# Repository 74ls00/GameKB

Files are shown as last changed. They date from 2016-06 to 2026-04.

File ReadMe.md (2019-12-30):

[Форум проекта](https://forum.geekboards.ru/viewtopic.php?t=13140)

------------------------------------------------------------------------------------

Easy AVR USB Keyboard Firmware Keymapper 
прошивка и графический конфигурфтор клавиш.

https://github.com/74ls00/GameKB_fw

Полная версия клавиатуры.
  
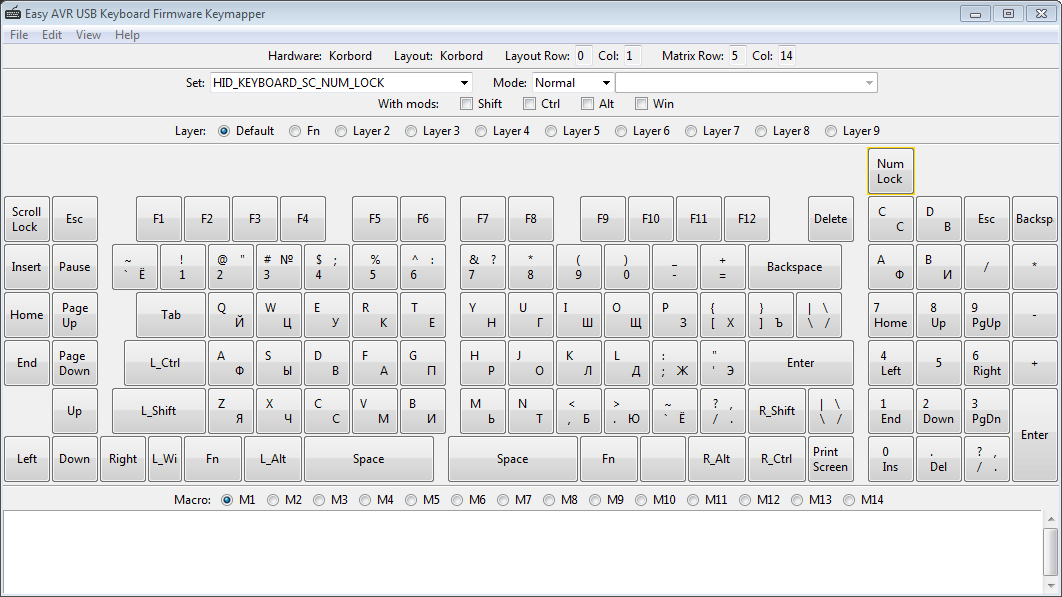
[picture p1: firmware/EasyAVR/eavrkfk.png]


------------------------------------------------------------------------------------

tmk_keyboard \keyboard\korbord прошивка контролера 6KRO, готов только нумпад.

https://github.com/74ls00/GameKB_tmk

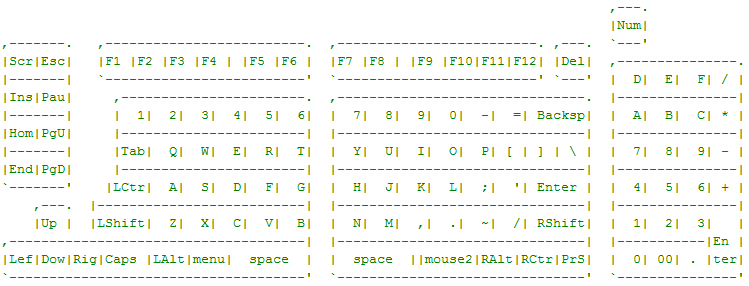
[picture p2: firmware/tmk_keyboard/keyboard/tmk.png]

------------------------------------------------------------------------------------

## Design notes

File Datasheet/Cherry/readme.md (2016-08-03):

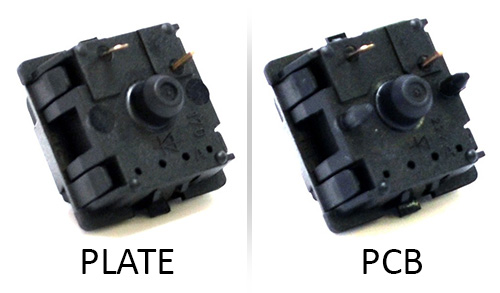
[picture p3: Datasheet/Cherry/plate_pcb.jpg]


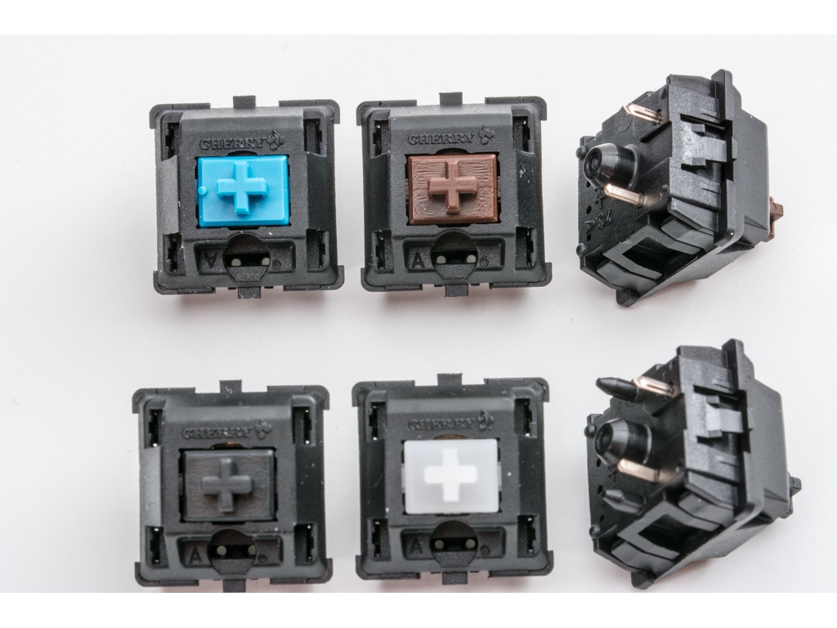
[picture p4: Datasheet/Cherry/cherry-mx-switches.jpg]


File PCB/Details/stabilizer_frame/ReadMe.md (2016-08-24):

Планка крепления Costar стабилизатора.

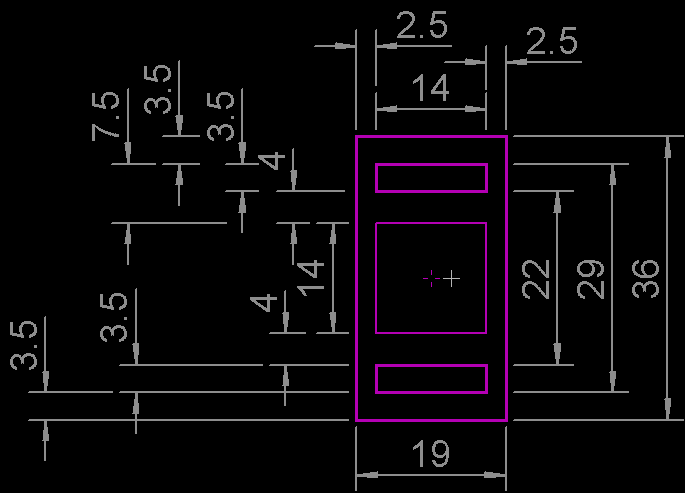
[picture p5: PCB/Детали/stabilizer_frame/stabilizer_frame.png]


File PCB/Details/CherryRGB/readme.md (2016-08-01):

### Модификация переключателя Cherry MX для RGB светодиода.
-----------------------------------------------------------
Снять крышку.

Высверлить углы (жёлтая точка).

Вырезать маленьким ножом для бумаге сначала снаружи, потом перерезав перемычку вы резать через просверленные отверстия(по оранжевой линии).

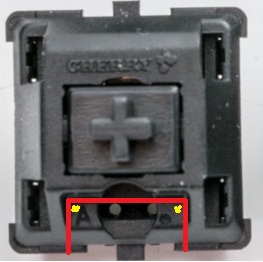
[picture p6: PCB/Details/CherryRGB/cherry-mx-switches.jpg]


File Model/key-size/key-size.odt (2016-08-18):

Ряды | Размеры | 1 x 1 | 1 x 1.25 | 1x1.5 | 1 x 1.75 | 1 x 2 | 1x2.25 | 1x2.75 | 1x6.25 | 2 x 1

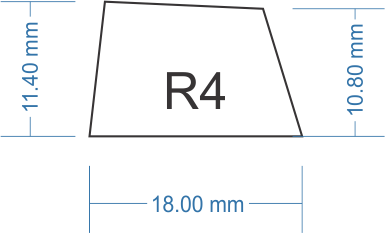
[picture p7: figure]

| | Esc F1-F12 PrtScr ScrLck Break ~ - = 1 2 3 4 5 6 7 8 9 0 Insert Home PgUp NumLock Num/ Num * Num- | | | | Backspace

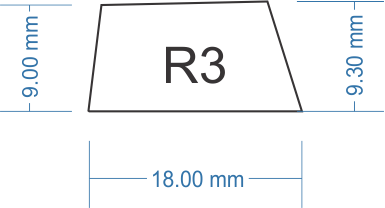
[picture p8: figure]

| | Q W E R T Y U I O P { } Del End PgDn Num7 Num8 Num9 | | Tab \ | | | | | | Num+

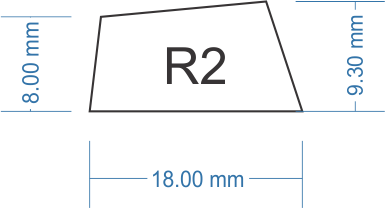
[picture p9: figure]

| | A S D F G H J K L ; ' Num4 Num5 Num6 Num. | | | CapsLock | | Enter

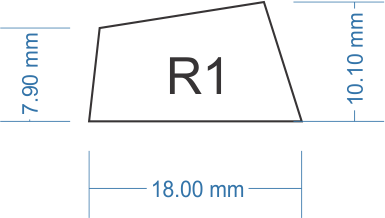
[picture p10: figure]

| | Z X C V B N M , . / Up Left Right Down Num1 Num2 Num3 | Ctrl Win Alt noWin Fn | | | Num0 | LShift | RShift | | Num_Enter
| | | | | | | | | Space

(красный10 голубой1)

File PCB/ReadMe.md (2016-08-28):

NumPad-MUSB - плата нумпада . завершено.

keyBoard_B - правая плата . завершено.

keyBoard_A_GPad - левая плата

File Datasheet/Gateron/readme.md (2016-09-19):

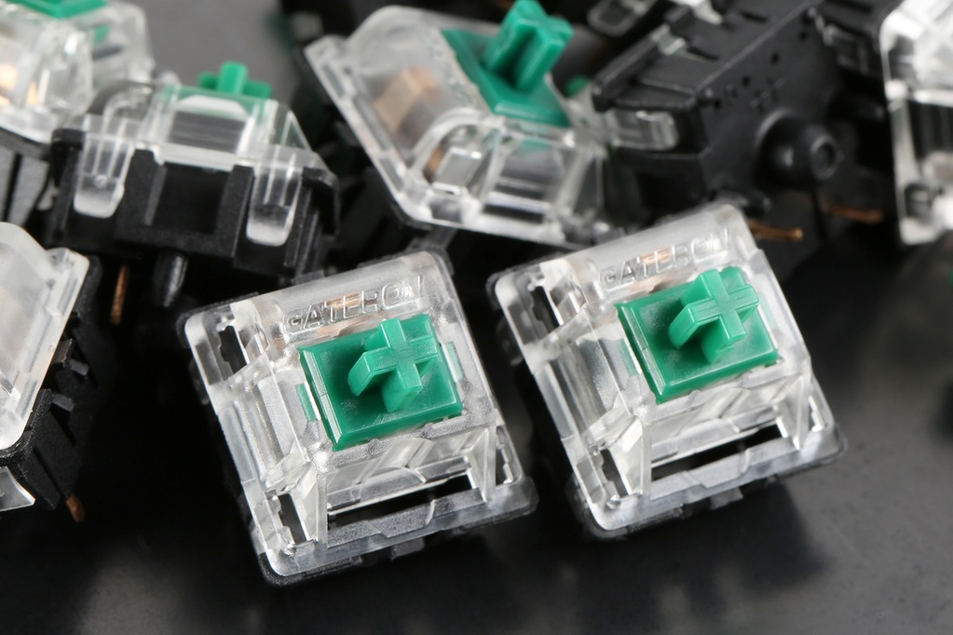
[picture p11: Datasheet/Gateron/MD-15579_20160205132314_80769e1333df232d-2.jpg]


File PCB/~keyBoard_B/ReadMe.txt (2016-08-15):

разводка завершена, остались корректировки.
отверстия есть.
таблица готова в корне help.py

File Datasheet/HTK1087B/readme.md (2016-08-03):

Схема подключения контролера HTK1087B

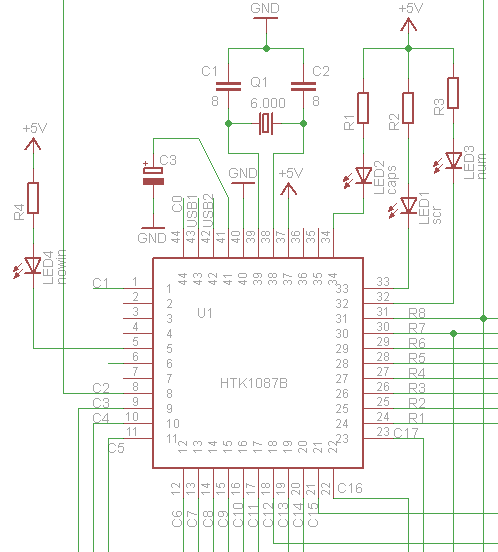
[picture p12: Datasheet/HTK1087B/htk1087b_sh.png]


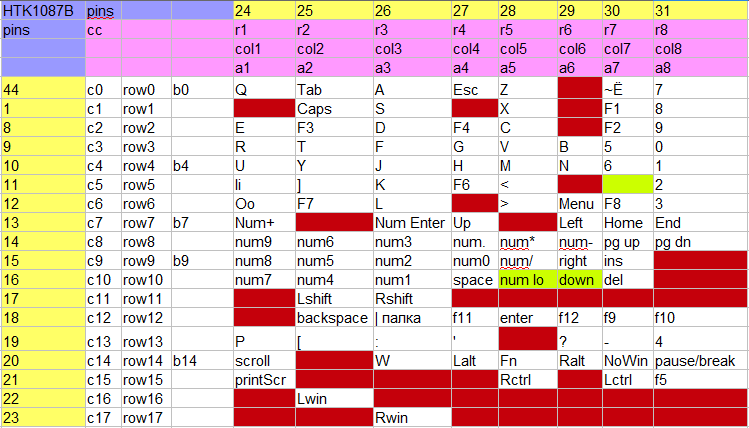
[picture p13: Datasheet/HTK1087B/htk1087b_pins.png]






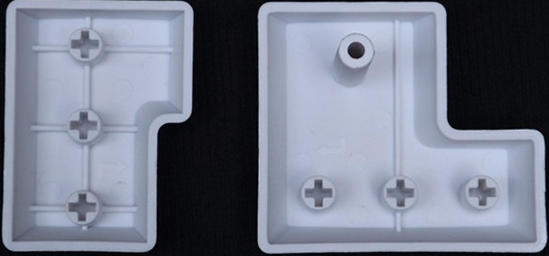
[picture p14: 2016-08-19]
PCB/Details/enter/b.bmp

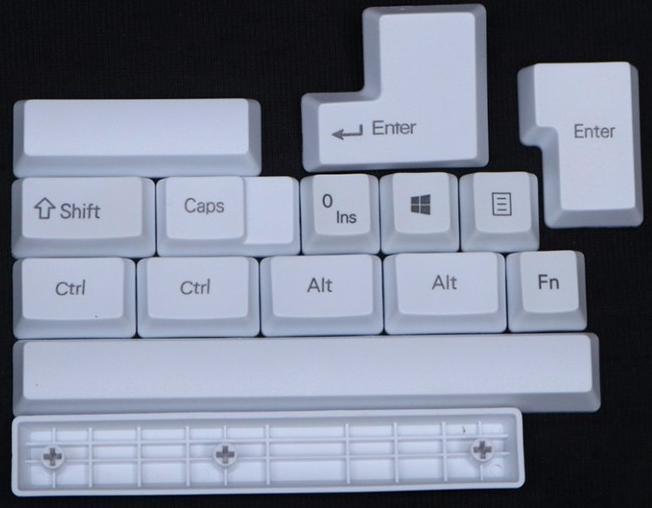
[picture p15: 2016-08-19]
PCB/Details/enter/t.bmp

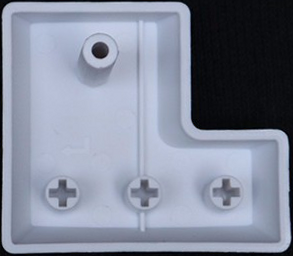
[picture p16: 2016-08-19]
PCB/Детали/enter/b1.bmp

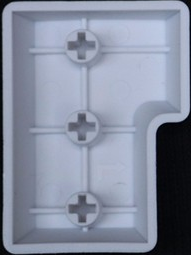
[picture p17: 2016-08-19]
PCB/Детали/enter/b0.bmp

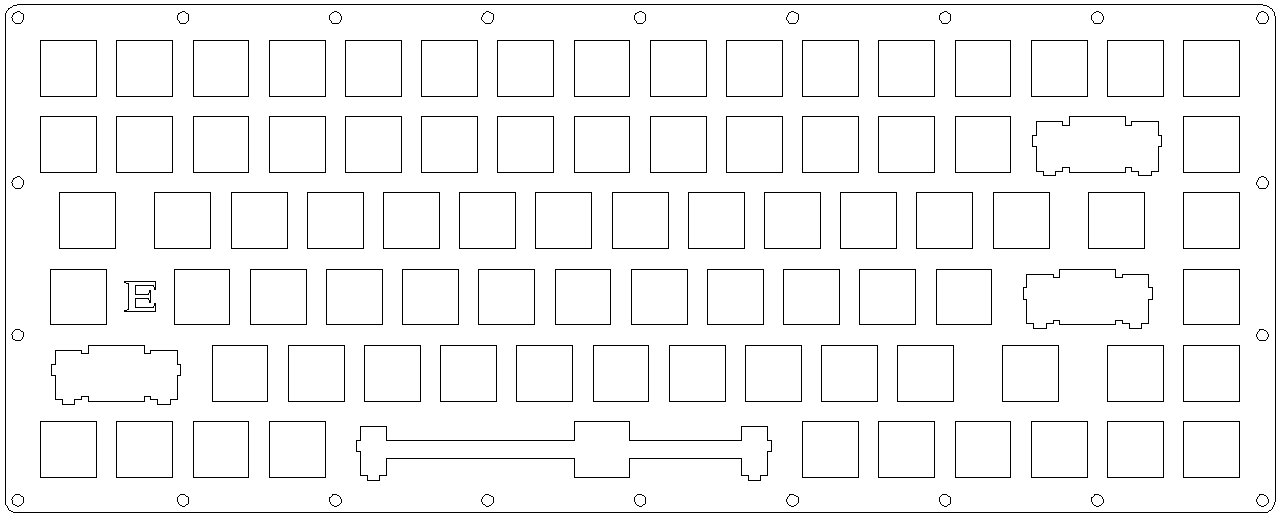
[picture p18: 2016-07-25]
PCB/Детали/frame/UQaYK0l.bmp

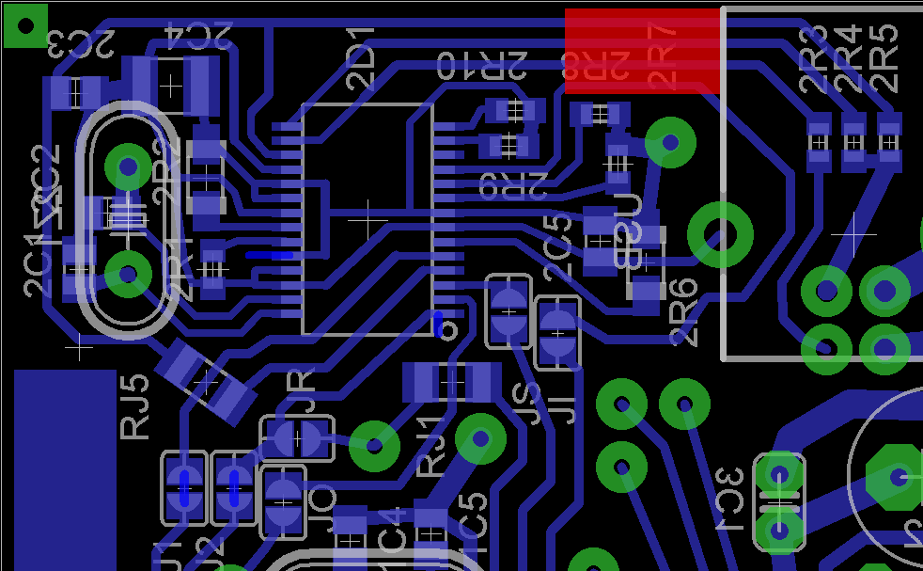
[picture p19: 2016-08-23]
PCB/Controller/png/1_cr.png2.png

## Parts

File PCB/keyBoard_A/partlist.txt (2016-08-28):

Partlist

Exported from keyBoard_A.brd at 2016-08-28 15:22:43

EAGLE Version 6.3.0 Copyright (c) 1988-2012 CadSoft

Assembly variant: 

Part     Value          Package      Library     Position (mil)        Orientation

1D1      74HC138N       DIL16        detali_main (6725 4350)           R0
1D2      74HC04N        DIL14        detali_main (1775 1650)           R90
C17      100n           C0805        rcl         (6775 4312.5)         MR90
C18      100n           C0805        rcl         (1725 1362.5)         MR270
D1       LL4148         SOD80C       detali      (1800 4550)           R270
D2       LL4148         SOD80C       detali      (2725 4625)           R270
D3       LL4148         SOD80C       detali      (1412.5 4287.5)       R90
D4       LL4148         SOD80C       detali      (2112.5 4250)         R0
D5       LL4148         SOD80C       detali      (1950 3525)           R90
D6       LL4148         SOD80C       detali      (2525 3075)           R0
D7       LL4148         SOD80C       detali      (2000 2750)           R90
D8       LL4148         SOD80C       detali      (2750 2775)           R90
D9       LL4148         SOD80C       detali      (2850 1850)           R90
D10      LL4148         SOD80C       detali      (1437.5 1462.5)       R90
D11      LL4148         SOD80C       detali      (2912.5 1562.5)       R0
D12      LL4148         SOD80C       detali      (4525 1375)           R0
D13      LL4148         SOD80C       detali      (4512.5 4450)         R270
D14      LL4148         SOD80C       detali      (4775 4568.625)       R270
D15      LL4148         SOD80C       detali      (5512.5 4575)         R270
D16      LL4148         SOD80C       detali      (6225 4600)           R225
D17      LL4148         SOD80C       detali      (7300 4537.5)         R270
D18      LL4148         SOD80C       detali      (7812.5 4487.5)       R180
D19      LL4148         SOD80C       detali      (4512.5 4000)         R90
D20      LL4148         SOD80C       detali      (5237.5 3987.5)       R90
D21      LL4148         SOD80C       detali      (6075 3950)           R0
D22      LL4148         SOD80C       detali      (6850 3962.5)         R0
D23      LL4148         SOD80C       detali      (7443.75 3987.5)      R90
D24      LL4148         SOD80C       detali      (7612.5 3962.5)       R180
D25      LL4148         SOD80C       detali      (4325 3237.5)         R90
D26      LL4148         SOD80C       detali      (5250 3200)           R90
D27      LL4148         SOD80C       detali      (6000 3200)           R90
D28      LL4148         SOD80C       detali      (6750 3200)           R90
D29      LL4148         SOD80C       detali      (7500 3225)           R90
D30      LL4148         SOD80C       detali      (8037.5 2700)         R0
D31      LL4148         SOD80C       detali      (4225 2475)           R90
D32      LL4148         SOD80C       detali      (5250 2450)           R90
D33      LL4148         SOD80C       detali      (6000 2450)           R90
D34      LL4148         SOD80C       detali      (6750 2450)           R90
D35      LL4148         SOD80C       detali      (7500 2475)           R90
D36      LL4148         SOD80C       detali      (8037.5 1950)         R0
D37      LL4148         SOD80C       detali      (3225 1943.75)        R90
D38      LL4148         SOD80C       detali      (4537.5 1650)         R180
D39      LL4148         SOD80C       detali      (5275 1700)           R180
D40      LL4148         SOD80C       detali      (6087.5 1700)         R90
D41      LL4148         SOD80C       detali      (6850 1700)           R90
D42      LL4148         SOD80C       detali      (7537.5 1475)         R180
D43      LL4148         SOD80C       detali      (5275 1462.5)         R90
D44      LL4148         SOD80C       detali      (6568.75 1250)        R90
D45      LL4148         SOD80C       detali      (7325 1250)           R90
D46      LL4148         SOD80C       detali      (7362.5 906.25)       R90
D47      LL4148         SOD80C       detali      (1800 1225)           R0
D48      LL4148         SOD80C       detali      (1587.5 1206.25)      R0
D88      LL4148         SOD80C       detali      (3787.5 3987.5)       R0
J1       J              R1206W       detali_main (7812.5 4350)         R90
J2       J              R1206W       detali_main (7325 2750)           R90
J3       J              R1206W       detali_main (7350 2025)           R270
J4       J              R1206W       detali_main (6575 3525)           R270
J5       J              R1206W       detali_main (6562.5 2750)         R90
J6       J              R1206W       detali_main (6587.5 2025)         R270
J7       J              R1206W       detali_main (5337.5 3712.5)       R270
J8       J              R1206W       detali_main (5825 2750)           R90
J9       J              R1206W       detali_main (5850 2025)           R90
J10      J              R1206W       detali_main (4312.5 3525)         R270
J11      J              R1206W       detali_main (5075 2750)           R90
J12      J              R1206W       detali_main (5100 2025)           R90
J13      J              R1206W       detali_main (3912.5 3525)         R270
J14      J              R1206W       detali_main (4225 2750)           R90
J15      J              R1206W       detali_main (4250 2025)           R90
J16      J              R1206W       detali_main (2450 3775)           R270
J17      J              R1206W       detali_main (2687.5 2975)         R90
J18      J              R1206W       detali_main (1687.5 2237.5)       R90
J19      J              R1206W       detali_main (1737.5 3787.5)       R315
J20      J              R1206W       detali_main (1812.5 3050)         R90
J21      J              R1206W       detali_main (1450 2975)           R0
J22      J              R1206W       detali_main (5325 4137.5)         R0
J23      J              R1206W       detali_main (2600 2350)           R0
J24      J              R1206W       detali_main (6162.5 4475)         R180
J25      J              R1206W       detali_main (5325 4437.5)         R180
J26      J              R1206W       detali_main (6650 4925)           R90
J27      J              R1206W       detali_main (6212.5 4200)         R0
J28      J              R1206W       detali_main (6212.5 4287.5)       R0
J29      J              R1206W       detali_main (6162.5 4387.5)       R0
J30      J              R1206W       detali_main (5325 4237.5)         R0
J31      J              R1206W       detali_main (5325 4337.5)         R0
J32      J              R1206W       detali_main (2062.5 4750)         R270
J33      J              R1206W       detali_main (2825 4625)           R270
J34      J              R1206W       detali_main (3487.5 5075)         R270
J35      J              R1206W       detali_main (4687.5 4162.5)       R0
J36      J              R1206W       detali_main (4687.5 4250)         R0
J37      J              R1206W       detali_main (4687.5 4337.5)       R0
J38      J              R1206W       detali_main (3937.5 4187.5)       R0
J39      J              R1206W       detali_main (3937.5 4287.5)       R0
J40      J              R1206W       detali_main (3937.5 4387.5)       R0
J41      J              R1206W       detali_main (6762.5 4925)         R90
J42      J              R1206W       detali_main (1387.5 3237.5)       R180
J43      J              R1206W       detali_main (6537.5 4925)         R90
J44      J              R1206W       detali_main (2037.5 900)          R90
J45      J              R1206W       detali_main (1450 3062.5)         R180
J46      J              R1206W       detali_main (2850 2412.5)         R0
J47      J              R1206W       detali_main (3800 3525)           R90
J48      J              R1206W       detali_main (2637.5 4525)         R135
J49      J              R1206W       detali_main (2025 3987.5)         R270
J50      J              R1206W       detali_main (2600 2262.5)         R0
J51      J              R1206W       detali_main (2850 2312.5)         R0
J52      J              R1206W       detali_main (2600 2175)           R0
J53      J              R1206W       detali_main (2850 2212.5)         R0
J54      J              R1206W       detali_main (2600 2087.5)         R0
J55      J              R1206W       detali_main (2850 2112.5)         R0
J56      J              R1206W       detali_main (2600 2000)           R0
J57      J              R1206W       detali_main (2850 2012.5)         R0
JA1                     SJ           detali_main (1462.5 4575)         R90
JA2                     SJ           detali_main (2450 4625)           R90
JA3                     SJ           detali_main (1825 3875)           R90
JA4                     SJ           detali_main (2575 3875)           R90
JA5                     SJ           detali_main (1675 3075)           R90
JA6                     SJ           detali_main (2200 3262.5)         R0
JA7                     SJ           detali_main (1587.5 2275)         R90
JA8                     SJ           detali_main (2175 2475)           R0
JA9                     SJ           detali_main (2187.5 1450)         R0
JA10                    SJ           detali_main (1912.5 600)          R180
JA11                    SJ           detali_main (2450 550)            R90
JA12                    SJ           detali_main (3200 550)            R90
JA13                    SJ           detali      (3900 4600)           R90
JA14                    SJ           detali      (4650 4600)           R90
JA15                    SJ           detali      (5125 4750)           R0
JA16                    SJ           detali      (5850 4700)           R0
JA17                    SJ           detali      (6900 4725)           R0
JA18                    SJ           detali      (7675 4750)           R0
JA19                    SJ           detali      (4200 3550)           R90
JA20                    SJ           detali      (4950 3550)           R90
JA21                    SJ           detali      (5700 3550)           R90
JA22                    SJ           detali      (6425 3500)           R90
JA23                    SJ           detali      (6925 3675)           R0
JA24                    SJ           detali      (8075 3562.5)         R90
JA25                    SJ           detali      (4000 2775)           R90
JA26                    SJ           detali      (4950 2775)           R90
JA27                    SJ           detali      (5675 2775)           R90
JA28                    SJ           detali      (6425 2775)           R90
JA29                    SJ           detali      (7200 2775)           R90
JA30                    SJ           detali      (7775 2700)           R90
JA31                    SJ           detali      (3900 2050)           R90
JA32                    SJ           detali      (4950 2050)           R90
JA33                    SJ           detali      (5700 2050)           R90
JA34                    SJ           detali      (6450 2050)           R90
JA35                    SJ           detali      (7200 2050)           R90
JA36                    SJ           detali      (7762.5 1975)         R90
JA37                    SJ           detali      (3950 1337.5)         R90
JA38                    SJ           detali      (4975 1362.5)         R90
JA39                    SJ           detali      (5787.5 1300)         R90
JA40                    SJ           detali      (6475 1362.5)         R90
JA41                    SJ           detali      (7225 1362.5)         R90
JA42                    SJ           detali      (7975 1350)           R45
JA43                    SJ           detali_main (3962.5 550)          R90
JA44                    SJ           detali      (4350 543.75)         R90
JA45                    SJ           detali      (5575 543.75)         R90
JA46                    SJ           detali      (6812.5 562.5)        R90
JA88                    SJ           detali      (3362.5 3475)         R90
JB1                     SJ           detali      (1725 4650)           R270
JB2                     SJ           jumper      (2725 4800)           MR0
JB3                     SJ           detali      (1437.5 4012.5)       R180
JB4                     SJ           detali_main (2187.5 4012.5)       R135
JB5                     SJ           jumper      (2000 3350)           MR270
JB6                     SJ           detali_main (2487.5 3162.5)       R180
JB7                     SJ           detali_main (2000 2587.5)         R90
JB8                     SJ           detali_main (2750 2562.5)         R90
JB9                     SJ           detali_main (2750 1550)           R90
JB10                    SJ           detali_main (1437.5 712.5)        R180
JB11                    SJ           detali_main (2725 725)            R0
JB12                    SJ           detali_main (3475 725)            R0
JB13                    SJ           detali_main (4175 4775)           R0
JB14                    SJ           jumper      (4925 4800)           MR0
JB15                    SJ           jumper      (5675 4775)           MR0
JB16                    SJ           detali_main (6375 4675)           R270
JB17                    SJ           detali_main (7225 4650)           R270
JB18                    SJ           detali      (8000 4637.5)         R270
JB19                    SJ           detali      (4500 3800)           R90
JB20                    SJ           detali      (5237.5 3812.5)       R90
JB21                    SJ           detali      (6000 3800)           R90
JB22                    SJ           detali      (6750 3850)           R90
JB23                    SJ           detali      (7487.5 3762.5)       R90
JB24                    SJ           detali      (7687.5 3662.5)       R90
JB25                    SJ           detali      (4325 3025)           R90
JB26                    SJ           detali      (5250 3025)           R90
JB27                    SJ           detali      (6000 3025)           R90
JB28                    SJ           detali      (6750 3025)           R90
JB29                    SJ           detali      (7500 3050)           R90
JB30                    SJ           detali      (7987.5 2850)         R270
JB31                    SJ           detali      (4225 2300)           R90
JB32                    SJ           detali      (5250 2275)           R90
JB33                    SJ           detali      (6000 2275)           R90
JB34                    SJ           detali      (6750 2275)           R90
JB35                    SJ           detali      (7500 2300)           R90
JB36                    SJ           detali      (7987.5 2087.5)       R270
JB37                    SJ           detali      (3537.5 1287.5)       R180
JB38                    SJ           detali      (4687.5 1462.5)       R180
JB39                    SJ           detali      (5437.5 1462.5)       R180
JB40                    SJ           detali      (6087.5 1512.5)       R90
JB41                    SJ           detali      (6850 1525)           R90
JB42                    SJ           detali      (7700 1437.5)         R90
JB43                    SJ           detali      (4237.5 725)          R0
JB44                    SJ           detali      (5000 725)            R0
JB45                    SJ           detali      (5850 725)            R0
JB46                    SJ           detali      (7362.5 737.5)        R90
JB88                    SJ           detali      (3725 3725)           R0
R1                      R1206W       rcl         (7075 4312.5)         MR0
R2       10k            R1206W       rcl         (2862.5 4312.5)       MR270
R3       10k            R1206W       rcl         (2050 1350)           MR90
R4       10k            R0805        rcl         (1812.5 1337.5)       MR90
R5       10k            R1206W       rcl         (2037.5 1112.5)       MR225
R6       10k            R1206W       rcl         (2050 1550)           MR90
R7       10k            R1206W       rcl         (1525 1450)           MR90
R8       10k            R0805        rcl         (3331.25 2150)        MR90
S1       Scroll Lock    CHERRY-MX-4P cherrymx    (1675 4875)           R180
S2       ESC            CHERRY-MX-4P cherrymx    (2425 4875)           R180
S3       Ins            CHERRY-MX-4P cherrymx    (1675 4125)           R180
S4       Pause          CHERRY-MX-4P cherrymx    (2425 4125)           R180
S5       Home           CHERRY-MX-4P cherrymx    (1675 3375)           R180
S6       PageUp         CHERRY-MX-4P cherrymx    (2425 3375)           R180
S7       End            CHERRY-MX-4P cherrymx    (1675 2625)           R180
S8       PageDown       CHERRY-MX-4P cherrymx    (2425 2625)           R180
S9       Up             CHERRY-MX-4P cherrymx    (2425 1575)           R180
S10      Left           CHERRY-MX-4P cherrymx    (1675 825)            R180
S11      Down           CHERRY-MX-4P cherrymx    (2425 825)            R180
S12      Right          CHERRY-MX-4P cherrymx    (3175 825)            R180
S13      F1             CHERRY-MX-4P cherrymx    (3875 4875)           R180
S14      F2             CHERRY-MX-4P cherrymx    (4625 4875)           R180
S15      F3             CHERRY-MX-4P cherrymx    (5375 4875)           R180
S16      F4             CHERRY-MX-4P cherrymx    (6125 4875)           R180
S17      F5             CHERRY-MX-4P cherrymx    (7175 4875)           R180
S18      F6             CHERRY-MX-4P cherrymx    (7925 4875)           R180
S19      1              CHERRY-MX-4P cherrymx    (4175 3825)           R180
S20      2              CHERRY-MX-4P cherrymx    (4925 3825)           R180
S21      3              CHERRY-MX-4P cherrymx    (5675 3825)           R180
S22      4              CHERRY-MX-4P cherrymx    (6425 3825)           R180
S23      5              CHERRY-MX-4P cherrymx    (7175 3825)           R180
S24      6              CHERRY-MX-4P cherrymx    (7925 3825)           R180
S25      TAB            CHERRY-MX-4P cherrymx    (3975 3075)           R180
S26      Q              CHERRY-MX-4P cherrymx    (4925 3075)           R180
S27      W              CHERRY-MX-4P cherrymx    (5675 3075)           R180
S28      E              CHERRY-MX-4P cherrymx    (6425 3075)           R180
S29      R              CHERRY-MX-4P cherrymx    (7175 3075)           R180
S30      T              CHERRY-MX-4P cherrymx    (7925 3075)           R180
S31      LCtrl          CHERRY-MX-4P cherrymx    (3875 2325)           R180
S32      A              CHERRY-MX-4P cherrymx    (4925 2325)           R180
S33      S              CHERRY-MX-4P cherrymx    (5675 2325)           R180
S34      D              CHERRY-MX-4P cherrymx    (6425 2325)           R180
S35      F              CHERRY-MX-4P cherrymx    (7175 2325)           R180
S36      G              CHERRY-MX-4P cherrymx    (7925 2325)           R180
S37      L Shift        CHERRY-MX-4P cherrymx    (3800 1575)           R180
S38      Z              CHERRY-MX-4P cherrymx    (4925 1575)           R180
S39      X              CHERRY-MX-4P cherrymx    (5675 1575)           R180
S40      C              CHERRY-MX-4P cherrymx    (6425 1575)           R180
S41      V              CHERRY-MX-4P cherrymx    (7175 1575)           R180
S42      B              CHERRY-MX-4P cherrymx    (7925 1575)           R180
S43      Caps Lock      CHERRY-MX-4P cherrymx    (3937.5 825)          R180
S44      FN1            CHERRY-MX-4P cherrymx    (4700 825)            R180
S44A     Fn1            CHERRY-MX    cherrymx    (4587.5 825)          R180
S45      L_Alt          CHERRY-MX-4P cherrymx    (5537.5 825)          R180
S46      Space          CHERRY-MX-4P cherrymx    (7050 825)            R180
S88      ~?             CHERRY-MX-4P cherrymx    (3425 3825)           R180
SV1                     FE03-1       detali_main (3543.75 4331.25)     R90
SV3                     FE08         detali_main (3043.75 3881.25)     R90

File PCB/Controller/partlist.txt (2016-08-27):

Partlist

Exported from keyBoard_A.brd at 2016-08-28 1:44:59

EAGLE Version 6.3.0 Copyright (c) 1988-2012 CadSoft

Assembly variant: 

Part     Value          Package      Library     Position (mil)        Orientation

1D1      74HC138N       DIL16        detali_main (6600 5150)           R0
1D2      74HC04N        DIL14        detali_main (1650 2450)           R90
C17      100n           C0805        rcl         (6650 5112.5)         MR90
C18      100n           C0805        rcl         (1600 2162.5)         MR270
D1       LL4148         SOD80C       detali      (1675 5350)           R270
D2       LL4148         SOD80C       detali      (2600 5425)           R270
D3       LL4148         SOD80C       detali      (1287.5 5087.5)       R90
D4       LL4148         SOD80C       detali      (1987.5 5050)         R0
D5       LL4148         SOD80C       detali      (1825 4325)           R90
D6       LL4148         SOD80C       detali      (2400 3875)           R0
D7       LL4148         SOD80C       detali      (1875 3550)           R90
D8       LL4148         SOD80C       detali      (2625 3575)           R90
D9       LL4148         SOD80C       detali      (2725 2650)           R90
D10      LL4148         SOD80C       detali      (1287.5 2350)         R90
D11      LL4148         SOD80C       detali      (2787.5 2362.5)       R0
D12      LL4148         SOD80C       detali      (4400 2175)           R0
D13      LL4148         SOD80C       detali      (4387.5 5250)         R270
D14      LL4148         SOD80C       detali      (4650 5368.625)       R270
D15      LL4148         SOD80C       detali      (5387.5 5375)         R270
D16      LL4148         SOD80C       detali      (6100 5400)           R225
D17      LL4148         SOD80C       detali      (7175 5337.5)         R270
D18      LL4148         SOD80C       detali      (7687.5 5275)         R180
D19      LL4148         SOD80C       detali      (4387.5 4800)         R90
D20      LL4148         SOD80C       detali      (5112.5 4787.5)       R90
D21      LL4148         SOD80C       detali      (5950 4750)           R0
D22      LL4148         SOD80C       detali      (6725 4762.5)         R0
D23      LL4148         SOD80C       detali      (7312.5 4762.5)       R90
D24      LL4148         SOD80C       detali      (7487.5 4762.5)       R180
D25      LL4148         SOD80C       detali      (4200 4037.5)         R90
D26      LL4148         SOD80C       detali      (5125 4000)           R90
D27      LL4148         SOD80C       detali      (5875 4000)           R90
D28      LL4148         SOD80C       detali      (6625 4000)           R90
D29      LL4148         SOD80C       detali      (7375 4025)           R90
D30      LL4148         SOD80C       detali      (7912.5 3500)         R0
D31      LL4148         SOD80C       detali      (4100 3275)           R90
D32      LL4148         SOD80C       detali      (5125 3250)           R90
D33      LL4148         SOD80C       detali      (5875 3250)           R90
D34      LL4148         SOD80C       detali      (6625 3250)           R90
D35      LL4148         SOD80C       detali      (7375 3275)           R90
D36      LL4148         SOD80C       detali      (7912.5 2750)         R0
D37      LL4148         SOD80C       detali      (3100 2743.75)        R90
D38      LL4148         SOD80C       detali      (4412.5 2450)         R180
D39      LL4148         SOD80C       detali      (5150 2500)           R180
D40      LL4148         SOD80C       detali      (5962.5 2500)         R90
D41      LL4148         SOD80C       detali      (6725 2500)           R90
D42      LL4148         SOD80C       detali      (7412.5 2275)         R180
D43      LL4148         SOD80C       detali      (5150 2262.5)         R90
D44      LL4148         SOD80C       detali      (6443.75 2050)        R90
D45      LL4148         SOD80C       detali      (7200 2050)           R90
D46      LL4148         SOD80C       detali      (7237.5 1675)         R90
D47      LL4148         SOD80C       detali      (1337.5 2062.5)       R0
D48      LL4148         SOD80C       detali      (1337.5 2150)         R180
D88      LL4148         SOD80C       detali      (3662.5 4787.5)       R0
J1       J              R1206W       detali_main (7687.5 5150)         R90
J2       J              R1206W       detali_main (7200 3550)           R90
J3       J              R1206W       detali_main (7225 2825)           R270
J4       J              R1206W       detali_main (6450 4325)           R270
J5       J              R1206W       detali_main (6437.5 3550)         R90
J6       J              R1206W       detali_main (6462.5 2825)         R270
J7       J              R1206W       detali_main (5212.5 4512.5)       R270
J8       J              R1206W       detali_main (5700 3550)           R90
J9       J              R1206W       detali_main (5725 2825)           R90
J10      J              R1206W       detali_main (4187.5 4325)         R270
J11      J              R1206W       detali_main (4950 3550)           R90
J12      J              R1206W       detali_main (4975 2825)           R90
J13      J              R1206W       detali_main (3787.5 4325)         R270
J14      J              R1206W       detali_main (4100 3550)           R90
J15      J              R1206W       detali_main (4125 2825)           R90
J16      J              R1206W       detali_main (2325 4575)           R270
J17      J              R1206W       detali_main (2562.5 3775)         R90
J18      J              R1206W       detali_main (1562.5 3037.5)       R90
J19      J              R1206W       detali_main (1612.5 4587.5)       R315
J20      J              R1206W       detali_main (1687.5 3850)         R90
J21      J              R1206W       detali_main (1325 3775)           R0
J22      J              R1206W       detali_main (5200 4937.5)         R0
J23      J              R1206W       detali_main (2475 3150)           R0
J24      J              R1206W       detali_main (6037.5 5275)         R180
J25      J              R1206W       detali_main (5200 5237.5)         R180
J26      J              R1206W       detali_main (6525 5725)           R90
J27      J              R1206W       detali_main (6100 5012.5)         R0
J28      J              R1206W       detali_main (6087.5 5087.5)       R0
J29      J              R1206W       detali_main (6037.5 5187.5)       R0
J30      J              R1206W       detali_main (5200 5037.5)         R0
J31      J              R1206W       detali_main (5200 5137.5)         R0
J32      J              R1206W       detali_main (1937.5 5550)         R270
J33      J              R1206W       detali_main (2700 5425)           R270
J34      J              R1206W       detali_main (3362.5 5875)         R270
J35      J              R1206W       detali_main (4562.5 4962.5)       R0
J36      J              R1206W       detali_main (4562.5 5050)         R0
J37      J              R1206W       detali_main (4562.5 5137.5)       R0
J38      J              R1206W       detali_main (3812.5 4987.5)       R0
J39      J              R1206W       detali_main (3812.5 5087.5)       R0
J40      J              R1206W       detali_main (3812.5 5187.5)       R0
J41      J              R1206W       detali_main (6637.5 5725)         R90
J42      J              R1206W       detali_main (1262.5 4037.5)       R180
J43      J              R1206W       detali_main (6412.5 5725)         R90
J44      J              R1206W       detali_main (1337.5 1975)         R0
J45      J              R1206W       detali_main (1325 3862.5)         R180
J46      J              R1206W       detali_main (2725 3212.5)         R0
J47      J              R1206W       detali_main (3675 4325)           R90
J48      J              R1206W       detali_main (2512.5 5325)         R135
J49      J              R1206W       detali_main (1900 4787.5)         R270
J50      J              R1206W       detali_main (2475 3062.5)         R0
J51      J              R1206W       detali_main (2725 3112.5)         R0
J52      J              R1206W       detali_main (2475 2975)           R0
J53      J              R1206W       detali_main (2725 3012.5)         R0
J54      J              R1206W       detali_main (2475 2887.5)         R0
J55      J              R1206W       detali_main (2725 2912.5)         R0
J56      J              R1206W       detali_main (2475 2800)           R0
J57      J              R1206W       detali_main (2725 2812.5)         R0
JA1                     SJ           detali_main (1337.5 5375)         R90
JA2                     SJ           detali_main (2325 5425)           R90
JA3                     SJ           detali_main (1700 4675)           R90
JA4                     SJ           detali_main (2450 4675)           R90
JA5                     SJ           detali_main (1550 3875)           R90
JA6                     SJ           detali_main (2075 4062.5)         R0
JA7                     SJ           detali_main (1462.5 3075)         R90
JA8                     SJ           detali_main (2050 3275)           R0
JA9                     SJ           detali_main (2062.5 2250)         R0
JA10                    SJ           detali_main (1825 1350)           R90
JA11                    SJ           detali_main (2325 1350)           R90
JA12                    SJ           detali_main (3075 1350)           R90
JA13                    SJ           detali      (3775 5400)           R90
JA14                    SJ           detali      (4525 5400)           R90
JA15                    SJ           detali      (5000 5550)           R0
JA16                    SJ           detali      (5725 5500)           R0
JA17                    SJ           detali      (6775 5525)           R0
JA18                    SJ           detali      (7550 5550)           R0
JA19                    SJ           detali      (4075 4350)           R90
JA20                    SJ           detali      (4825 4350)           R90
JA21                    SJ           detali      (5575 4350)           R90
JA22                    SJ           detali      (6300 4300)           R90
JA23                    SJ           detali      (6800 4475)           R0
JA24                    SJ           detali      (7950 4362.5)         R90
JA25                    SJ           detali      (3875 3575)           R90
JA26                    SJ           detali      (4825 3575)           R90
JA27                    SJ           detali      (5550 3575)           R90
JA28                    SJ           detali      (6300 3575)           R90
JA29                    SJ           detali      (7075 3575)           R90
JA30                    SJ           detali      (7650 3500)           R90
JA31                    SJ           detali      (3775 2850)           R90
JA32                    SJ           detali      (4825 2850)           R90
JA33                    SJ           detali      (5575 2850)           R90
JA34                    SJ           detali      (6325 2850)           R90
JA35                    SJ           detali      (7075 2850)           R90
JA36                    SJ           detali      (7637.5 2775)         R90
JA37                    SJ           detali      (3825 2137.5)         R90
JA38                    SJ           detali      (4850 2162.5)         R90
JA39                    SJ           detali      (5662.5 2100)         R90
JA40                    SJ           detali      (6350 2162.5)         R90
JA41                    SJ           detali      (7100 2162.5)         R90
JA42                    SJ           detali      (7850 2150)           R45
JA43                    SJ           detali_main (3837.5 1350)         R90
JA44                    SJ           detali      (4225 1350)           R90
JA45                    SJ           detali      (5450 1362.5)         R90
JA46                    SJ           detali      (6687.5 1362.5)       R90
JA88                    SJ           detali      (3337.5 4350)         R90
JB1                     SJ           detali      (1600 5450)           R270
JB2                     SJ           jumper      (2600 5600)           MR0
JB3                     SJ           detali      (1312.5 4812.5)       R180
JB4                     SJ           detali_main (2062.5 4812.5)       R135
JB5                     SJ           jumper      (1875 4150)           MR270
JB6                     SJ           detali_main (2362.5 3962.5)       R180
JB7                     SJ           detali_main (1875 3387.5)         R90
JB8                     SJ           detali_main (2625 3362.5)         R90
JB9                     SJ           detali_main (2625 2350)           R90
JB10                    SJ           detali_main (1312.5 1512.5)       R180
JB11                    SJ           detali_main (2600 1525)           R0
JB12                    SJ           detali_main (3350 1525)           R0
JB13                    SJ           detali_main (4050 5575)           R0
JB14                    SJ           jumper      (4800 5600)           MR0
JB15                    SJ           jumper      (5550 5575)           MR0
JB16                    SJ           detali_main (6250 5475)           R270
JB17                    SJ           detali_main (7100 5450)           R270
JB18                    SJ           detali      (7875 5437.5)         R270
JB19                    SJ           detali      (4375 4600)           R90
JB20                    SJ           detali      (5112.5 4612.5)       R90
JB21                    SJ           detali      (5875 4600)           R90
JB22                    SJ           detali      (6625 4650)           R90
JB23                    SJ           detali      (7362.5 4562.5)       R90
JB24                    SJ           detali      (7562.5 4462.5)       R90
JB25                    SJ           detali      (4200 3825)           R90
JB26                    SJ           detali      (5125 3825)           R90
JB27                    SJ           detali      (5875 3825)           R90
JB28                    SJ           detali      (6625 3825)           R90
JB29                    SJ           detali      (7375 3850)           R90
JB30                    SJ           detali      (7862.5 3650)         R270
JB31                    SJ           detali      (4100 3100)           R90
JB32                    SJ           detali      (5125 3075)           R90
JB33                    SJ           detali      (5875 3075)           R90
JB34                    SJ           detali      (6625 3075)           R90
JB35                    SJ           detali      (7375 3100)           R90
JB36                    SJ           detali      (7862.5 2887.5)       R270
JB37                    SJ           detali      (3437.5 2112.5)       R180
JB38                    SJ           detali      (4562.5 2262.5)       R180
JB39                    SJ           detali      (5312.5 2262.5)       R180
JB40                    SJ           detali      (5962.5 2312.5)       R90
JB41                    SJ           detali      (6725 2325)           R90
JB42                    SJ           detali      (7575 2237.5)         R90
JB43                    SJ           detali      (4112.5 1525)         R0
JB44                    SJ           detali      (4875 1525)           R0
JB45                    SJ           detali      (5725 1525)           R0
JB46                    SJ           detali      (7237.5 1512.5)       R90
JB88                    SJ           detali      (3600 4525)           R0
R1                      R1206W       rcl         (6950 5112.5)         MR0
R2       10k            R1206W       rcl         (2737.5 5112.5)       MR270
R3       10k            0603R        rd          (1912.5 2550)         R90
R4       10k            R0805        rcl         (1687.5 2137.5)       MR90
R5       10k            R1206W       rcl         (1887.5 2050)         MR180
R10      10k            0603R        rd          (1400 2450)           R90
R100     10k            0603R        rd          (1400 2650)           R0
S1       Scroll Lock    CHERRY-MX-4P cherrymx    (1550 5675)           R180
S2       ESC            CHERRY-MX-4P cherrymx    (2300 5675)           R180
S3       Ins            CHERRY-MX-4P cherrymx    (1550 4925)           R180
S4       Pause          CHERRY-MX-4P cherrymx    (2300 4925)           R180
S5       Home           CHERRY-MX-4P cherrymx    (1550 4175)           R180
S6       PageUp         CHERRY-MX-4P cherrymx    (2300 4175)           R180
S7       End            CHERRY-MX-4P cherrymx    (1550 3425)           R180
S8       PageDown       CHERRY-MX-4P cherrymx    (2300 3425)           R180
S9       Up             CHERRY-MX-4P cherrymx    (2300 2375)           R180
S10      Left           CHERRY-MX-4P cherrymx    (1550 1625)           R180
S11      Down           CHERRY-MX-4P cherrymx    (2300 1625)           R180
S12      Right          CHERRY-MX-4P cherrymx    (3050 1625)           R180
S13      F1             CHERRY-MX-4P cherrymx    (3750 5675)           R180
S14      F2             CHERRY-MX-4P cherrymx    (4500 5675)           R180
S15      F3             CHERRY-MX-4P cherrymx    (5250 5675)           R180
S16      F4             CHERRY-MX-4P cherrymx    (6000 5675)           R180
S17      F5             CHERRY-MX-4P cherrymx    (7050 5675)           R180
S18      F6             CHERRY-MX-4P cherrymx    (7800 5675)           R180
S19      1              CHERRY-MX-4P cherrymx    (4050 4625)           R180
S20      2              CHERRY-MX-4P cherrymx    (4800 4625)           R180
S21      3              CHERRY-MX-4P cherrymx    (5550 4625)           R180
S22      4              CHERRY-MX-4P cherrymx    (6300 4625)           R180
S23      5              CHERRY-MX-4P cherrymx    (7050 4625)           R180
S24      6              CHERRY-MX-4P cherrymx    (7800 4625)           R180
S25      TAB            CHERRY-MX-4P cherrymx    (3850 3875)           R180
S26      Q              CHERRY-MX-4P cherrymx    (4800 3875)           R180
S27      W              CHERRY-MX-4P cherrymx    (5550 3875)           R180
S28      E              CHERRY-MX-4P cherrymx    (6300 3875)           R180
S29      R              CHERRY-MX-4P cherrymx    (7050 3875)           R180
S30      T              CHERRY-MX-4P cherrymx    (7800 3875)           R180
S31      LCtrl          CHERRY-MX-4P cherrymx    (3750 3125)           R180
S32      A              CHERRY-MX-4P cherrymx    (4800 3125)           R180
S33      S              CHERRY-MX-4P cherrymx    (5550 3125)           R180
S34      D              CHERRY-MX-4P cherrymx    (6300 3125)           R180
S35      F              CHERRY-MX-4P cherrymx    (7050 3125)           R180
S36      G              CHERRY-MX-4P cherrymx    (7800 3125)           R180
S37      L Shift        CHERRY-MX-4P cherrymx    (3675 2375)           R180
S38      Z              CHERRY-MX-4P cherrymx    (4800 2375)           R180
S39      X              CHERRY-MX-4P cherrymx    (5550 2375)           R180
S40      C              CHERRY-MX-4P cherrymx    (6300 2375)           R180
S41      V              CHERRY-MX-4P cherrymx    (7050 2375)           R180
S42      B              CHERRY-MX-4P cherrymx    (7800 2375)           R180
S43      Caps Lock      CHERRY-MX-4P cherrymx    (3812.5 1625)         R180
S44      FN1            CHERRY-MX-4P cherrymx    (4575 1625)           R180
S44A     Fn1            CHERRY-MX    cherrymx    (4462.5 1625)         R180
S45      L_Alt          CHERRY-MX-4P cherrymx    (5412.5 1625)         R180
S46      Space          CHERRY-MX-4P cherrymx    (6925 1625)           R180
S88      ~?             CHERRY-MX-4P cherrymx    (3300 4625)           R180
SV1                     FE03-1       detali_main (3418.75 5131.25)     R90
SV2                     FE03-1       detali_main (262.5 825)           R0
SV3                     FE08         detali_main (2918.75 4681.25)     R90

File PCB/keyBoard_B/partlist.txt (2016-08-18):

Partlist

Exported from keyBoard_B.sch at 2016-08-18 18:13:36

EAGLE Version 6.3.0 Copyright (c) 1988-2012 CadSoft

Assembly variant: 

Part     Value          Device       Package      Library  Sheet

2C1      100n           C-EUC1206    C1206        rcl      1
2C2      100n           C-EUC1206K   C1206K       rcl      1
2D1      74HC138N       74AC138N     DIL16        detali2  1
2D2      74HC04N        74ALS04N     DIL14        detali2  1
2R1      10k            R-EU_R0805   R0805        rcl      1
2R2      10k            R-EU_R0805   R0805        rcl      1
2R3      10k            R-EU_R0805   R0805        rcl      1
2R4      10k            R-EU_R1206W  R1206W       rcl      1
2R5      10k            R-EU_R0805   R0805        rcl      1
2R6      10k            R-EU_R0805   R0805        rcl      1
D49      LL4148         LL4148       SOD80C       detali   1
D50      LL4148         LL4148       SOD80C       detali   1
D51      LL4148         LL4148       SOD80C       detali   1
D52      LL4148         LL4148       SOD80C       detali   1
D53      LL4148         LL4148       SOD80C       detali   1
D54      LL4148         LL4148       SOD80C       detali   1
D55      LL4148         LL4148       SOD80C       detali   1
D56      LL4148         LL4148       SOD80C       detali   1
D57      LL4148         LL4148       SOD80C       detali   1
D58      LL4148         LL4148       SOD80C       detali   1
D59      LL4148         LL4148       SOD80C       detali   1
D60      LL4148         LL4148       SOD80C       detali   1
D61      LL4148         LL4148       SOD80C       detali   1
D62      LL4148         LL4148       SOD80C       detali   1
D63      LL4148         LL4148       SOD80C       detali   1
D64      LL4148         LL4148       SOD80C       detali   1
D64B     LL4148         LL4148       SOD80C       detali   1
D65      LL4148         LL4148       SOD80C       detali   1
D66      LL4148         LL4148       SOD80C       detali   1
D67      LL4148         LL4148       SOD80C       detali   1
D67B     LL4148         LL4148       SOD80C       detali   1
D68      LL4148         LL4148       SOD80C       detali   1
D69      LL4148         LL4148       SOD80C       detali   1
D70      LL4148         LL4148       SOD80C       detali   1
D71      LL4148         LL4148       SOD80C       detali   1
D72      LL4148         LL4148       SOD80C       detali   1
D73      LL4148         LL4148       SOD80C       detali   1
D74      LL4148         LL4148       SOD80C       detali   1
D75      LL4148         LL4148       SOD80C       detali   1
D76      LL4148         LL4148       SOD80C       detali   1
D77      LL4148         LL4148       SOD80C       detali   1
D78      LL4148         LL4148       SOD80C       detali   1
D79      LL4148         LL4148       SOD80C       detali   1
D80      LL4148         LL4148       SOD80C       detali   1
D81      LL4148         LL4148       SOD80C       detali   1
D82      LL4148         LL4148       SOD80C       detali   1
D83      LL4148         LL4148       SOD80C       detali   1
D84      LL4148         LL4148       SOD80C       detali   1
D85      LL4148         LL4148       SOD80C       detali   1
D86      LL4148         LL4148       SOD80C       detali   1
D87      LL4148         LL4148       SOD80C       detali   1
D88      LL4148         LL4148       SOD80C       detali   1
D89      LL4148         LL4148       SOD80C       detali   1
D92      LL4148         LL4148       SOD80C       detali   1
D93      LL4148         LL4148       SOD80C       detali   1
J46                     J            R1206W       detali2  1
J48                     J            R1206W       detali2  1
J49                     J            R1206W       detali2  1
J50                     J            R1206W       detali2  1
J51                     J            R1206W       detali2  1
J52                     J            R1206W       detali2  1
J53                     J            R1206W       detali2  1
J54                     J            R1206W       detali2  1
J55                     J            R1206W       detali2  1
J56                     J            R1206W       detali2  1
J57                     J            R1206W       detali2  1
J58                     J            R1206W       detali2  1
J59                     J            R1206W       detali2  1
J60                     J            R1206W       detali2  1
J61                     J            R1206W       detali2  1
J62                     J            R1206W       detali2  1
J63                     J            R1206W       detali2  1
J64                     J            R1206W       detali2  1
J65                     J            R1206W       detali2  1
J66                     J            R1206W       detali2  1
J67                     J            R1206W       detali2  1
J68                     J            R1206W       detali2  1
J69                     J            R1206W       detali2  1
J70                     J            R1206W       detali2  1
J71                     J            R1206W       detali2  1
J72                     J            R1206W       detali2  1
J73                     J            R1206W       detali2  1
J74                     J            R1206W       detali2  1
J75                     J            R1206W       detali2  1
J76                     J            R1206W       detali2  1
J77                     J            R1206W       detali2  1
J78                     J            R1206W       detali2  1
J79                     J            R1206W       detali2  1
J80                     J            R1206W       detali2  1
J81                     J            R1206W       detali2  1
J82                     J            R1206W       detali2  1
J83                     J            R1206W       detali2  1
J84                     J            R1206W       detali2  1
J85                     J            R1206W       detali2  1
J86                     J            R1206W       detali2  1
J87                     J            R1206W       detali2  1
J88                     J            R1206W       detali2  1
J89                     J            R1206W       detali2  1
J90                     J            R1206W       detali2  1
J91                     J            R1206W       detali2  1
J92                     J            R1206W       detali2  1
J93                     J            R1206W       detali2  1
J94                     J            R1206W       detali2  1
J95                     J            R1206W       detali2  1
JA47                    SJ           SJ           detali   1
JA48                    SJ           SJ           detali   1
JA49                    SJ           SJ           detali   1
JA50                    SJ           SJ           detali   1
JA51                    SJ           SJ           detali   1
JA52                    SJ           SJ           detali   1
JA53                    SJ           SJ           detali   1
JA54                    SJ           SJ           detali   1
JA55                    SJ           SJ           detali   1
JA56                    SJ           SJ           detali   1
JA57                    SJ           SJ           detali   1
JA58                    SJ           SJ           detali   1
JA59                    SJ           SJ           detali   1
JA60                    SJ           SJ           detali   1
JA61                    SJ           SJ           detali   1
JA62                    SJ           SJ           detali   1
JA63                    SJ           SJ           detali   1
JA64                    SJ           SJ           detali   1
JA65                    SJ           SJ           detali   1
JA66                    SJ           SJ           detali   1
JA67                    SJ           SJ           detali   1
JA67B                   SJ           SJ           detali   1
JA68                    SJ           SJ           detali   1
JA69                    SJ           SJ           detali   1
JA70                    SJ           SJ           detali   1
JA71                    SJ           SJ           detali   1
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

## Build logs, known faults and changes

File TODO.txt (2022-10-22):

2022

центр левого пробела под кнопкой С

2021

общий светодиодов +5в

добавить кнопку HWB для смены прошивки

добавить светодиод reset

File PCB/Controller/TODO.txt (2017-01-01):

кварци и их конденсаторы на нужный слой

переключатель как джампер . isp+vcc vcc+hvpp

добавить резюки питания плат 3

возможно stk500 hvpp 32u4

добавить кнопку сброса програматора

светодиоды rx tx

aref stk к земле?, через 100нф
http://electronix.ru/forum/index.php?showtopic=68372&st=1035

сделать отключение 32у4 от выхода хаба

подключаемость контролера клавиатуры мимо хаба

низ фольга для экрана
засиликонить разъёмы

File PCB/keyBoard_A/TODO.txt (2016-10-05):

определить расположение левого ряда

определить нижний ряд

1. уместить 3 клавиши 1,25 перед пробелом.
курсоры при этом будут сдвинуты влево.
первая верссия платы была более правильной.

----
возможно поменять d1 d3 на обоих платах

перенести элемент с линии 4 на линию 5.
с 3 на 4.
с 2 на 3.
на 2 линию повесить ёльду.
+1 поставить ёльду перед 1
+2 занять 2 свободные линии.

добавить резисторы подтяжки

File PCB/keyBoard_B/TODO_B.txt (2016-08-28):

! откат до 4dd1c1271 D1,D3 сохранено в порядке 3 2 1 

сдвинуть разъём правее крепёжных отверстий между 1 и 2 столбом

проверить плату

? невозможно. добавить 5 конопок на свободные линии

- pin9 pin11 поменяны. поменять в коде

+возможно поставить | справа от шифта

? не подходит . подогнать размер по картинке для большого enter.

- не нужно . сдвинуть |d на центр

- средние крепления должны быть на одном расстоянии от краёв.
проверено. равно 19.05мм

? невозможно. нет данных. убрано по максимуму. убрать детали от стабилизаторов

-подвинуть правый край

- добавить резисторы подтяжки

- ? поменять местами fn2 alt , длинной к пробелу. или убрать мелкую

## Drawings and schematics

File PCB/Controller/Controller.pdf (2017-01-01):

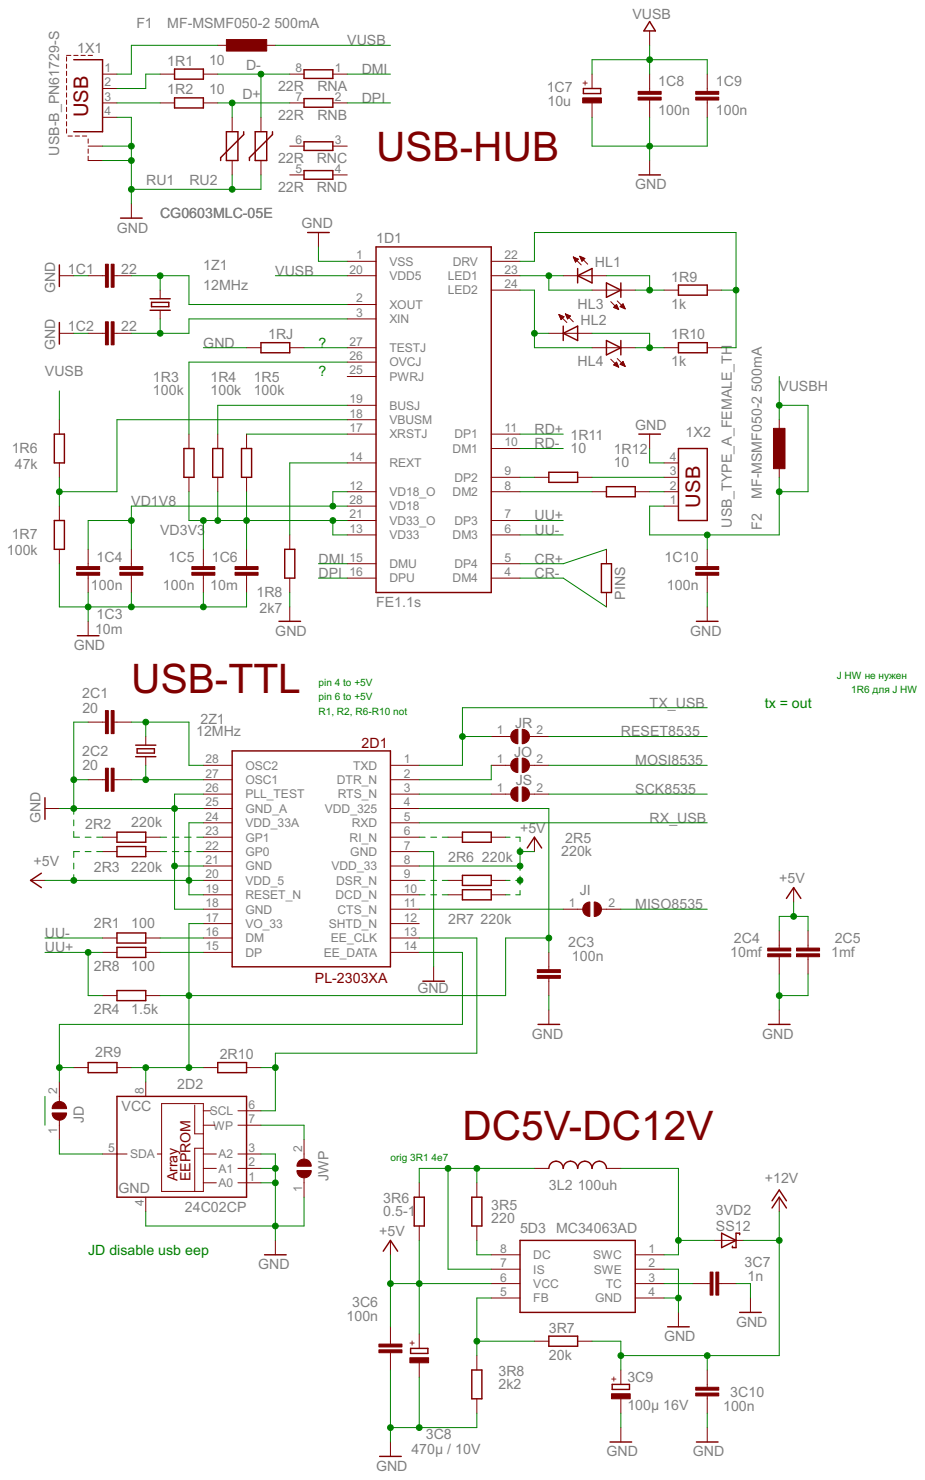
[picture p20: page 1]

J HW не нужен 1R6 для J HW

pin 4 to +5V R1, R2, R6-R10 not pin 6 to +5V

JD disable usb eep

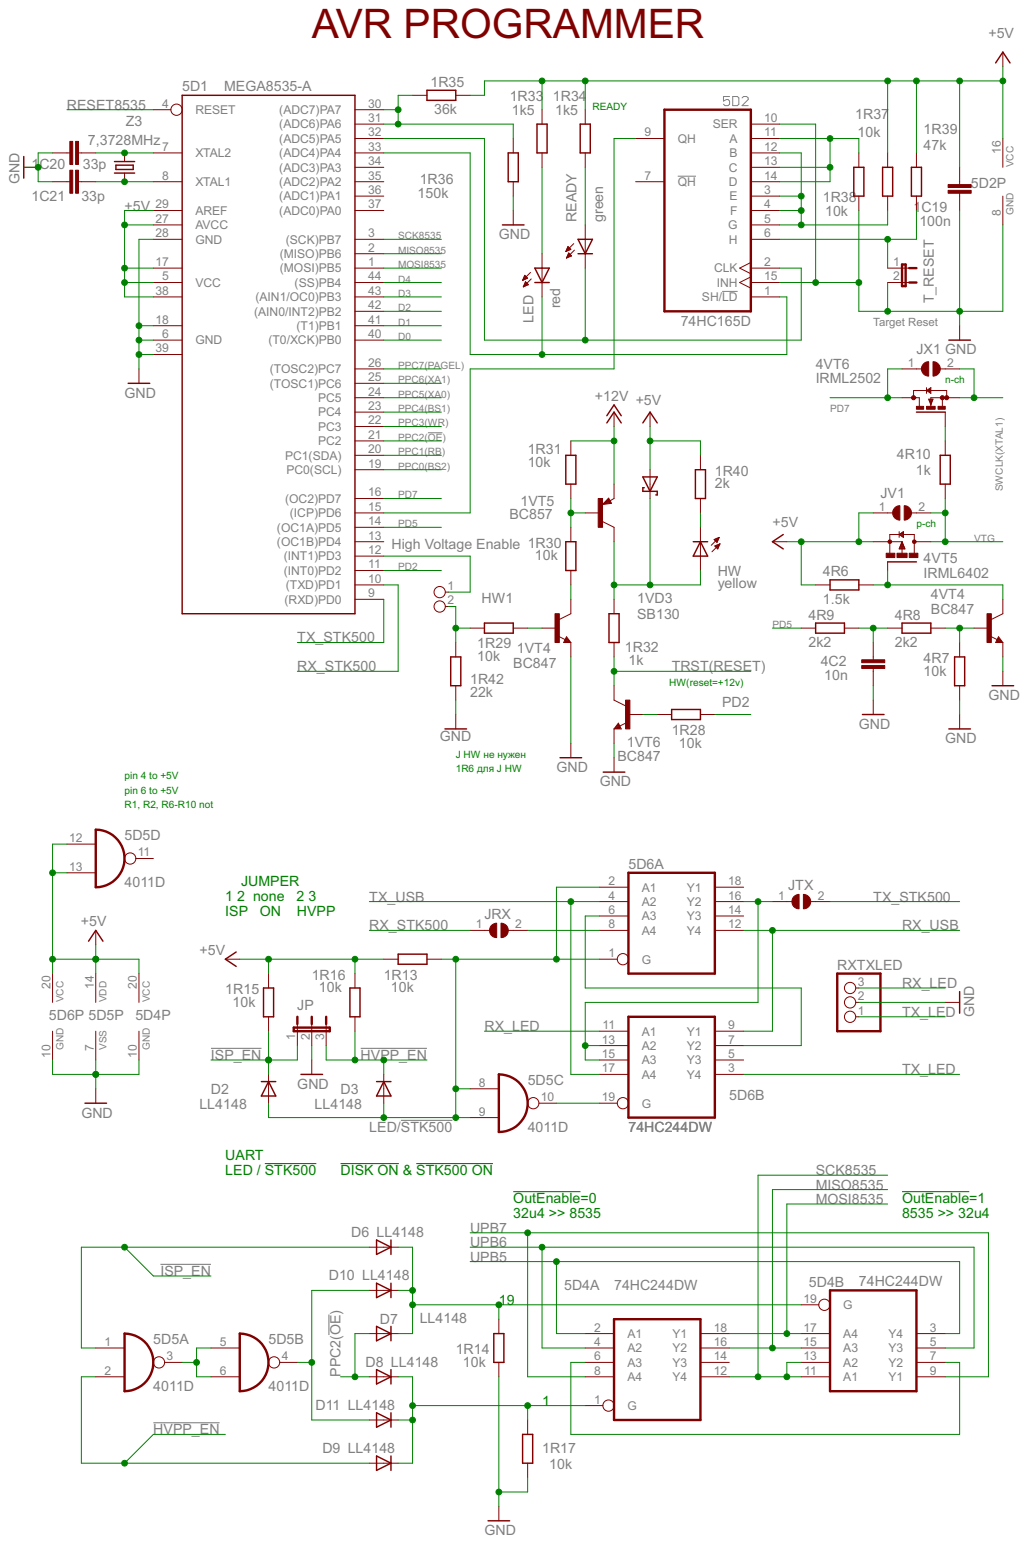
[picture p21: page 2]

J HW не нужен 1R6 для J HW

pin 4 to +5V R1, R2, R6-R10 not pin 6 to +5V

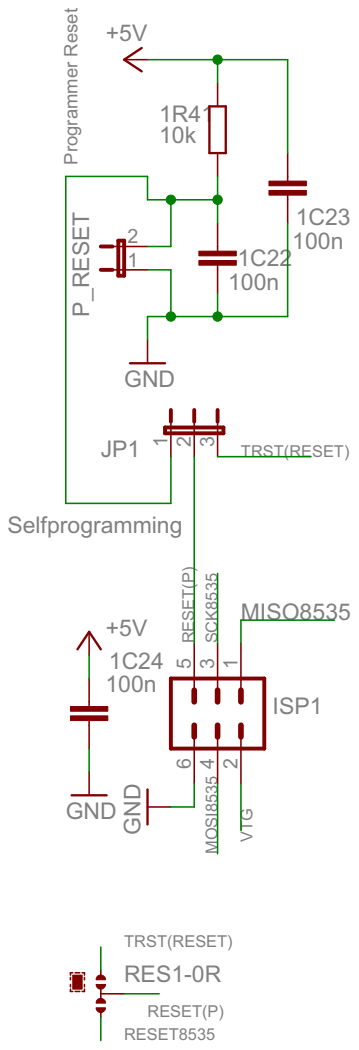
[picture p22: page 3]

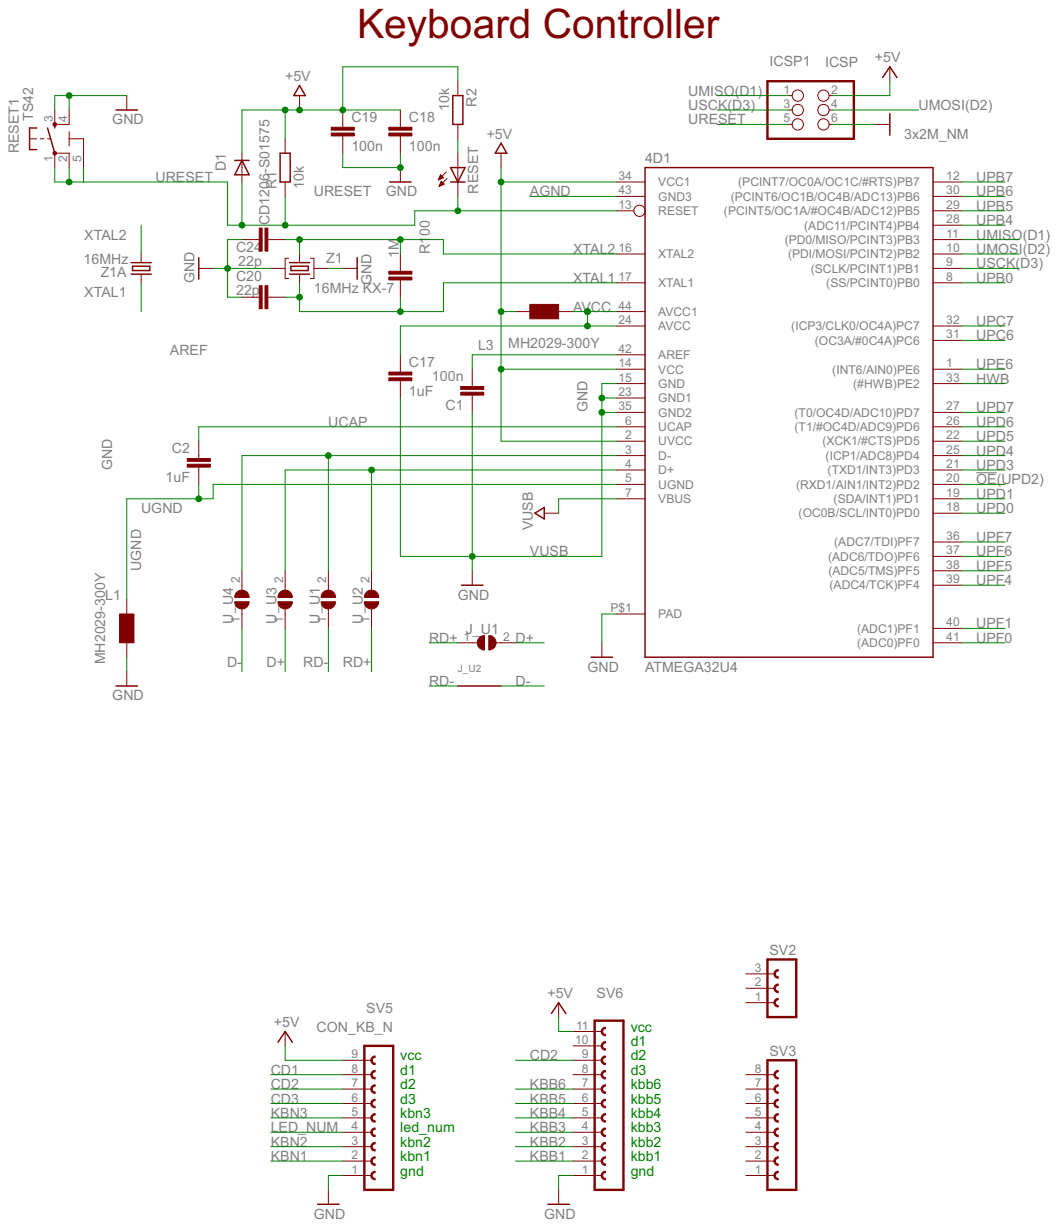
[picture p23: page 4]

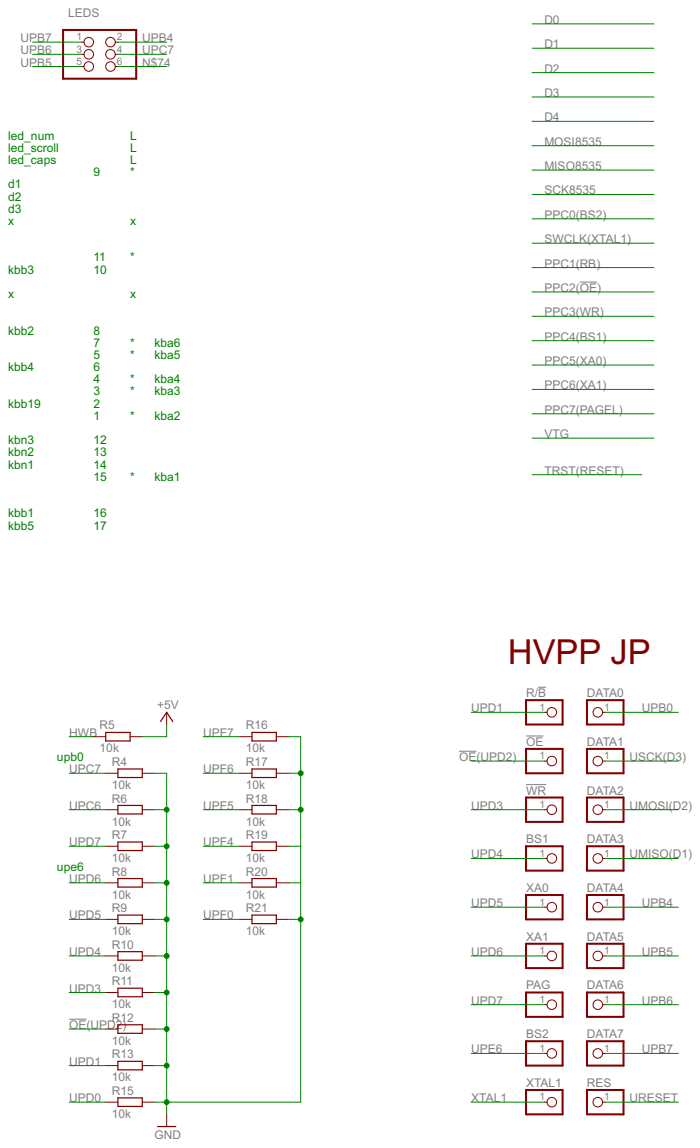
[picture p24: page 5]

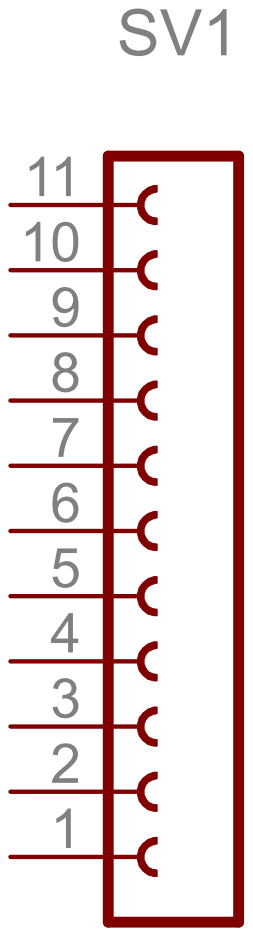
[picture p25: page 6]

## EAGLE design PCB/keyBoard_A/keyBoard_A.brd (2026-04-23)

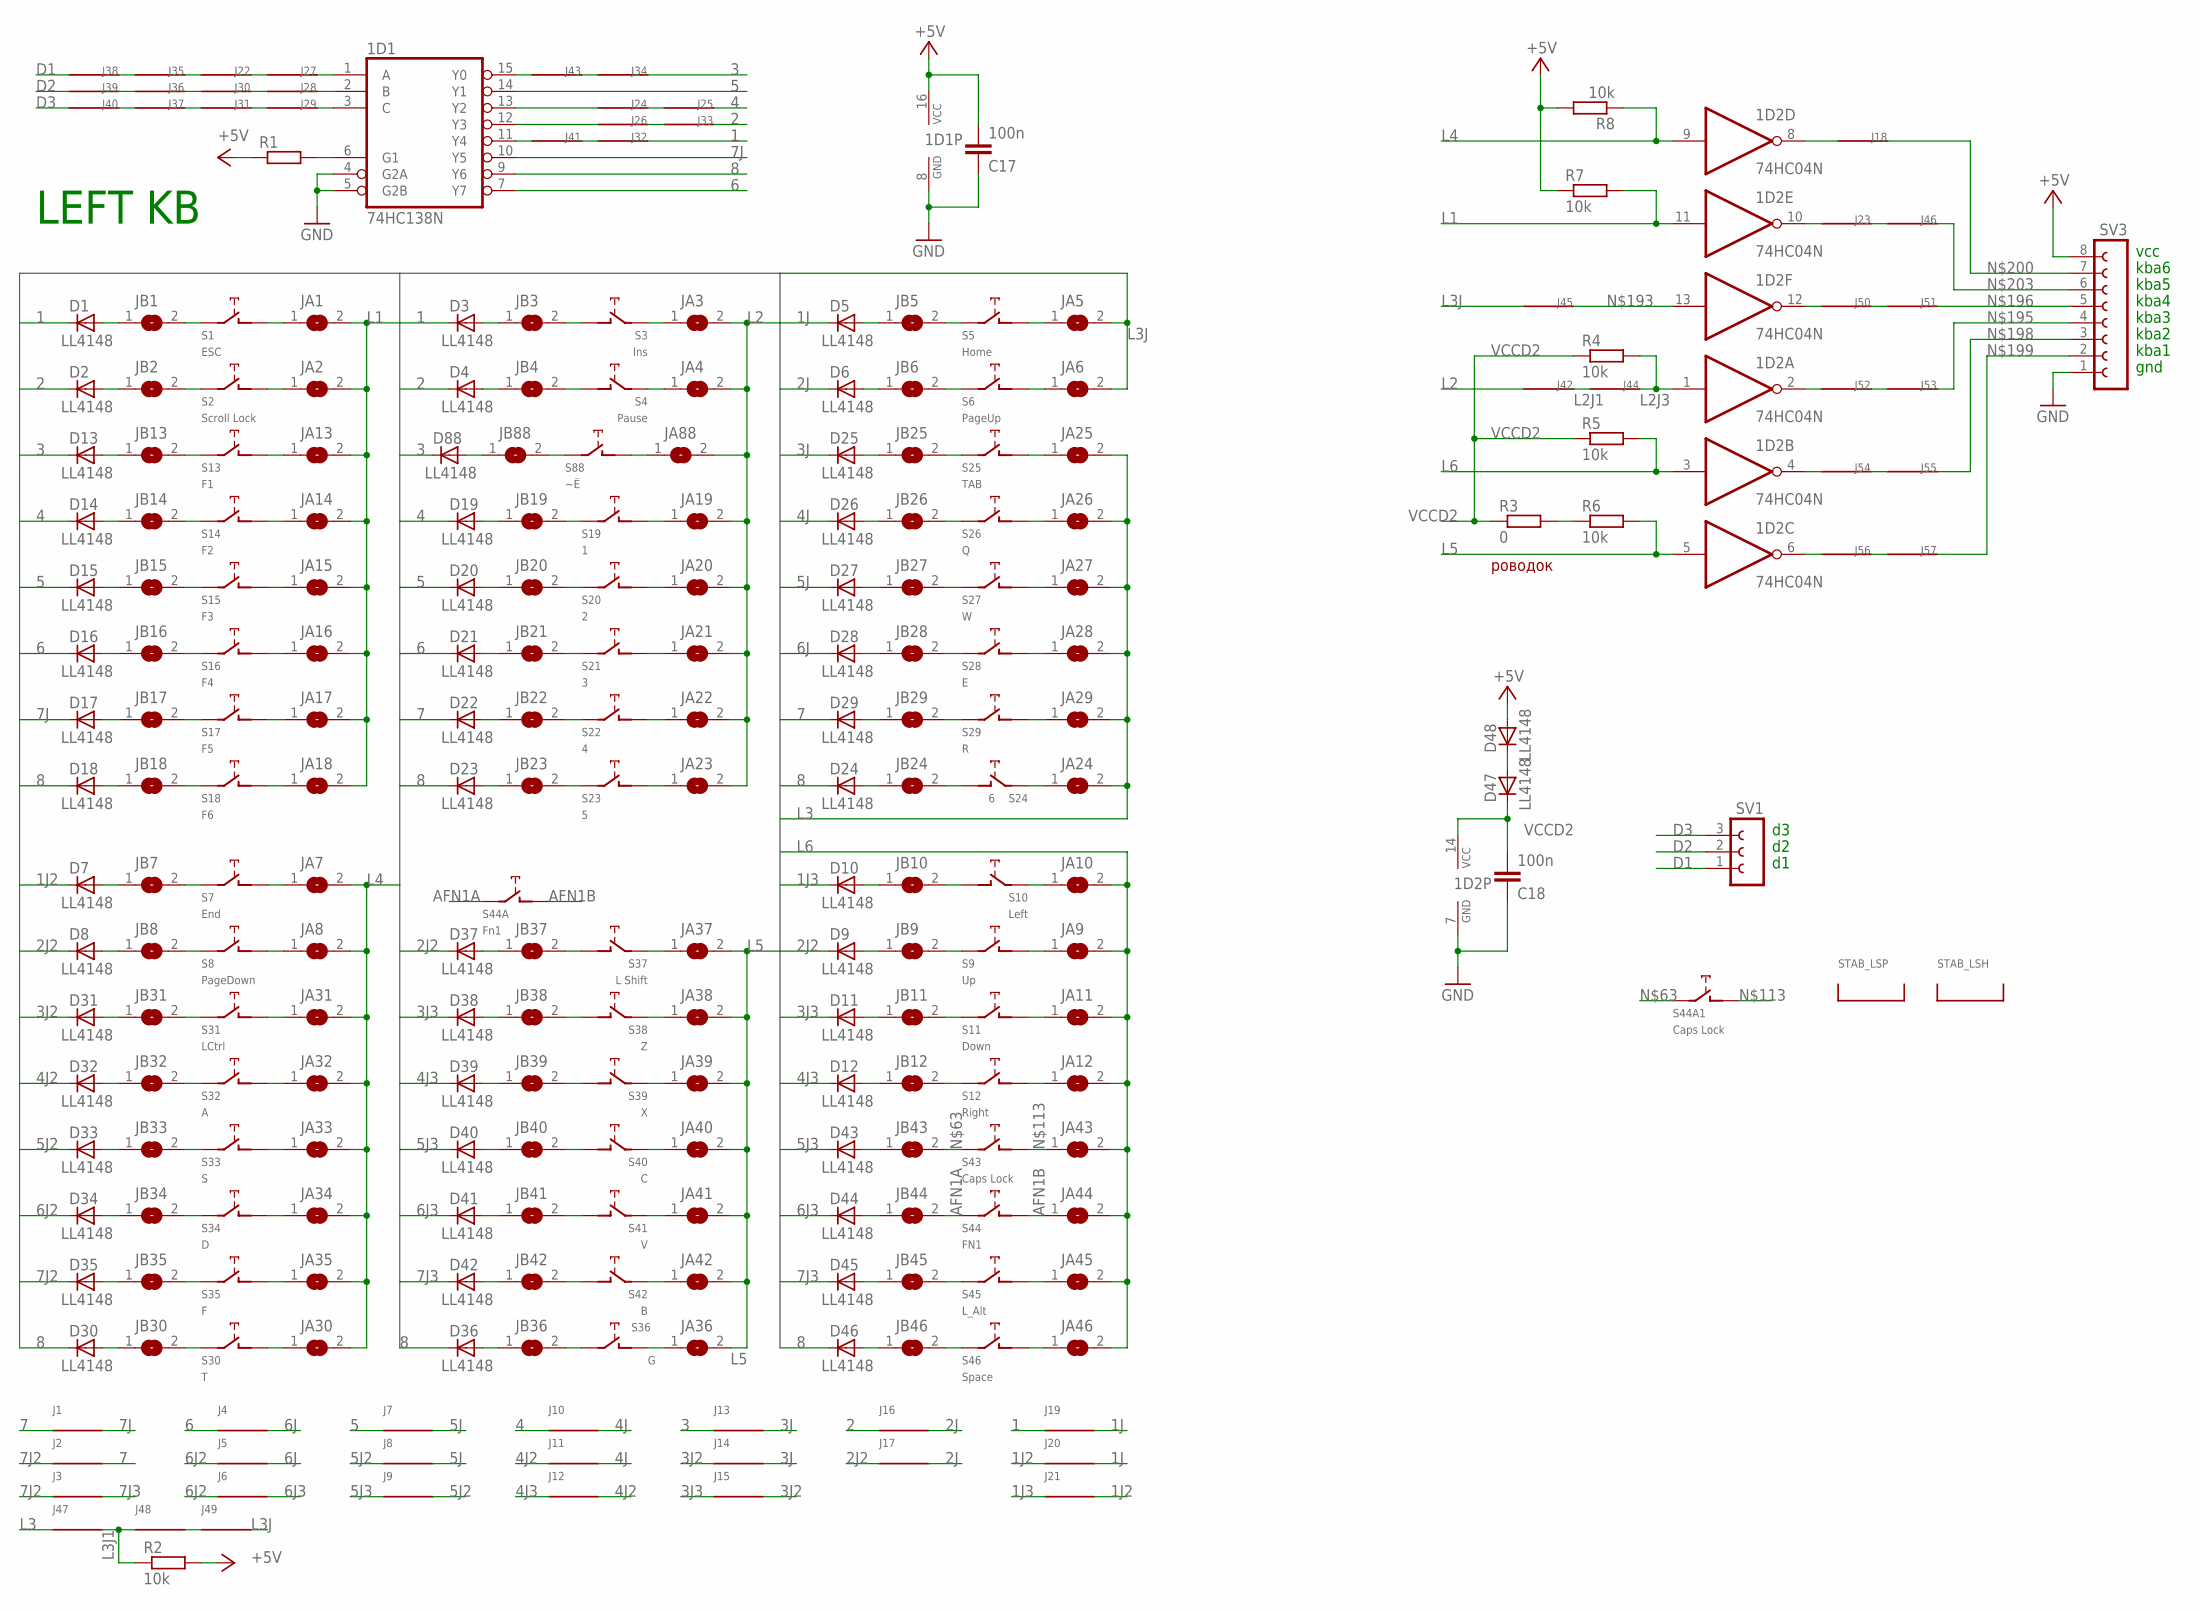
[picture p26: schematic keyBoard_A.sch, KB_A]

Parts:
1D1: 74HC138N; DIL16
1D2: 74HC04N; DIL14
C17, C18: 100n; C0805
D1, D2, D3, D4, D5, D6, D7, D8, D9, D10, D11, D12, D13, D14, D15, D16, D17, D18, D19, D20, D21, D22, D23, D24, D25, D26, D27, D28, D29, D30, D31, D32, D33, D34, D35, D36, D37, D38, D39, D40, D41, D42, D43, D44, D45, D46, D47, D48, D88: LL4148; SOD80C
J1, J2, J3, J4, J5, J6, J7, J8, J9, J10, J11, J12, J13, J14, J15, J16, J17, J18, J19, J20, J21, J22, J23, J24, J25, J26, J27, J28, J29, J30, J31, J32, J33, J34, J35, J36, J37, J38, J39, J40, J41, J42, J43, J44, J45, J46, J47, J48, J49, J50, J51, J52, J53, J54, J55, J56, J57: J; R1206W
JA1, JA2, JA3, JA4, JA5, JA6, JA7, JA8, JA9, JA10, JA11, JA12, JA13, JA14, JA15, JA16, JA17, JA18, JA19, JA20, JA21, JA22, JA23, JA24, JA25, JA26, JA27, JA28, JA29, JA30, JA31, JA32, JA33, JA34, JA35, JA36, JA37, JA38, JA39, JA40, JA41, JA42, JA43, JA44, JA45, JA46, JA88: SJ
JB1, JB3, JB4, JB6, JB7, JB8, JB9, JB10, JB11, JB12, JB13, JB16, JB17, JB18, JB19, JB20, JB21, JB22, JB23, JB24, JB25, JB26, JB27, JB28, JB29, JB30, JB31, JB32, JB33, JB34, JB35, JB36, JB37, JB38, JB39, JB40, JB41, JB42, JB43, JB44, JB45, JB46, JB88: SJ
JB2, JB5, JB14, JB15: SJ; SJ@1
R1: R-EU_R1206W; R1206W
R2, R5, R6, R7: 10k; R1206W
R3: 0; R1206W
R4, R8: 10k; R0805
S1: ESC; CHERRY-MX-4P
S2: Scroll Lock; CHERRY-MX-4P
S3: Ins; CHERRY-MX-4P
S4: Pause; CHERRY-MX-4P
S5: Home; CHERRY-MX-4P
S6: PageUp; CHERRY-MX-4P
S7: End; CHERRY-MX-4P
S8: PageDown; CHERRY-MX-4P
S9: Up; CHERRY-MX-4P
S10: Left; CHERRY-MX-4P
S11: Down; CHERRY-MX-4P
S12: Right; CHERRY-MX-4P
S13: F1; CHERRY-MX-4P
S14: F2; CHERRY-MX-4P
S15: F3; CHERRY-MX-4P
S16: F4; CHERRY-MX-4P
S17: F5; CHERRY-MX-4P
S18: F6; CHERRY-MX-4P
S19: 1; CHERRY-MX-4P
S20: 2; CHERRY-MX-4P
S21: 3; CHERRY-MX-4P
S22: 4; CHERRY-MX-4P
S23: 5; CHERRY-MX-4P
S24: 6; CHERRY-MX-4P
S25: TAB; CHERRY-MX-4P
S26: Q; CHERRY-MX-4P
S27: W; CHERRY-MX-4P
S28: E; CHERRY-MX-4P
S29: R; CHERRY-MX-4P
S30: T; CHERRY-MX-4P
S31: LCtrl; CHERRY-MX-4P
S32: A; CHERRY-MX-4P
S33: S; CHERRY-MX-4P
S34: D; CHERRY-MX-4P
S35: F; CHERRY-MX-4P
S36: G; CHERRY-MX-4P
S37: L Shift; CHERRY-MX-4P
S38: Z; CHERRY-MX-4P
S39: X; CHERRY-MX-4P
S40: C; CHERRY-MX-4P
S41: V; CHERRY-MX-4P
S42: B; CHERRY-MX-4P
S43: Caps Lock; CHERRY-MX-4P
S44: FN1; CHERRY-MX-4P
S44A: Fn1; CHERRY-MX
S44A1: Caps Lock; CHERRY-MX
S45: L_Alt; CHERRY-MX-4P
S46: Space; CHERRY-MX-4P
S88: ~Ё; CHERRY-MX-4P
STAB_LSH: STAB; ZEALIOS-PCB_2U
STAB_LSP: STAB; ZEALIOS-PCB_2U
SV1: FE03-1
SV3: FE08-1; FE08

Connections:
1: D1.C, D3.C, J19.2, J32.1
1J: D5.C, J19.1, J20.1
1J2: D7.C, J20.2, J21.1
1J3: D10.C, J21.2
2: D2.C, D4.C, J16.2, J33.1
2J: D6.C, J16.1, J17.1
2J2: D8.C, D9.C, D37.C, J17.2
3: D13.C, D88.C, J13.2, J34.1
3J: D25.C, J13.1, J14.1
3J2: D31.C, J14.2, J15.1
3J3: D11.C, D38.C, J15.2
4: D14.C, D19.C, J10.2, J25.1
4J: D26.C, J10.1, J11.1
4J2: D32.C, J11.2, J12.1
4J3: D12.C, D39.C, J12.2
5: 1D1.14 (Y1), D15.C, D20.C, J7.2
5J: D27.C, J7.1, J8.1
5J2: D33.C, J8.2, J9.1
5J3: D40.C, D43.C, J9.2
6: 1D1.7 (Y7), D16.C, D21.C, J4.2
6J: D28.C, J4.1, J5.1
6J2: D34.C, J5.2, J6.2
6J3: D41.C, D44.C, J6.1
7: D22.C, D29.C, J1.2, J2.1
7J: 1D1.10 (Y5), D17.C, J1.1
7J2: D35.C, J2.2, J3.2
7J3: D42.C, D45.C, J3.1
8: 1D1.9 (Y6), D18.C, D23.C, D24.C, D30.C, D36.C, D46.C
+5V: 1D1.16 (VCC), C17.2, D48.A, R1.1, R2.2, R7.1, R8.2, SV3.8
AFN1A: JB44.2, S44.SW1 (PIN-1), S44A.SW1 (PIN-1)
AFN1B: JA44.1, S44.SW2 (PIN-2), S44A.SW2 (PIN-2)
D1: J38.2, SV1.1
D2: J39.2, SV1.2
D3: J40.2, SV1.3
GND: 1D1.4 (G2A), 1D1.5 (G2B), 1D1.8 (GND), 1D2.7 (GND), C17.1, C18.1, SV3.1
L1: 1D2.11 (I), JA1.2, JA2.2, JA13.2, JA14.2, JA15.2, JA16.2, JA17.2, JA18.2, R7.2
L2: J42.2, JA3.2, JA4.2, JA19.2, JA20.2, JA21.2, JA22.2, JA23.2, JA88.2
L2J1: J42.1, J44.2
L2J3: 1D2.1 (I), J44.1, R4.2
L3: J47.2, JA24.2, JA25.2, JA26.2, JA27.2, JA28.2, JA29.2
L3J: J45.2, J49.1, JA5.2, JA6.2
L3J1: J47.1, J48.2, R2.1
L4: 1D2.9 (I), JA7.2, JA8.2, JA30.2, JA31.2, JA32.2, JA33.2, JA34.2, JA35.2, R8.1
L5: 1D2.5 (I), JA36.2, JA37.2, JA38.2, JA39.2, JA40.2, JA41.2, JA42.2, R6.2
L5O: 1D2.6 (O), J56.2
L6: 1D2.3 (I), JA9.2, JA10.2, JA11.2, JA12.2, JA43.2, JA44.2, JA45.2, JA46.2, R5.2
unnamed: D15.A, JB15.1
unnamed: JB4.2, S4.SW2 (PIN-2)
unnamed: D1.A, JB1.1
unnamed: JA4.1, S4.SW1 (PIN-1)
unnamed: JB14.2, S14.SW1 (PIN-1)
unnamed: JB20.2, S20.SW1 (PIN-1)
unnamed: JB32.2, S32.SW1 (PIN-1)
unnamed: JB38.2, S38.SW2 (PIN-2)
unnamed: JB6.2, S6.SW1 (PIN-1)
unnamed: JA6.1, S6.SW2 (PIN-2)
unnamed: JA8.1, S8.SW2 (PIN-2)
unnamed: JB8.2, S8.SW1 (PIN-1)
unnamed: JB10.2, S10.SW2 (PIN-2)
unnamed: JB1.2, S1.SW1 (PIN-1)
unnamed: D2.A, JB2.1
unnamed: JB2.2, S2.SW1 (PIN-1)
unnamed: JA2.1, S2.SW2 (PIN-2)
unnamed: D16.A, JB16.1
unnamed: JB3.2, S3.SW2 (PIN-2)
unnamed: JB5.2, S5.SW1 (PIN-1)
unnamed: JB7.2, S7.SW1 (PIN-1)
unnamed: JB9.2, S9.SW1 (PIN-1)
unnamed: JB11.2, S11.SW1 (PIN-1)
unnamed: D3.A, JB3.1
unnamed: JB12.2, S12.SW1 (PIN-1)
unnamed: D5.A, JB5.1
unnamed: D7.A, JB7.1
unnamed: JA10.1, S10.SW1 (PIN-1)
unnamed: JA1.1, S1.SW2 (PIN-2)
unnamed: D9.A, JB9.1
unnamed: D11.A, JB11.1
unnamed: JA3.1, S3.SW1 (PIN-1)
unnamed: JA5.1, S5.SW2 (PIN-2)
unnamed: JA7.1, S7.SW2 (PIN-2)
unnamed: JA9.1, S9.SW2 (PIN-2)
unnamed: JA11.1, S11.SW2 (PIN-2)
unnamed: JA12.1, S12.SW2 (PIN-2)
unnamed: JA14.1, S14.SW2 (PIN-2)
unnamed: JB13.2, S13.SW1 (PIN-1)
unnamed: JA13.1, S13.SW2 (PIN-2)
unnamed: D14.A, JB14.1
unnamed: JB42.2, S42.SW2 (PIN-2)
unnamed: JA42.1, S42.SW1 (PIN-1)
unnamed: JB27.2, S27.SW1 (PIN-1)
unnamed: JA27.1, S27.SW2 (PIN-2)
unnamed: JB17.2, S17.SW1 (PIN-1)
unnamed: JA17.1, S17.SW2 (PIN-2)
unnamed: D24.A, JB24.1
unnamed: JB24.2, S24.SW2 (PIN-2)
unnamed: JA24.1, S24.SW1 (PIN-1)
unnamed: J22.1, J27.2
unnamed: D4.A, JB4.1
unnamed: D6.A, JB6.1
unnamed: D8.A, JB8.1
unnamed: D10.A, JB10.1
unnamed: D12.A, JB12.1
unnamed: D13.A, JB13.1
unnamed: JB19.2, S19.SW1 (PIN-1)
unnamed: JB25.2, S25.SW1 (PIN-1)
unnamed: 1D2.8 (O), J18.2
unnamed: JB31.2, S31.SW1 (PIN-1)
unnamed: JB37.2, S37.SW2 (PIN-2)
unnamed: JB43.2, S43.SW1 (PIN-1), S44A1.SW1 (PIN-1)
unnamed: JB26.2, S26.SW1 (PIN-1)
unnamed: JB41.2, S41.SW2 (PIN-2)
unnamed: JB18.2, S18.SW1 (PIN-1)
unnamed: 1D1.13 (Y2), J24.2
unnamed: JB30.2, S30.SW1 (PIN-1)
unnamed: JB36.2, S36.SW1 (PIN-1)
unnamed: J24.1, J25.2
unnamed: JB23.2, S23.SW1 (PIN-1)
unnamed: JB29.2, S29.SW1 (PIN-1)
unnamed: JB35.2, S35.SW1 (PIN-1)
unnamed: JA41.1, S41.SW1 (PIN-1)
unnamed: JB16.2, S16.SW1 (PIN-1)
unnamed: JB22.2, S22.SW1 (PIN-1)
unnamed: JB28.2, S28.SW1 (PIN-1)
unnamed: JB34.2, S34.SW1 (PIN-1)
unnamed: JB40.2, S40.SW2 (PIN-2)
unnamed: JB46.2, S46.SW1 (PIN-1)
unnamed: JB15.2, S15.SW1 (PIN-1)
unnamed: JB21.2, S21.SW1 (PIN-1)
unnamed: JB33.2, S33.SW1 (PIN-1)
unnamed: JB39.2, S39.SW2 (PIN-2)
unnamed: JB45.2, S45.SW1 (PIN-1)
unnamed: JA15.1, S15.SW2 (PIN-2)
unnamed: JA18.1, S18.SW2 (PIN-2)
unnamed: JA20.1, S20.SW2 (PIN-2)
unnamed: JA22.1, S22.SW2 (PIN-2)
unnamed: JA23.1, S23.SW2 (PIN-2)
unnamed: JA25.1, S25.SW2 (PIN-2)
unnamed: JA26.1, S26.SW2 (PIN-2)
unnamed: JA28.1, S28.SW2 (PIN-2)
unnamed: JA29.1, S29.SW2 (PIN-2)
unnamed: JA30.1, S30.SW2 (PIN-2)
unnamed: JA31.1, S31.SW2 (PIN-2)
unnamed: JA32.1, S32.SW2 (PIN-2)
unnamed: JA33.1, S33.SW2 (PIN-2)
unnamed: JA34.1, S34.SW2 (PIN-2)
unnamed: JA35.1, S35.SW2 (PIN-2)
unnamed: JA36.1, S36.SW2 (PIN-2)
unnamed: JA38.1, S38.SW1 (PIN-1)
unnamed: JA39.1, S39.SW1 (PIN-1)
unnamed: JA40.1, S40.SW1 (PIN-1)
unnamed: JB88.2, S88.SW1 (PIN-1)
unnamed: JA43.1, S43.SW2 (PIN-2), S44A1.SW2 (PIN-2)
unnamed: JA45.1, S45.SW2 (PIN-2)
unnamed: JA46.1, S46.SW2 (PIN-2)
unnamed: JA19.1, S19.SW2 (PIN-2)
unnamed: JA88.1, S88.SW2 (PIN-2)
unnamed: JA21.1, S21.SW2 (PIN-2)
unnamed: JA16.1, S16.SW2 (PIN-2)
unnamed: D17.A, JB17.1
unnamed: D18.A, JB18.1
unnamed: D19.A, JB19.1
unnamed: D20.A, JB20.1
unnamed: D21.A, JB21.1
unnamed: D22.A, JB22.1
unnamed: D23.A, JB23.1
unnamed: D25.A, JB25.1
unnamed: D26.A, JB26.1
unnamed: D27.A, JB27.1
unnamed: D28.A, JB28.1
unnamed: D29.A, JB29.1
unnamed: D30.A, JB30.1
unnamed: D31.A, JB31.1
unnamed: D32.A, JB32.1
unnamed: D33.A, JB33.1
unnamed: D34.A, JB34.1
unnamed: D35.A, JB35.1
unnamed: D36.A, JB36.1
unnamed: D37.A, JB37.1
unnamed: D38.A, JB38.1
unnamed: D39.A, JB39.1
unnamed: D40.A, JB40.1
unnamed: D41.A, JB41.1
unnamed: D42.A, JB42.1
unnamed: D43.A, JB43.1
unnamed: D44.A, JB44.1
unnamed: D45.A, JB45.1
unnamed: D46.A, JB46.1
unnamed: D88.A, JB88.1
unnamed: 1D1.15 (Y0), J43.2
unnamed: 1D1.1 (A), J27.1
unnamed: 1D1.2 (B), J28.1
unnamed: 1D1.3 (C), J29.1
unnamed: J28.2, J30.1
unnamed: J29.2, J31.1
unnamed: J26.1, J33.2
unnamed: J35.2, J38.1
unnamed: J36.2, J39.1
unnamed: J37.2, J40.1
unnamed: J31.2, J37.1
unnamed: J30.2, J36.1
unnamed: J22.2, J35.1
unnamed: J32.2, J41.1
unnamed: 1D1.11 (Y4), J41.2
unnamed: 1D1.12 (Y3), J26.2
unnamed: J34.2, J43.1
unnamed: D47.A, D48.C
unnamed: 1D2.13 (I), J45.1
unnamed: J53.1, SV3.4
unnamed: J51.1, SV3.5
unnamed: 1D2.10 (O), J23.2
unnamed: J55.1, SV3.3
unnamed: J57.1, SV3.2
unnamed: J18.1, SV3.7
unnamed: J46.1, SV3.6
unnamed: J48.1, J49.2
unnamed: J23.1, J46.2
unnamed: 1D2.12 (O), J50.2
unnamed: J50.1, J51.2
unnamed: 1D2.2 (O), J52.2
unnamed: J52.1, J53.2
unnamed: 1D2.4 (O), J54.2
unnamed: JA37.1, S37.SW1 (PIN-1)
unnamed: J54.1, J55.2
unnamed: J56.1, J57.2
unnamed: R3.2, R6.1
unnamed: 1D1.6 (G1), R1.2
VCCD2: 1D2.14 (VCC), C18.2, D47.C, R3.1, R4.1, R5.1

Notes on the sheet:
vcc
gnd
LEFT KB
kba1
kba2
kba3
kba4
kba5
kba6
роводок

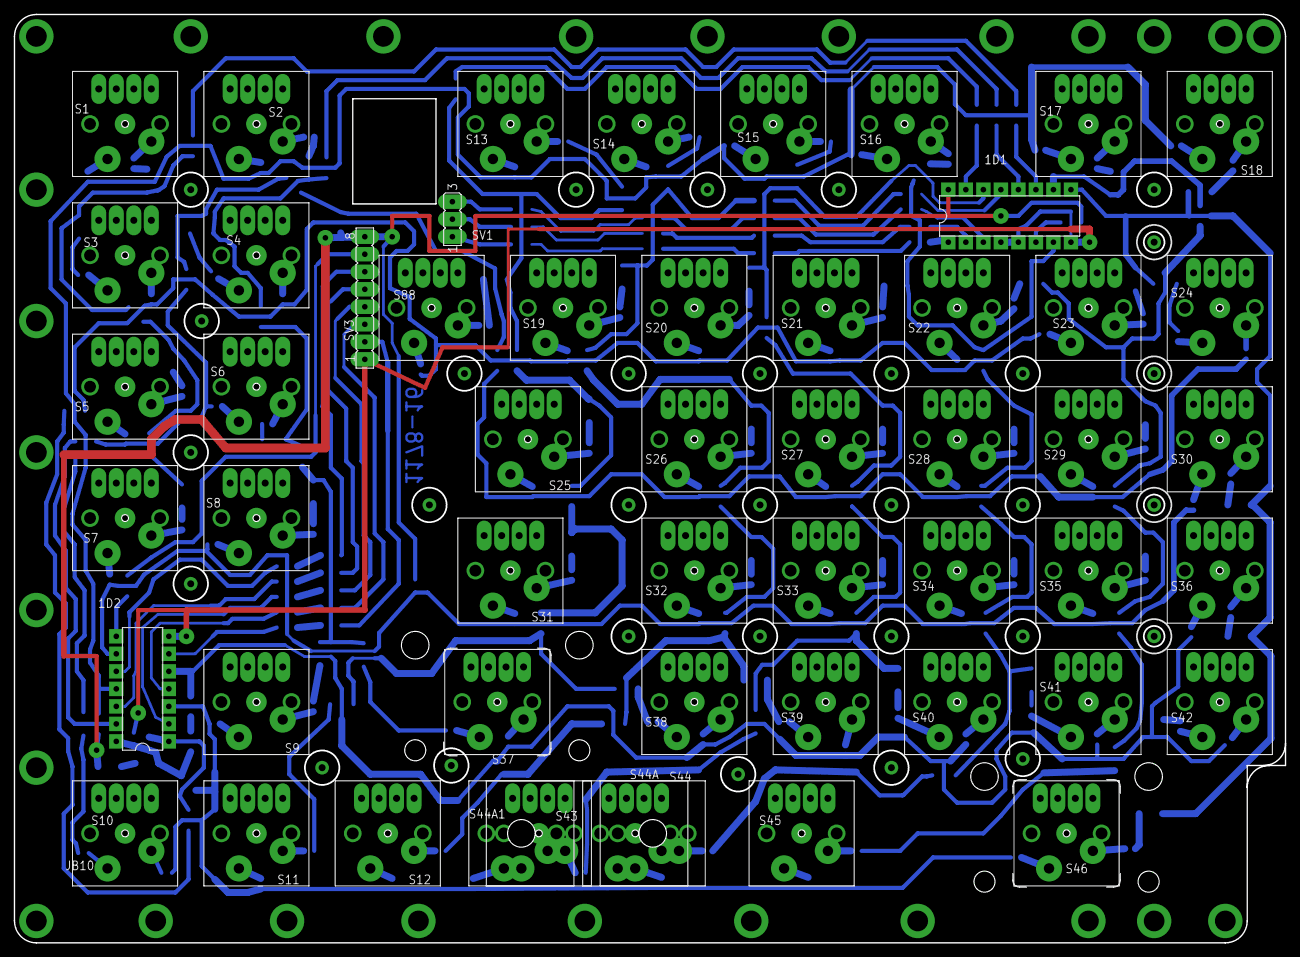
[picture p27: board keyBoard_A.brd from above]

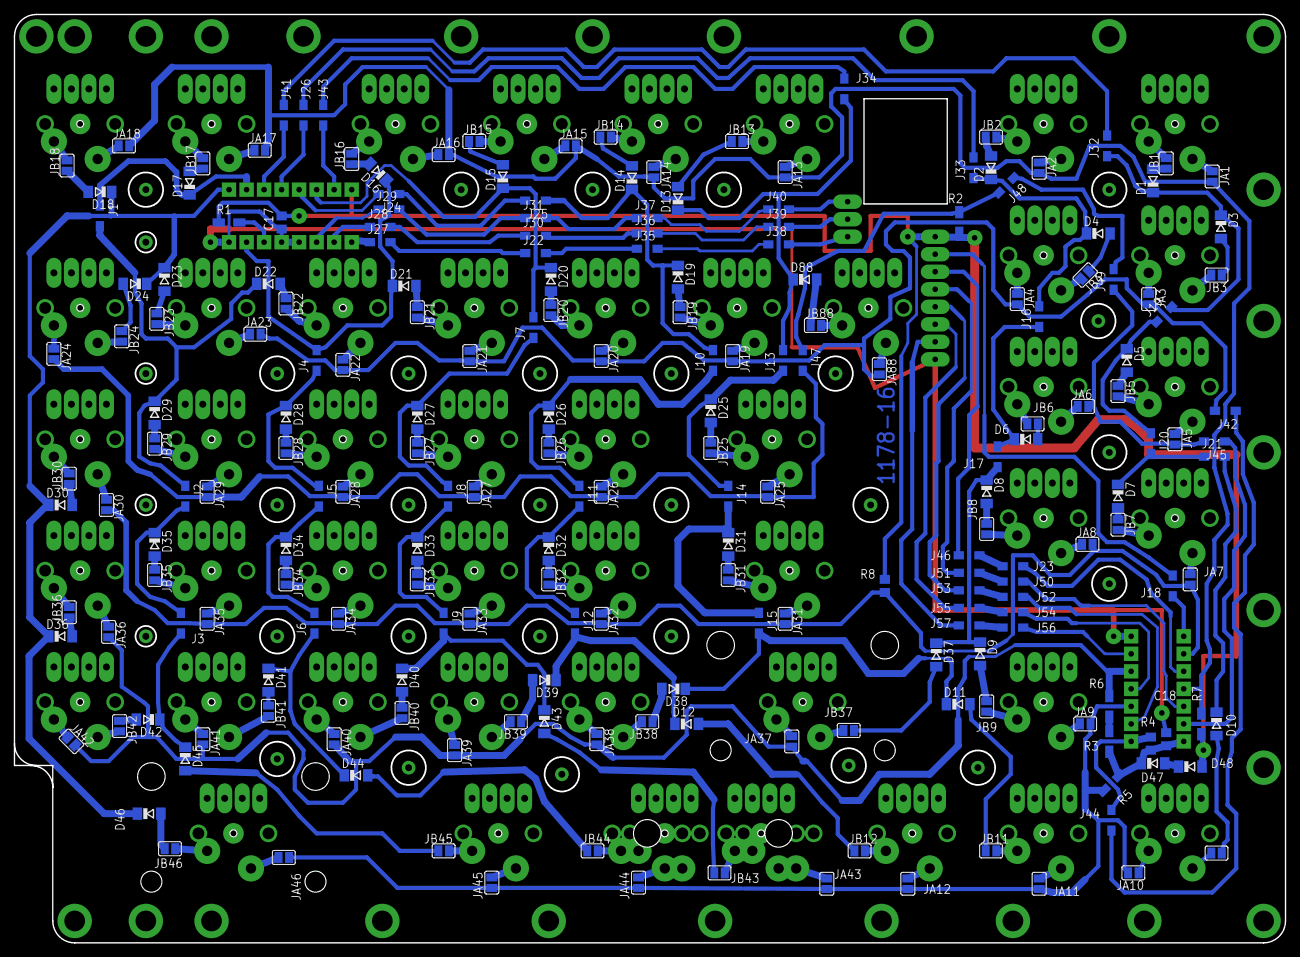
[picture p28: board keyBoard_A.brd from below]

Board: 2 copper layers, 184.3 x 134.6 mm, 321 parts (14 on the bottom side), 227 nets.

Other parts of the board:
U$1, U$2, U$3, U$4, U$5, U$6, U$7, U$8, U$9, U$10, U$11, U$12, U$13, U$14, U$18, U$19, U$20, U$21, U$23, U$24, U$25, U$26, U$27, U$29, U$30, U$31, U$32, U$33, U$35, U$36, U$37, U$38, U$39, U$40, U$41, U$42, U$43, U$44, U$45, U$46, U$49, U$52, U$82, U$88: 18X18
U$15, U$16, U$48, U$50, U$51, U$91: 18X23
U$17, U$47, U$53: 18X52
U$22: 18X37
U$28: 18X33
U$34: 18X28

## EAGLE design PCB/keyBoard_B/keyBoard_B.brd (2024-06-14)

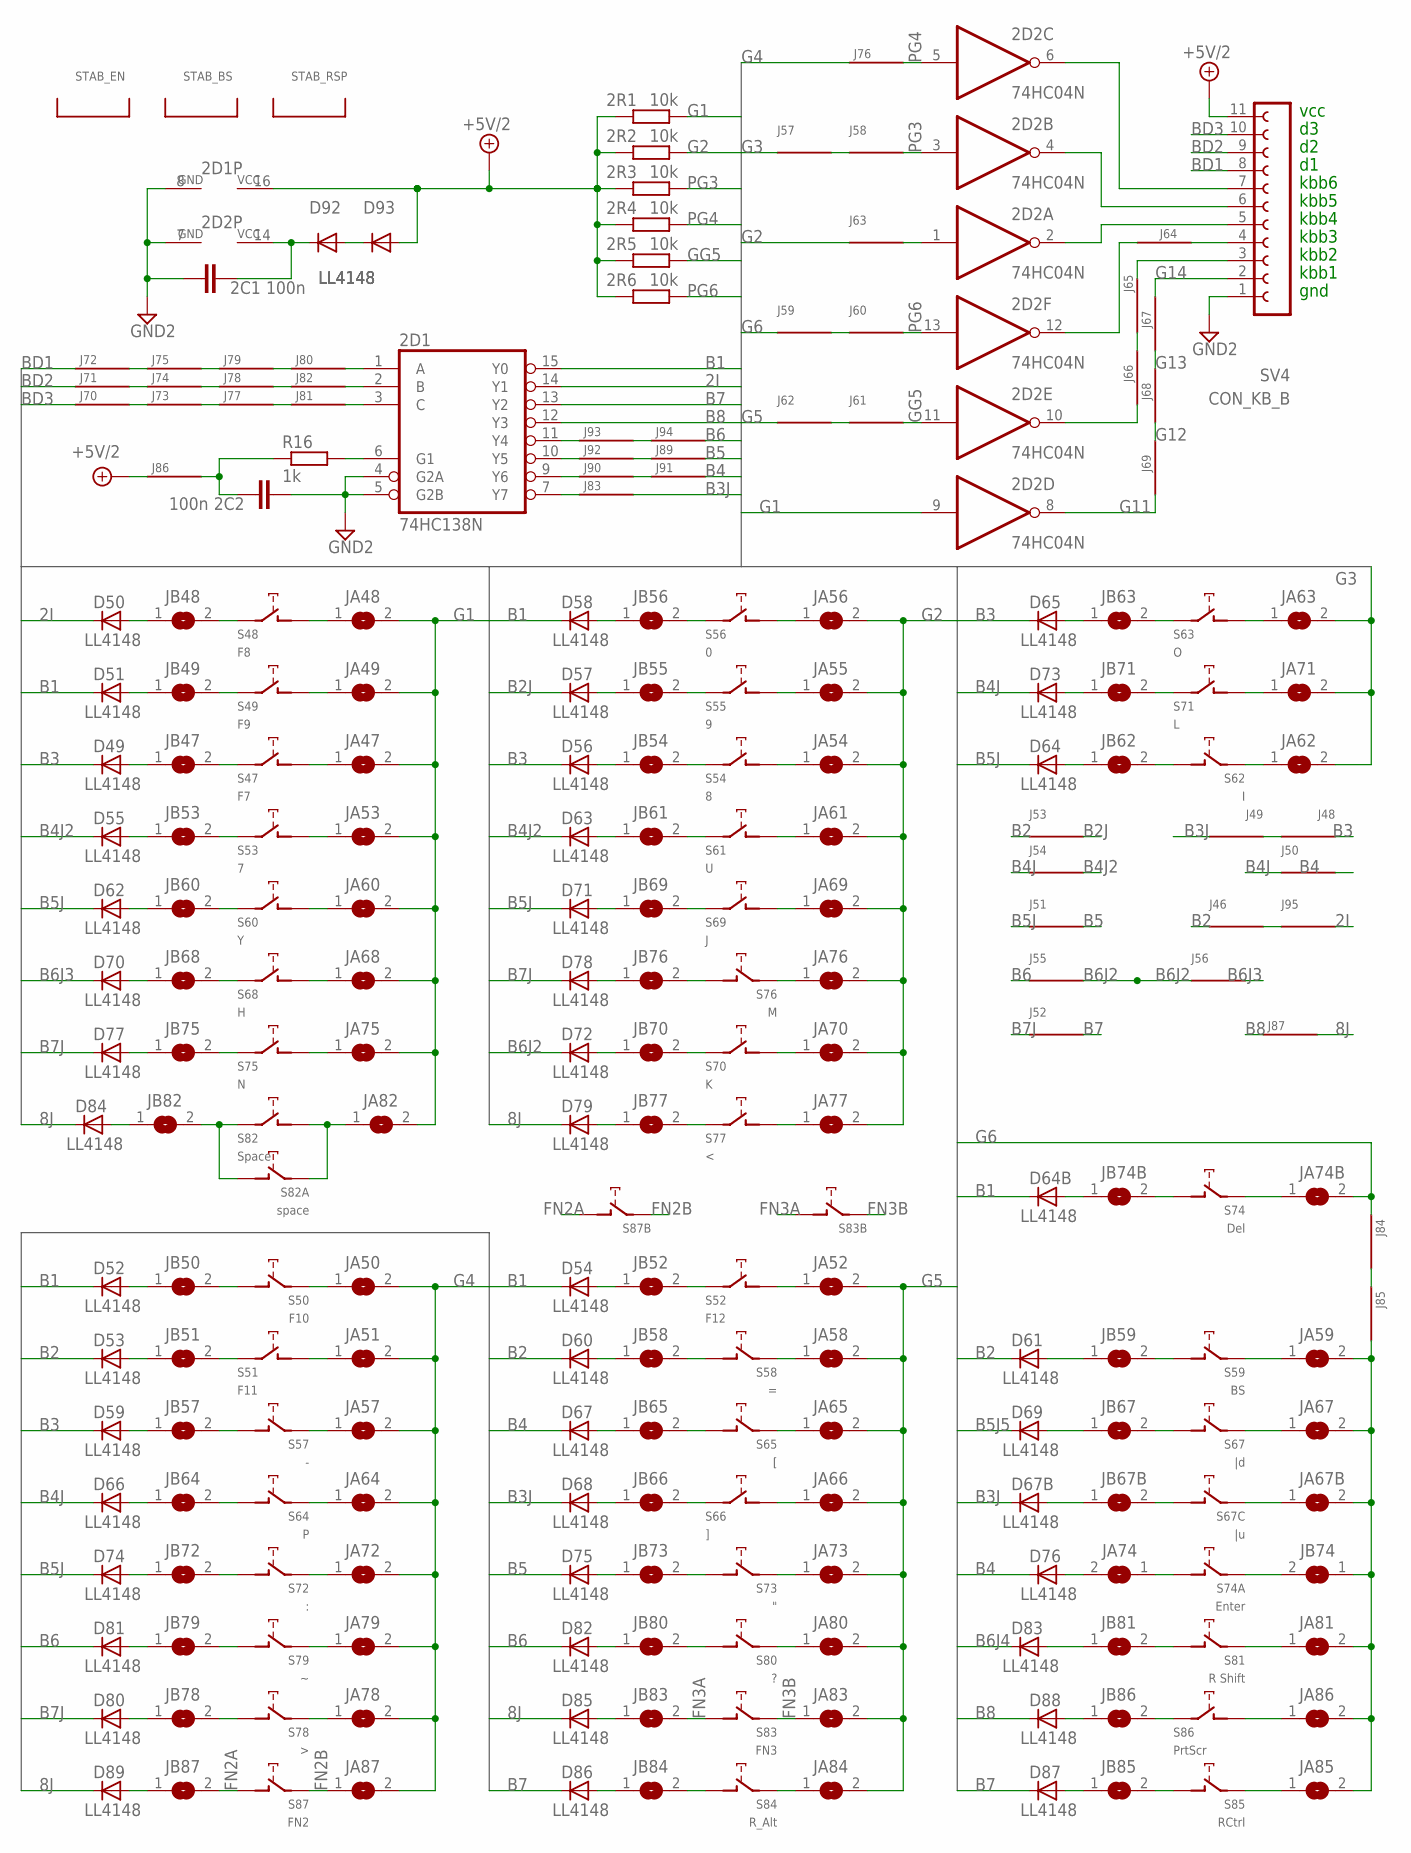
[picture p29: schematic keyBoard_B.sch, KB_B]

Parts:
2C1: 100n; C1206
2C2: 100n; C1206K
2D1: 74HC138N; DIL16
2D2: 74HC04N; DIL14
2R1, 2R2, 2R3, 2R5, 2R6: 10k; R0805
2R4: 10k; R1206W
D49, D50, D51, D52, D53, D54, D55, D56, D57, D58, D59, D60, D61, D62, D63, D64, D64B, D65, D66, D67, D67B, D68, D69, D70, D71, D72, D73, D74, D75, D76, D77, D78, D79, D80, D81, D82, D83, D84, D85, D86, D87, D88, D89, D92, D93: LL4148; SOD80C
J46, J48, J49, J50, J51, J52, J53, J54, J55, J56, J57, J58, J59, J60, J61, J62, J63, J64, J65, J66, J67, J68, J69, J70, J71, J72, J73, J74, J75, J76, J77, J78, J79, J80, J81, J82, J83, J84, J85, J86, J87, J89, J90, J91, J92, J93, J94, J95: J; R1206W
JA47, JA48, JA49, JA50, JA51, JA52, JA53, JA54, JA55, JA56, JA57, JA58, JA59, JA60, JA61, JA62, JA63, JA64, JA65, JA66, JA67, JA67B, JA68, JA69, JA70, JA71, JA72, JA73, JA74, JA74B, JA75, JA76, JA77, JA78, JA79, JA80, JA81, JA82, JA83, JA84, JA85, JA86, JA87: SJ
JB47, JB48, JB49, JB50, JB51, JB52, JB53, JB54, JB55, JB56, JB57, JB58, JB59, JB60, JB61, JB62, JB63, JB64, JB65, JB66, JB67, JB67B, JB68, JB69, JB70, JB71, JB72, JB73, JB74, JB74B, JB75, JB76, JB77, JB78, JB79, JB80, JB81, JB82, JB83, JB84, JB85, JB86, JB87: SJ
R16: 1k; R1206W
S47: F7; CHERRY-MX-4P
S48: F8; CHERRY-MX-4P
S49: F9; CHERRY-MX-4P
S50: F10; CHERRY-MX-4P
S51: F11; CHERRY-MX-4P
S52: F12; CHERRY-MX-4P
S53: 7; CHERRY-MX-4P
S54: 8; CHERRY-MX-4P
S55: 9; CHERRY-MX-4P
S56: 0; CHERRY-MX-4P
S57: -; CHERRY-MX-4P
S58: =; CHERRY-MX-4P
S59: BS; CHERRY-MX-4P
S60: Y; CHERRY-MX-4P
S61: U; CHERRY-MX-4P
S62: I; CHERRY-MX-4P
S63: O; CHERRY-MX-4P
S64: P; CHERRY-MX-4P
S65: [; CHERRY-MX-4P
S66: ]; CHERRY-MX-4P
S67: |d; CHERRY-MX-4P
S67C: |u; CHERRY-MX-4P
S68: H; CHERRY-MX-4P
S69: J; CHERRY-MX-4P
S70: K; CHERRY-MX-4P
S71: L; CHERRY-MX-4P
S72: :; CHERRY-MX-4P
S73: "; CHERRY-MX-4P
S74: Del; CHERRY-MX-4P
S74A: Enter; CHERRY-MX-4P
S75: N; CHERRY-MX-4P
S76: M; CHERRY-MX-4P
S77: <; CHERRY-MX-4P
S78: >; CHERRY-MX-4P
S79: CHERRY-MX-4P
S80: ?; CHERRY-MX-4P
S81: R Shift; CHERRY-MX-4P
S82: Space; CHERRY-MX-4P
S82A: space; CHERRY-MX
S83: FN3; CHERRY-MX-4P
S83B, S87B: CHERRY-MX
S84: R_Alt; CHERRY-MX-4P
S85: RCtrl; CHERRY-MX-4P
S86: PrtScr; CHERRY-MX-4P
S87: FN2; CHERRY-MX-4P
STAB_BS: STAB; ZEALIOS-PCB_2U
STAB_EN: STAB; ZEALIOS-PCB_2U
STAB_RSP: STAB; ZEALIOS-PCB_2U
SV4: CON_KB_B; FE12

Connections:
2I: 2D1.14 (Y1), D50.C, J95.1
8J: D79.C, D84.C, D85.C, D89.C, J87.1
+3VD: 2C1.1, 2D2.14 (VCC), D92.C
+5V/2: 2D1.16 (VCC), 2R1.1, 2R2.1, 2R3.1, 2R4.1, 2R5.1, 2R6.1, D93.A, J86.2, SV4.11
B1: 2D1.15 (Y0), D51.C, D52.C, D54.C, D58.C, D64B.C
B2: D53.C, D60.C, D61.C, J46.2, J53.2
B2J: D57.C, J53.1
B3: D49.C, D56.C, D59.C, D65.C, J48.2
B3J: D67B.C, D68.C, J49.1, J83.1
B4: D67.C, D76.C, J50.1, J91.1
B4J: D66.C, D73.C, J50.2, J54.2
B4J2: D55.C, D63.C, J54.1
B5: D75.C, J51.1, J89.1
B5J: D62.C, D64.C, D71.C, D74.C, J51.2
B5J4: J89.2, J92.1
B5J5: 2D1.10 (Y5), D69.C, J92.2
B6: D81.C, D82.C, J55.2, J94.1
B6J2: D72.C, J55.1, J56.2
B6J3: D70.C, J56.1
B6J4: D83.C, J93.1, J94.2
B7: 2D1.13 (Y2), D86.C, D87.C, J52.1
B7J: D77.C, D78.C, D80.C, J52.2
B8: 2D1.12 (Y3), D88.C, J87.2
BD1: J72.2, SV4.8
BD2: J71.2, SV4.9
BD3: J70.2, SV4.10
FN2A: JB87.2, S87.SW2 (PIN-2), S87B.SW2 (PIN-2)
FN2B: JA87.1, S87.SW1 (PIN-1), S87B.SW1 (PIN-1)
FN3A: JB83.2, S83.SW2 (PIN-2), S83B.SW2 (PIN-2)
FN3B: JA83.1, S83.SW1 (PIN-1), S83B.SW1 (PIN-1)
G1: 2D2.9 (I), 2R1.2, JA47.2, JA48.2, JA49.2, JA53.2, JA60.2, JA68.2, JA75.2, JA82.2
G2: 2R2.2, J63.2, JA54.2, JA55.2, JA56.2, JA61.2, JA69.2, JA70.2, JA76.2, JA77.2
G3: J57.2, JA62.2, JA63.2, JA71.2
G4: J76.2, JA50.2, JA51.2, JA57.2, JA64.2, JA72.2, JA78.2, JA79.2, JA87.2
G5: J62.2, JA52.2, JA58.2, JA65.2, JA66.2, JA73.2, JA80.2, JA83.2, JA84.2
G6: J59.2, J84.2, JA74B.2
G6B: J84.1, J85.2
G6C: J85.1, JA59.2, JA67.2, JA67B.2, JA81.2, JA85.2, JA86.2, JB74.1
G11: 2D2.8 (O), J69.2
G12: J68.2, J69.1
G13: J67.2, J68.1
G14: J67.1, SV4.2
GG5: 2D2.11 (I), 2R5.2, J61.1
GND2: 2C1.2, 2C2.2, 2D1.4 (G2A), 2D1.5 (G2B), 2D1.8 (GND), 2D2.7 (GND), SV4.1
unnamed: JB52.2, S52.SW1 (PIN-1)
unnamed: 2D1.7 (Y7), J83.2
unnamed: JB63.2, S63.SW1 (PIN-1)
unnamed: 2C2.1, J86.1, R16.1
unnamed: JB74.2, S74A.SW1 (PIN-1)
unnamed: JA74.1, S74A.SW2 (PIN-2)
unnamed: JB47.2, S47.SW1 (PIN-1)
unnamed: JB53.2, S53.SW1 (PIN-1)
unnamed: JB60.2, S60.SW1 (PIN-1)
unnamed: JB68.2, S68.SW1 (PIN-1)
unnamed: JB75.2, S75.SW1 (PIN-1)
unnamed: JB82.2, S82.SW1 (PIN-1), S82A.SW2 (PIN-2)
unnamed: JB48.2, S48.SW1 (PIN-1)
unnamed: JB54.2, S54.SW1 (PIN-1)
unnamed: JB61.2, S61.SW1 (PIN-1)
unnamed: JB69.2, S69.SW1 (PIN-1)
unnamed: JB49.2, S49.SW1 (PIN-1)
unnamed: JB55.2, S55.SW1 (PIN-1)
unnamed: JB70.2, S70.SW1 (PIN-1)
unnamed: JB77.2, S77.SW1 (PIN-1)
unnamed: JB56.2, S56.SW1 (PIN-1)
unnamed: JB51.2, S51.SW1 (PIN-1)
unnamed: D49.A, JB47.1
unnamed: D55.A, JB53.1
unnamed: D62.A, JB60.1
unnamed: D70.A, JB68.1
unnamed: D77.A, JB75.1
unnamed: D84.A, JB82.1
unnamed: D50.A, JB48.1
unnamed: D56.A, JB54.1
unnamed: D63.A, JB61.1
unnamed: D71.A, JB69.1
unnamed: D78.A, JB76.1
unnamed: D85.A, JB83.1
unnamed: D51.A, JB49.1
unnamed: D57.A, JB55.1
unnamed: D64.A, JB62.1
unnamed: D72.A, JB70.1
unnamed: D79.A, JB77.1
unnamed: D86.A, JB84.1
unnamed: D52.A, JB50.1
unnamed: D58.A, JB56.1
unnamed: D65.A, JB63.1
unnamed: D73.A, JB71.1
unnamed: D80.A, JB78.1
unnamed: D87.A, JB85.1
unnamed: D53.A, JB51.1
unnamed: D59.A, JB57.1
unnamed: D66.A, JB64.1
unnamed: D74.A, JB72.1
unnamed: D81.A, JB79.1
unnamed: D88.A, JB86.1
unnamed: D54.A, JB52.1
unnamed: D60.A, JB58.1
unnamed: D67.A, JB65.1
unnamed: D75.A, JB73.1
unnamed: D82.A, JB80.1
unnamed: D61.A, JB59.1
unnamed: D68.A, JB66.1
unnamed: D69.A, JB67.1
unnamed: D83.A, JB81.1
unnamed: JA47.1, S47.SW2 (PIN-2)
unnamed: JA53.1, S53.SW2 (PIN-2)
unnamed: JA60.1, S60.SW2 (PIN-2)
unnamed: JA68.1, S68.SW2 (PIN-2)
unnamed: JA75.1, S75.SW2 (PIN-2)
unnamed: JA82.1, S82.SW2 (PIN-2), S82A.SW1 (PIN-1)
unnamed: JA48.1, S48.SW2 (PIN-2)
unnamed: JA54.1, S54.SW2 (PIN-2)
unnamed: JA61.1, S61.SW2 (PIN-2)
unnamed: JA69.1, S69.SW2 (PIN-2)
unnamed: JA49.1, S49.SW2 (PIN-2)
unnamed: JA55.1, S55.SW2 (PIN-2)
unnamed: JA70.1, S70.SW2 (PIN-2)
unnamed: JA77.1, S77.SW2 (PIN-2)
unnamed: JA56.1, S56.SW2 (PIN-2)
unnamed: JA63.1, S63.SW2 (PIN-2)
unnamed: JA51.1, S51.SW2 (PIN-2)
unnamed: JA52.1, S52.SW2 (PIN-2)
unnamed: D64B.A, JB74B.1
unnamed: 2D1.11 (Y4), J93.2
unnamed: JA67B.1, S67C.SW1 (PIN-1)
unnamed: D76.A, JA74.2
unnamed: JB67.2, S67.SW2 (PIN-2)
unnamed: JA67.1, S67.SW1 (PIN-1)
unnamed: JB81.2, S81.SW2 (PIN-2)
unnamed: JA81.1, S81.SW1 (PIN-1)
unnamed: JB59.2, S59.SW2 (PIN-2)
unnamed: JA59.1, S59.SW1 (PIN-1)
unnamed: JB85.2, S85.SW2 (PIN-2)
unnamed: JA85.1, S85.SW1 (PIN-1)
unnamed: JB74B.2, S74.SW2 (PIN-2)
unnamed: JA74B.1, S74.SW1 (PIN-1)
unnamed: 2D1.9 (Y6), J90.2
unnamed: D89.A, JB87.1
unnamed: JB50.2, S50.SW2 (PIN-2)
unnamed: JA50.1, S50.SW1 (PIN-1)
unnamed: JB78.2, S78.SW2 (PIN-2)
unnamed: JA78.1, S78.SW1 (PIN-1)
unnamed: D67B.A, JB67B.1
unnamed: JB58.2, S58.SW2 (PIN-2)
unnamed: JB65.2, S65.SW2 (PIN-2)
unnamed: JA65.1, S65.SW1 (PIN-1)
unnamed: JA58.1, S58.SW1 (PIN-1)
unnamed: JB66.2, S66.SW1 (PIN-1)
unnamed: JA66.1, S66.SW2 (PIN-2)
unnamed: JB79.2, S79.SW2 (PIN-2)
unnamed: JA79.1, S79.SW1 (PIN-1)
unnamed: JB73.2, S73.SW2 (PIN-2)
unnamed: JA73.1, S73.SW1 (PIN-1)
unnamed: JA80.1, S80.SW1 (PIN-1)
unnamed: JB80.2, S80.SW2 (PIN-2)
unnamed: JB84.2, S84.SW2 (PIN-2)
unnamed: JA84.1, S84.SW1 (PIN-1)
unnamed: JB57.2, S57.SW2 (PIN-2)
unnamed: JA57.1, S57.SW1 (PIN-1)
unnamed: JA64.1, S64.SW1 (PIN-1)
unnamed: JB64.2, S64.SW2 (PIN-2)
unnamed: JB72.2, S72.SW2 (PIN-2)
unnamed: JA72.1, S72.SW1 (PIN-1)
unnamed: J48.1, J49.2
unnamed: JB62.2, S62.SW2 (PIN-2)
unnamed: JA62.1, S62.SW1 (PIN-1)
unnamed: JB71.2, S71.SW1 (PIN-1)
unnamed: JA71.1, S71.SW2 (PIN-2)
unnamed: 2D1.6 (G1), R16.2
unnamed: JB76.2, S76.SW2 (PIN-2)
unnamed: JA76.1, S76.SW1 (PIN-1)
unnamed: 2D2.6 (O), SV4.7
unnamed: 2D2.4 (O), SV4.6
unnamed: 2D2.2 (O), SV4.5
unnamed: 2D2.12 (O), J64.2
unnamed: J57.1, J58.2
unnamed: J59.1, J60.2
unnamed: 2D2.1 (I), J63.1
unnamed: J64.1, SV4.4
unnamed: J65.1, SV4.3
unnamed: J65.2, J66.1
unnamed: 2D2.10 (O), J66.2
unnamed: D92.A, D93.C
unnamed: J70.1, J73.2
unnamed: J71.1, J74.2
unnamed: J72.1, J75.2
unnamed: J73.1, J77.2
unnamed: J74.1, J78.2
unnamed: J75.1, J79.2
unnamed: J79.1, J80.2
unnamed: J77.1, J81.2
unnamed: J78.1, J82.2
unnamed: 2D1.1 (A), J80.1
unnamed: 2D1.2 (B), J82.1
unnamed: 2D1.3 (C), J81.1
unnamed: JB86.2, S86.SW1 (PIN-1)
unnamed: JA86.1, S86.SW2 (PIN-2)
unnamed: J90.1, J91.2
unnamed: J46.1, J95.2
unnamed: JB67B.2, S67C.SW2 (PIN-2)
PG3: 2D2.3 (I), 2R3.2, J58.1
PG4: 2D2.5 (I), 2R4.2, J76.1
PG5: J61.2, J62.1
PG6: 2D2.13 (I), 2R6.2, J60.1

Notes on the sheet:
kbb6
kbb5
kbb4
kbb3
kbb2
kbb1
gnd
vcc

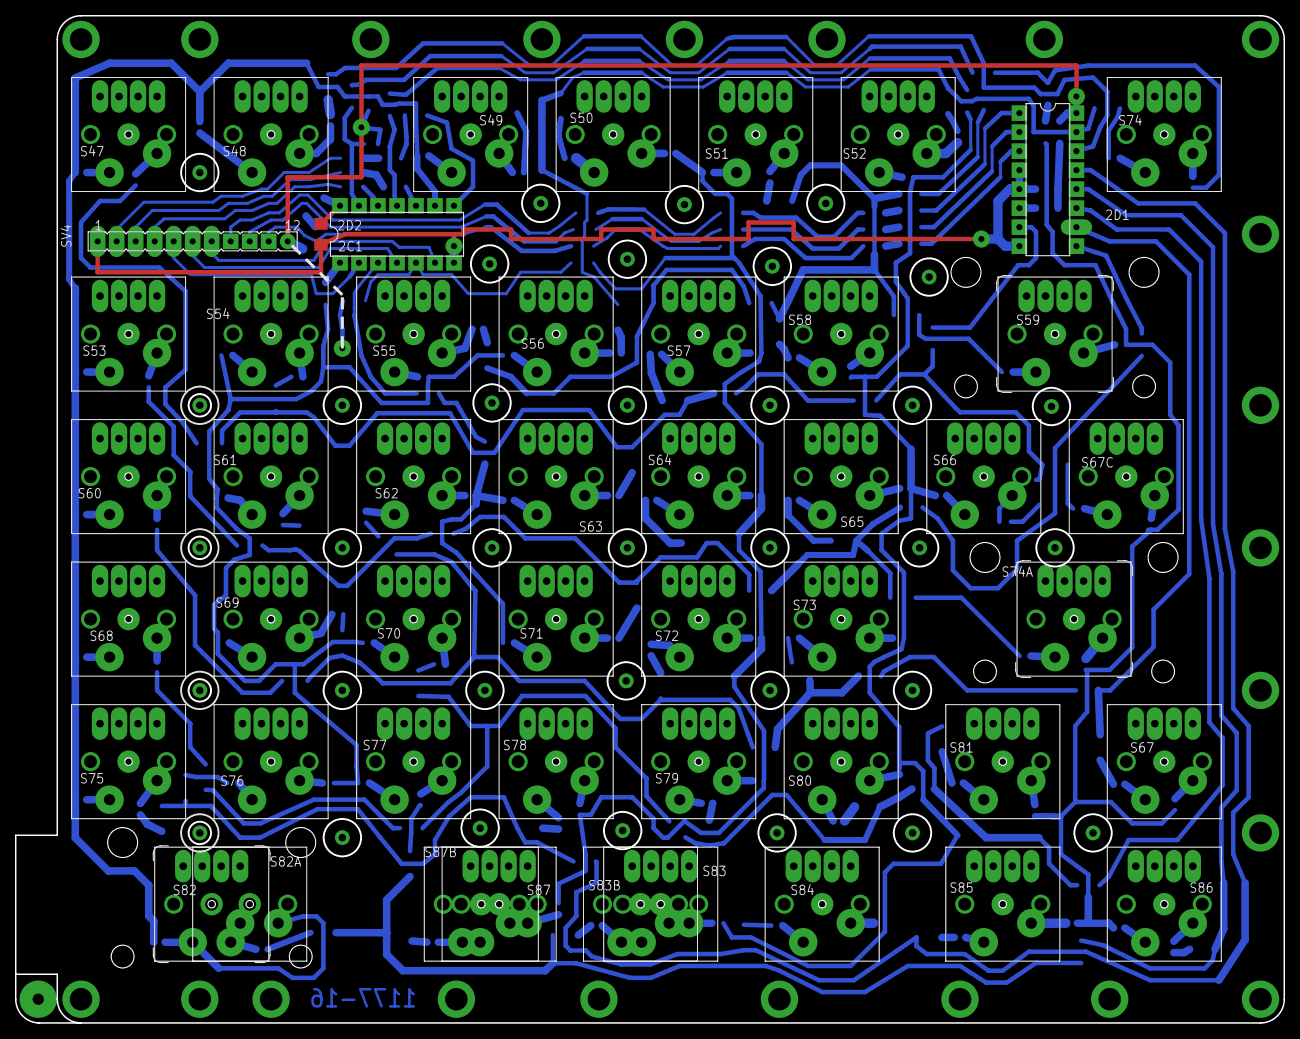
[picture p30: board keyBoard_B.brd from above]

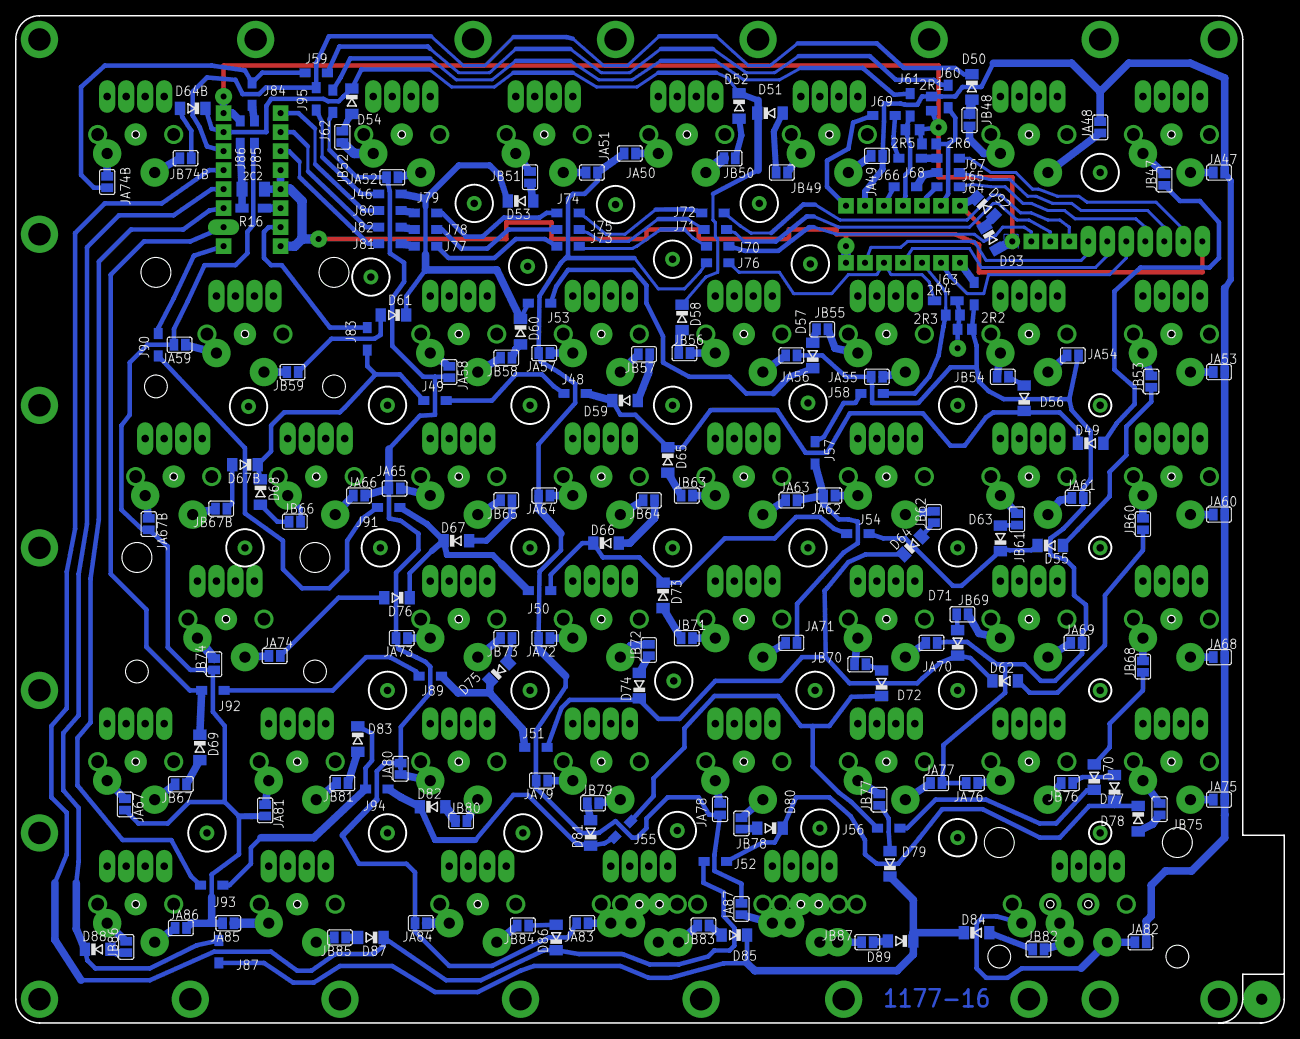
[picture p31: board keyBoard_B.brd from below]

Board: 2 copper layers, 169.5 x 134.6 mm, 284 parts (8 on the bottom side), 205 nets.

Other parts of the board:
U$1, U$4, U$90, U$92: 18X23
U$2, U$53, U$54, U$55, U$56, U$57, U$58, U$59, U$60, U$61, U$62, U$63, U$64, U$65, U$66, U$67, U$68, U$69, U$70, U$71, U$72, U$73, U$74, U$75, U$76, U$77, U$78, U$79, U$80, U$81, U$83, U$84, U$85, U$86, U$89, U$95: 18X18
U$5: 18X37
U$87: 18X52
U$94, U$105: 18X42

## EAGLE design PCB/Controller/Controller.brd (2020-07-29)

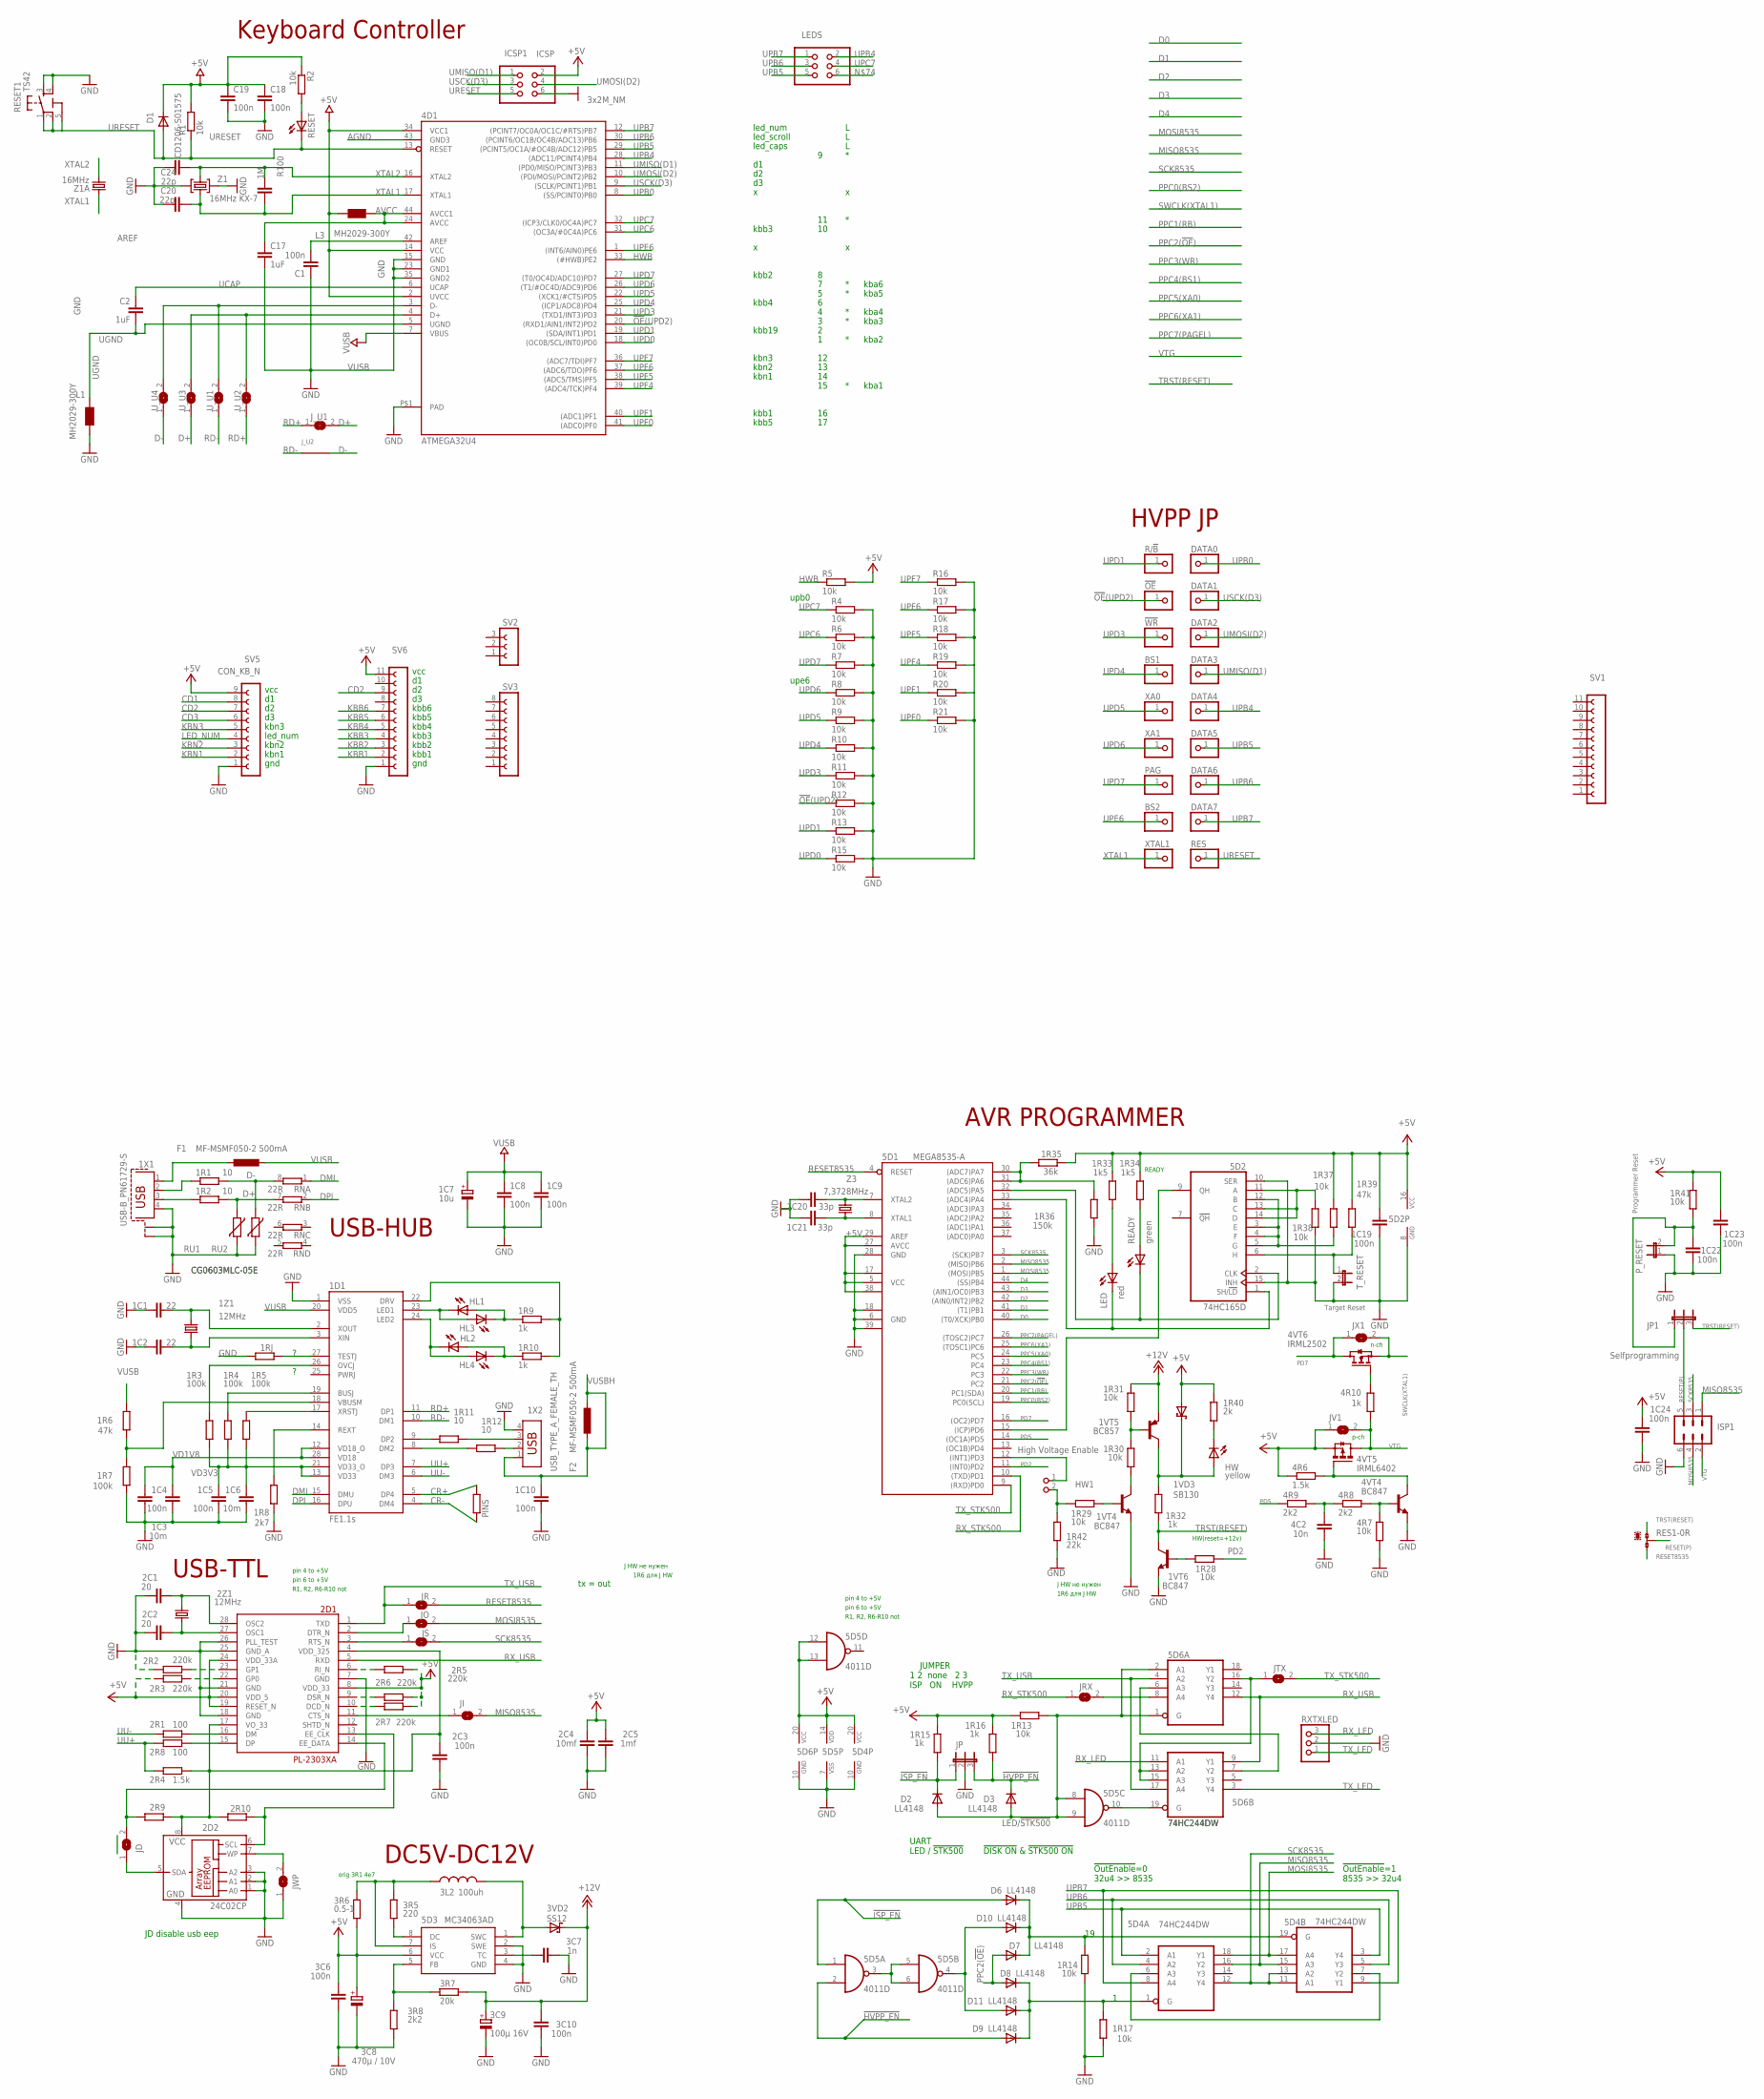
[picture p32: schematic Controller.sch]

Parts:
1C1, 1C2: 22; C0603
1C3, 1C6: 10m; C1206
1C4, 1C5, 1C8, 1C9, 1C10, 1C19, 1C22, 1C23, 1C24, 2C3: 100n; C0805
1C7: 10u; SMC_B
1C20, 1C21: 33p; C0805
1D1: FE1.1S; FE1.1S_SSOP-28
1R1, 1R2, 1R11, 1R12: 10; R0603
1R3, 1R4, 1R7: 100k; R0805
1R5: 100k; R1206W
1R6: 47k; R1206W
1R8: 2k7; R0805
1R9, 1R10: 1k; R0805
1R13, 1R14, 1R17, 1R29, 1R30, 1R31, 1R37, 1R38, 1R41, 4R7: 10k; M0805
1R15, 1R16, 1R32, 4R10: 1k; M0805
1R28: 10k; R0805
1R33, 1R34: 1k5; M0805
1R35: 36k; M0805
1R36: 150k; R1206
1R39: 47k; M0805
1R40: 2k; R1206W
1R42: 22k; M1206
1RJ, 2R9, 2R10: R-EU_R0805; R0805
1VD3: SB130; SMB
1VT4, 1VT6, 4VT4: BC847; SOT23
1VT5: BC857; SOT23-BEC
1X1: USB-B_PN61729-S
1X2: USB_TYPE_A_FEMALE_TH
1Z1, 2Z1: 12MHz; HC49/S
2C1, 2C2: 20; C0805
2C4: 10mf; C1210
2C5: 1mf; C0805
2D1: PL-2303XA; SSOP28DB
2D2: 24C02CP; DIL8; MPN 24C02C/P
2R1, 2R8: 100; R0603
2R2, 2R6, 2R7: 220k; R0603
2R3, 2R5: 220k; R1206W
2R4: 1.5k; R0603
3C6: 100n; C025-024X044
3C7: 1n; C025-025X050
3C8: 470µ / 10V; RCL_E3,5-8
3C9: 100µ 16V; RCL_E3,5-8
3C10: 100n; C025-025X050
3L2: 100uh; 0207/10
3R5: 220; R1206
3R6: 0.5-1; M1206
3R7: 20k; M0805
3R8, 4R9: 2k2; M0805
3VD2: SS12; SMB
4C2: 10n; C1206
4D1: ATMEGA32U4; SMARTPRJ_TQFP44-PAD
4R6: 1.5k; M0805
4R8: 2k2; M1206
4VT5: IRML6402; SUPER-SOT3
4VT6: IRML2502; SOT23
5D1: MEGA8535-A; TQFP44
5D2: 74HC165D; SO16
5D3: MC34063AD; SOIC8
5D4, 5D6: 74HC244DW; SO20W
5D5: 4011D; SO14
!OE: PINHD-1X1; 1X01
!WR: PINHD-1X1; 1X01
BS1, BS2: PINHD-1X1; 1X01
C1, C19: 100n; C0603-ROUND
C2: 1uF; C0603
C17: 1uF; C0603-ROUND
C18: 100n; C0603
C20, C24: 22p; C0603
D1: CD1206-S01575; MINIMELF
D2, D3, D6, D7, D8, D9, D10, D11: LL4148; SOD80C
DATA0, DATA1, DATA2, DATA3, DATA4, DATA5, DATA6, DATA7: PINHD-1X1; 1X01
F1, F2: MF-MSMF050-2 500mA; L1812
HL1, HL2, HL3, HL4: LEDSML0603; SML0603
HW: yellow; SML0603
HW1: High Voltage Enable; PINHEAD_1X02
ICSP1: ICSP; 2X03
ISP1: MA03-2
JD: SJ
JI: SJ
JO: SJ
JP: JP2E; JP2
JP1: Selfprogramming; JUMPER_JP2
JR: SJ
JRX: SJ
JS: SJ
JTX: SJ
JV1: SJ
JWP: SJ
JX1: SJ
J_U1: SJ
J_U2: J; R1206W
L1, L3: MH2029-300Y; 0805
LED: red; SML0603
LEDS: PINHD-2X3; 2X03
PAG: PINHD-1X1; 1X01
PINS: R-EU_R0805; R0805
P_RESET: JP1E; JP1
R1, R2, R4, R6, R7, R8, R9, R10, R11, R12, R13, R15, R16, R17, R18, R19, R20, R21: 10k; M0805
R5: 10k; M1206
R100: 1M; C0805
R/!B: PINHD-1X1; 1X01
READY: green; SML0603
RES: PINHD-1X1; 1X01
RES1: 0R-JUMPA; A0R-JMP
RESET: LEDSML0805; SML0805
RESET1: TS42
RN: 22R; CAY16
RU1, RU2: CG0603MLC-05E; CT/CN0603
RXTXLED: PINHD-1X3; 1X03
SV1, SV6: FE12-1; FE12
SV2: FE03-1
SV3: FE08-1; FE08
SV5: CON_KB_N; FE09
T_RESET: JP1E; JP1
U_U1, U_U2, U_U3, U_U4: SJ
XA0, XA1: PINHD-1X1; 1X01
XTAL1: PINHD-1X1; 1X01
Z1: 16MHz KX-7; CRYSTAL-3.2-2.5
Z1A: 16MHz; HC49/S
Z3: 7,3728MHz; HC49U-V

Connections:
3VUSB2: 2C3.1, 2D1.4 (VDD_325), 2D1.17 (VO_33), 2D2.8 (VCC), 2R4.1, 2R9.2, 2R10.2
!HVPP_EN: 1R16.1, 5D5.2 (I1), D3.C, D9.A, JP.3
!ISP_EN: 1R15.1, 5D5.1 (I0), D2.C, D6.A, JP.1
!OE741: 1R17.2, 5D4.1 (G), D8.C, D9.C, D11.C
!OE!(UPD2): 4D1.20 ((RXD1/AIN1/INT2)PD2), !OE.1, R12.1
+5V: 1C19.1, 1C23.2, 1C24.2, 1R13.2, 1R15.2, 1R16.2, 1R33.2, 1R34.2, 1R35.2, 1R37.1, 1R39.1, 1R40.2, 1R41.2, 1VD3.A, 2C4.2, 2C5.2, 2D1.8 (VDD_33), 2D1.19 (RESET_N), 2D1.20 (VDD_5), 2D1.24 (VDD_33A), 2R3.1, 2R5.2, 2R6.1, 2R7.1, 3C6.1, 3C8.+, 3R6.1, 4D1.2 (UVCC), 4D1.14 (VCC), 4D1.34 (VCC1), 4R6.1, 4VT5.2 (S), 5D1.5 (VCC), 5D1.17 (VCC1), 5D1.27 (AVCC), 5D1.29 (AREF), 5D1.38 (VCC2), 5D2.16 (VCC), 5D3.6 (VCC), 5D4.20 (VCC), 5D5.12 (I0), 5D5.13 (I1), 5D5.14 (VDD), 5D6.20 (VCC), C18.1, C19.1, D1.C, ICSP1.2, JV1.1, L3.1, R1.2, R2.1, R5.2, SV5.9, SV6.11
+12V: 1R31.2, 1VT5.E, 3C9.+, 3C10.2, 3R7.2, 3VD2.C
AGND: 4D1.43 (GND3)
AREF: 4D1.42 (AREF), C1.2
AVCC: 4D1.24 (AVCC), 4D1.44 (AVCC1), C17.1, L3.2
CD1: SV5.8
CD2: SV5.7, SV6.9
CD3: SV5.6
CR+: 1D1.5 (DP4), PINS.2
CR-: 1D1.4 (DM4), PINS.1
D0: 5D1.40 ((T0/XCK)PB0)
D1: 5D1.41 ((T1)PB1)
D2: 5D1.42 ((AIN0/INT2)PB2)
D3: 5D1.43 ((AIN1/OC0)PB3)
D4: 5D1.44 ((SS)PB4)
D+: 1R2.2, J_U1.2, RN.7 (2), RU1.1, U_U3.1
D-: 1R1.2, J_U2.1, RN.8 (2), RU2.1, U_U4.1
DMI: 1D1.15 (DMU), RN.1
DPI: 1D1.16 (DPU), RN.2 (1)
GND: 1C1.1, 1C2.1, 1C3.2, 1C4.2, 1C5.2, 1C6.2, 1C7.-, 1C8.1, 1C9.1, 1C10.2, 1C19.2, 1C20.1, 1C21.1, 1C22.1, 1C23.1, 1C24.1, 1D1.1 (VSS), 1R7.1, 1R8.1, 1R14.1, 1R17.1, 1R36.1, 1R38.1, 1R42.1, 1RJ.2, 1VT4.2 (E), 1VT6.2 (E), 1X1.4, 1X1.S1, 1X1.S2, 1X2.4, 2C1.1, 2C2.1, 2C3.2, 2C4.1, 2C5.1, 2D1.7 (GND), 2D1.18 (GND), 2D1.21 (GND), 2D1.25 (GND_A), 2D1.26 (PLL_TEST), 2D2.1 (A0), 2D2.2 (A1), 2D2.3 (A2), 2D2.4 (GND), 2R2.1, 3C6.2, 3C7.2, 3C8.-, 3C9.-, 3C10.1, 3R8.1, 4C2.1, 4D1.15 (GND), 4D1.23 (GND1), 4D1.35 (GND2), 4D1.P$1 (PAD), 4R7.1, 4VT4.2 (E), 5D1.6 (GND), 5D1.18 (GND1), 5D1.28 (GND), 5D1.39 (GND2), 5D2.8 (GND), 5D2.10 (SER), 5D2.15 (INH), 5D3.2 (SWE), 5D3.4 (GND), 5D4.10 (GND), 5D5.7 (VSS), 5D6.10 (GND), C1.1, C17.2, C18.2, C19.2, C20.1, C24.2, ICSP1.6, ISP1.6, JP.2, JWP.1, L1.2, P_RESET.1, R4.2, R6.2, R7.2, R8.2, R9.2, R10.2, R11.2, R12.2, R13.2, R15.2, R16.2, R17.2, R18.2, R19.2, R20.2, R21.2, RESET1.3, RESET1.4, RU1.2, RU2.2, RXTXLED.2, SV5.1, SV6.1, T_RESET.2, Z1.2 (GND), Z1.4 (GND)
HWB: 4D1.33 ((#HWB)PE2), R5.1
ID+: 1R2.1, 1X1.3
ID-: 1R1.1, 1X1.2
KBB1: SV6.2
KBB2: SV6.3
KBB3: SV6.4
KBB4: SV6.5
KBB5: SV6.6
KBB6: SV6.7
KBN1: SV5.2
KBN2: SV5.3
KBN3: SV5.5
LED/!STK500: 1R13.1, 5D5.8 (I0), 5D5.9 (I1), 5D6.1 (G), 5D6.2 (A1), D2.A, D3.A
LED_NUM: SV5.4
MISO8535: 5D1.2 ((MISO)PB6), 5D4.15 (A3), 5D4.16 (Y2), ISP1.1, JI.2
MOSI8535: 5D1.1 ((MOSI)PB5), 5D4.17 (A4), 5D4.18 (Y1), ISP1.4, JO.2
N1: 5D1.33 ((ADC4)PA4), 5D2.1 (SH/!LD), LED.C
unnamed: 5D5.10 (O), 5D6.19 (G)
unnamed: R2.2, RESET.A
unnamed: 5D4.6 (A3), 5D4.7 (Y2)
unnamed: 1D1.9 (DP2), 1R11.1
unnamed: 1D1.8 (DM2), 1R12.1
unnamed: 1X1.1, F1.2
unnamed: 1C1.2, 1D1.2 (XOUT), 1Z1.1
unnamed: 1C2.2, 1D1.3 (XIN), 1Z1.2
unnamed: 1D1.17 (XRSTJ), 1R5.2
unnamed: 1D1.22 (DRV), 1R9.2, 1R10.2
unnamed: 1R11.2, 1X2.3
unnamed: 1R12.2, 1X2.2
unnamed: 1D1.23 (LED1), HL1.C, HL3.A
unnamed: 1D1.19 (BUSJ), 1R4.2
unnamed: 1D1.18 (VBUSM), 1R6.1, 1R7.2
unnamed: 1D1.24 (LED2), HL2.C, HL4.A
unnamed: 1R10.1, HL2.A, HL4.C
unnamed: 1D1.26 (OVCJ), 1R3.2
unnamed: 4D1.4 (D+), U_U2.2, U_U3.2
unnamed: 1D1.14 (REXT), 1R8.2
unnamed: 5D6.13 (A2), 5D6.15 (A3), 5D6.16 (Y2), JTX.1
unnamed: 1D1.27 (TESTJ), 1RJ.1
unnamed: 5D6.8 (A4), JRX.2
unnamed: 4D1.3 (D-), U_U1.2, U_U4.2
unnamed: 5D6.6 (A3), 5D6.7 (Y2)
unnamed: 2D2.5 (SDA), JD.1
unnamed: 1R34.1, READY.A
unnamed: 5D5.3 (O), 5D5.5 (I0), 5D5.6 (I1)
unnamed: 1R9.1, HL1.A, HL3.C
unnamed: 1R35.1, 1R36.2, 5D1.30 ((ADC7)PA7), 5D1.31 ((ADC6)PA6)
unnamed: 5D1.32 ((ADC5)PA5), 5D2.2 (CLK), READY.C
unnamed: 1R39.2, 5D2.6 (H), T_RESET.1
unnamed: 5D1.12 ((INT1)PD3), HW1.1
unnamed: 1R29.2, 1R42.2, HW1.2
unnamed: 2D2.7 (WP), JWP.2
unnamed: 1R32.2, 1VD3.C, 1VT5.C, HW.A
unnamed: 1R29.1, 1VT4.1 (B)
unnamed: 1R14.2, 5D4.19 (G), D6.C, D7.C, D10.C
unnamed: 1R30.1, 1VT4.3 (C)
unnamed: 1R30.2, 1R31.1, 1VT5.B
unnamed: 5D1.15 ((ICP)PD6), 5D2.9 (QH)
unnamed: 1R33.1, LED.A
unnamed: 1R38.2, 5D2.11 (A), 5D2.13 (C), 5D2.14 (D)
unnamed: 2D1.15 (DP), 2R8.2
unnamed: 2D1.16 (DM), 2R1.2
unnamed: 2D1.23 (GP1), 2R2.2
unnamed: 2D1.22 (GP0), 2R3.2
unnamed: 2C1.2, 2D1.28 (OSC2), 2Z1.2
unnamed: 2C2.2, 2D1.27 (OSC1), 2Z1.1
unnamed: 2D1.6 (RI_N), 2R5.1
unnamed: 2D1.9 (DSR_N), 2R6.2
unnamed: 2D1.10 (DCD_N), 2R7.2
unnamed: 2D1.11 (CTS_N), JI.1
unnamed: 2D1.3 (RTS_N), JS.1
unnamed: 2D1.2 (DTR_N), JO.1
unnamed: 1R37.2, 5D2.3 (E), 5D2.4 (F), 5D2.5 (G), 5D2.12 (B)
unnamed: 2D1.14 (EE_DATA), 2R9.1, JD.2
unnamed: 2D1.13 (EE_CLK), 2D2.6 (SCL), 2R10.1
unnamed: 1R28.2, 1VT6.1 (B)
unnamed: 3R5.1, 5D3.8 (DC)
unnamed: 3L2.1, 3R5.2, 3R6.2, 5D3.7 (IS)
unnamed: 5D5.4 (O), D10.A, D11.A
unnamed: 3R7.1, 3R8.2, 5D3.5 (FB)
unnamed: 3L2.2, 3VD2.A, 5D3.1 (SWC)
unnamed: 3C7.1, 5D3.3 (TC)
unnamed: 1C20.2, 5D1.7 (XTAL2), Z3.2
unnamed: 1C21.2, 5D1.8 (XTAL1), Z3.1
unnamed: 4R6.2, 4VT4.3 (C), 4VT5.1 (G)
unnamed: 4R7.2, 4R8.2, 4VT4.1 (B)
unnamed: 4C2.2, 4R8.1, 4R9.2
unnamed: 1R40.1, HW.C
unnamed: 4R10.2, 4VT6.1 (G)
PD2: 1R28.1, 5D1.11 ((INT0)PD2)
PD5: 4R9.1, 5D1.14 ((OC1A)PD5)
PD7: 4VT6.3 (D), 5D1.16 ((OC2)PD7), JX1.1
PPC0(BS2): 5D1.19 (PC0(SCL))
PPC1(RB): 5D1.20 (PC1(SDA))
PPC2(!OE!): 5D1.21 (PC2), D7.A, D8.A
PPC3(WR): 5D1.22 (PC3)
PPC4(BS1): 5D1.23 (PC4)
PPC5(XA0): 5D1.24 (PC5)
PPC6(XA1): 5D1.25 ((TOSC1)PC6)
PPC7(PAGEL): 5D1.26 ((TOSC2)PC7)
RD+: 1D1.11 (DP1), J_U1.1, U_U2.1
RD-: 1D1.10 (DM1), J_U2.2, U_U1.1
RESET8535: 1C22.2, 1R41.1, 5D1.4 (RESET), JP1.1, JR.2, P_RESET.2, RES1.3
RESET(P): ISP1.5, JP1.2, RES1.2
RX_LED: 5D6.11 (A1), RXTXLED.3
RX_STK500: 5D1.10 ((TXD)PD1), JRX.1
RX_USB: 2D1.5 (RXD), 5D6.9 (Y1), 5D6.12 (Y4)
SCK8535: 5D1.3 ((SCK)PB7), 5D4.11 (A1), 5D4.12 (Y4), 5D4.13 (A2), ISP1.3, JS.2
SWCLK(XTAL1): 4VT6.2 (S), JX1.2
TRST(RESET): 1R32.1, 1VT6.3 (C), JP1.3, RES1.1
TX_LED: 5D6.3 (Y4), RXTXLED.1
TX_STK500: 5D1.9 ((RXD)PD0), JTX.2
TX_USB: 2D1.1 (TXD), 5D6.4 (A2), 5D6.17 (A4), JR.1
UCAP: 4D1.6 (UCAP), C2.1
UGND: 4D1.5 (UGND), C2.2, L1.1
UMISO(D1): 4D1.11 ((PD0/MISO/PCINT3)PB3), DATA3.1, ICSP1.1
UMOSI(D2): 4D1.10 ((PDI/MOSI/PCINT2)PB2), DATA2.1, ICSP1.4
UPB0: 4D1.8 ((SS/PCINT0)PB0), DATA0.1
UPB4: 4D1.28 ((ADC11/PCINT4)PB4), DATA4.1, LEDS.2
UPB5: 4D1.29 ((PCINT5/OC1A/#OC4B/ADC12)PB5), 5D4.2 (A1), 5D4.3 (Y4), DATA5.1, LEDS.5
UPB6: 4D1.30 ((PCINT6/OC1B/OC4B/ADC13)PB6), 5D4.4 (A2), 5D4.5 (Y3), DATA6.1, LEDS.3
UPB7: 4D1.12 ((PCINT7/OC0A/OC1C/#RTS)PB7), 5D4.8 (A4), 5D4.9 (Y1), DATA7.1, LEDS.1
UPC6: 4D1.31 ((OC3A/#0C4A)PC6), R6.1
UPC7: 4D1.32 ((ICP3/CLK0/OC4A)PC7), LEDS.4, R4.1
UPD0: 4D1.18 ((OC0B/SCL/INT0)PD0), R15.1
UPD1: 4D1.19 ((SDA/INT1)PD1), R13.1, R/!B.1
UPD3: 4D1.21 ((TXD1/INT3)PD3), !WR.1, R11.1
UPD4: 4D1.25 ((ICP1/ADC8)PD4), BS1.1, R10.1
UPD5: 4D1.22 ((XCK1/#CTS)PD5), R9.1, XA0.1
UPD6: 4D1.26 ((T1/#OC4D/ADC9)PD6), R8.1, XA1.1
UPD7: 4D1.27 ((T0/OC4D/ADC10)PD7), PAG.1, R7.1
UPE6: 4D1.1 ((INT6/AIN0)PE6), BS2.1
UPF0: 4D1.41 ((ADC0)PF0), R21.1
UPF1: 4D1.40 ((ADC1)PF1), R20.1
UPF4: 4D1.39 ((ADC4/TCK)PF4), R19.1
UPF5: 4D1.38 ((ADC5/TMS)PF5), R18.1
UPF6: 4D1.37 ((ADC6/TDO)PF6), R17.1
UPF7: 4D1.36 ((ADC7/TDI)PF7), R16.1
URESET: 4D1.13 (RESET), D1.A, ICSP1.5, R1.1, RES.1, RESET.C, RESET1.1, RESET1.2, RESET1.5 (5-GND)
USCK(D3): 4D1.9 ((SCLK/PCINT1)PB1), DATA1.1, ICSP1.3
UU+: 1D1.7 (DP3), 2R4.2, 2R8.1
UU-: 1D1.6 (DM3), 2R1.1
VD1V8: 1C3.1, 1C4.1, 1D1.12 (VD18_O), 1D1.28 (VD18)
VD3V3: 1C5.1, 1C6.1, 1D1.13 (VD33), 1D1.21 (VD33_O), 1R3.1, 1R4.1, 1R5.1
VTG: 4R10.1, 4VT5.3 (D), ISP1.2, JV1.2
VUSB: 1C7.+, 1C8.2, 1C9.2, 1D1.20 (VDD5), 1R6.2, 4D1.7 (VBUS), F1.1
VUSBH: 1C10.1, 1X2.1, F2.1, F2.2
XTAL1: 4D1.17 (XTAL1), C20.2, R100.2, XTAL1.1, Z1.3 (C2), Z1A.2
XTAL2: 4D1.16 (XTAL2), C24.1, R100.1, Z1.1 (C1), Z1A.1

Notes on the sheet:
kbn1
kbn2
kbn3
led_num
kbb1
kbb2
kbb3
kbb4
kbb5
kbb6
gnd
vcc
pin 4 to +5V
R1, R2, R6-R10 not
pin 6 to +5V
J HW не нужен
1R6 для J HW
USB-HUB
kbb19
led_caps
led_scroll
USB-TTL
Target Reset
Programmer Reset
orig 3R1 4e7
HW(reset=+12v)
READY
n-ch
p-ch
HVPP JP
upe6
upb0
kba1
kba2
kba3
kba4
kba5
kba6
DC5V-DC12V
!DISK ON! & !STK500 ON

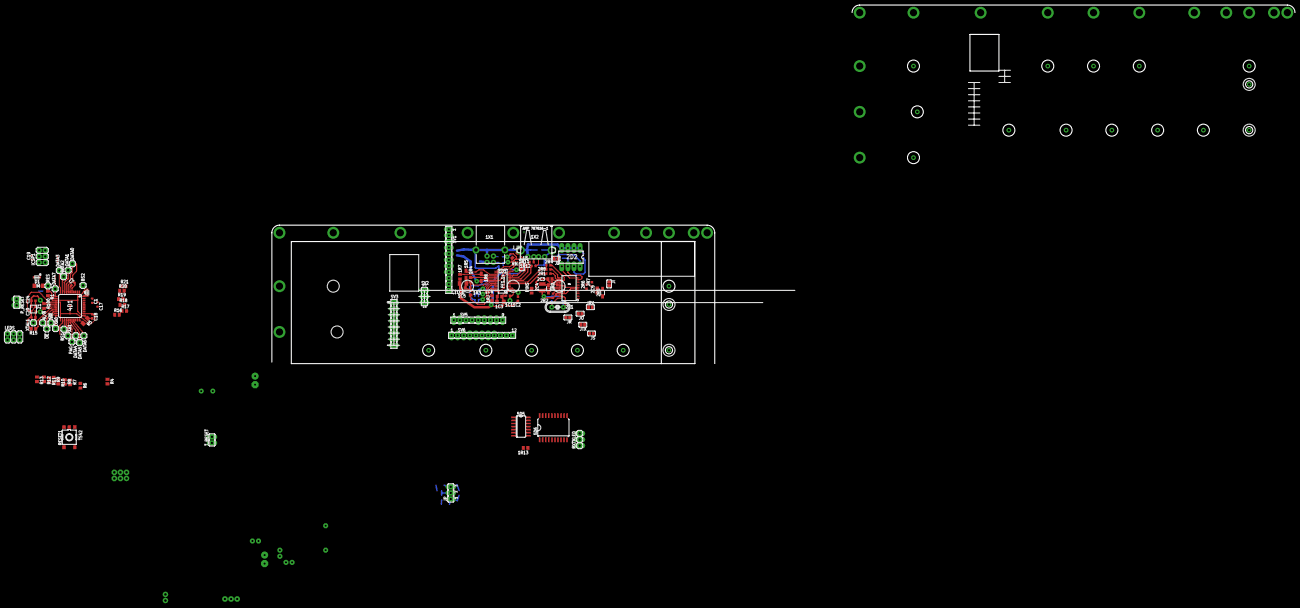
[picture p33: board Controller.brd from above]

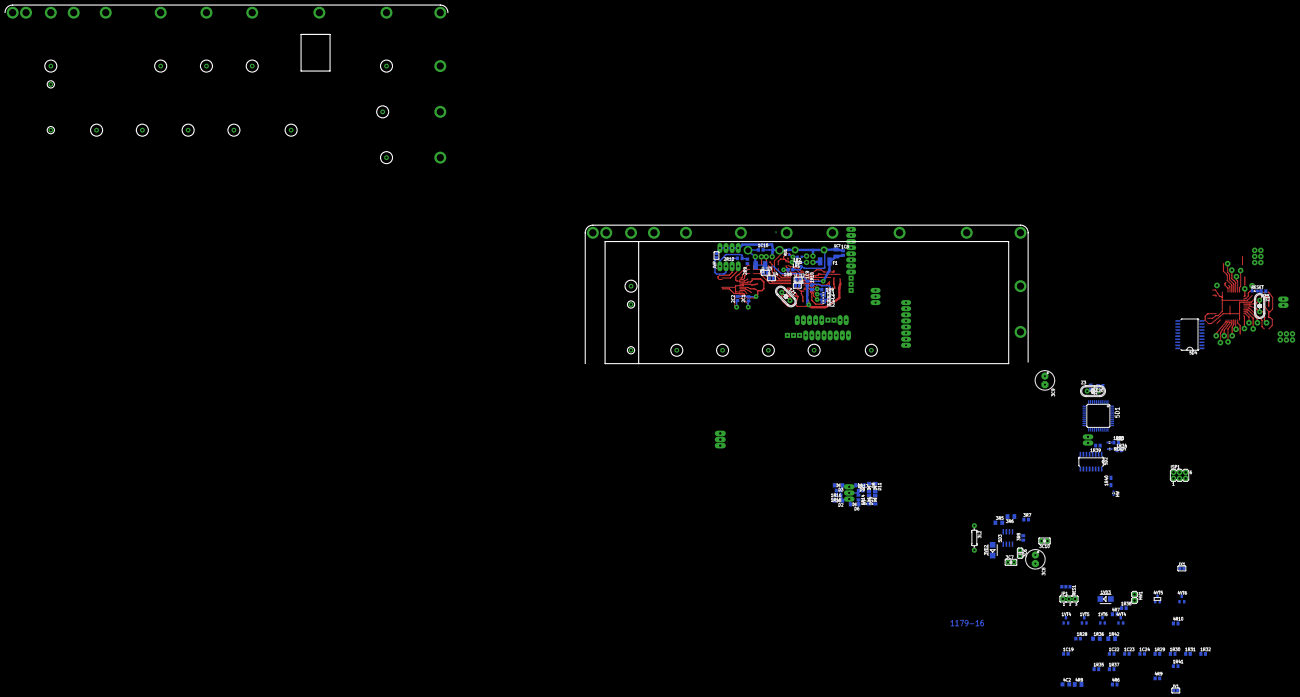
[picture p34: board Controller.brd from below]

Board: 2 copper layers, 208 parts (94 on the bottom side), 149 nets.

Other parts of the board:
U$3: U235

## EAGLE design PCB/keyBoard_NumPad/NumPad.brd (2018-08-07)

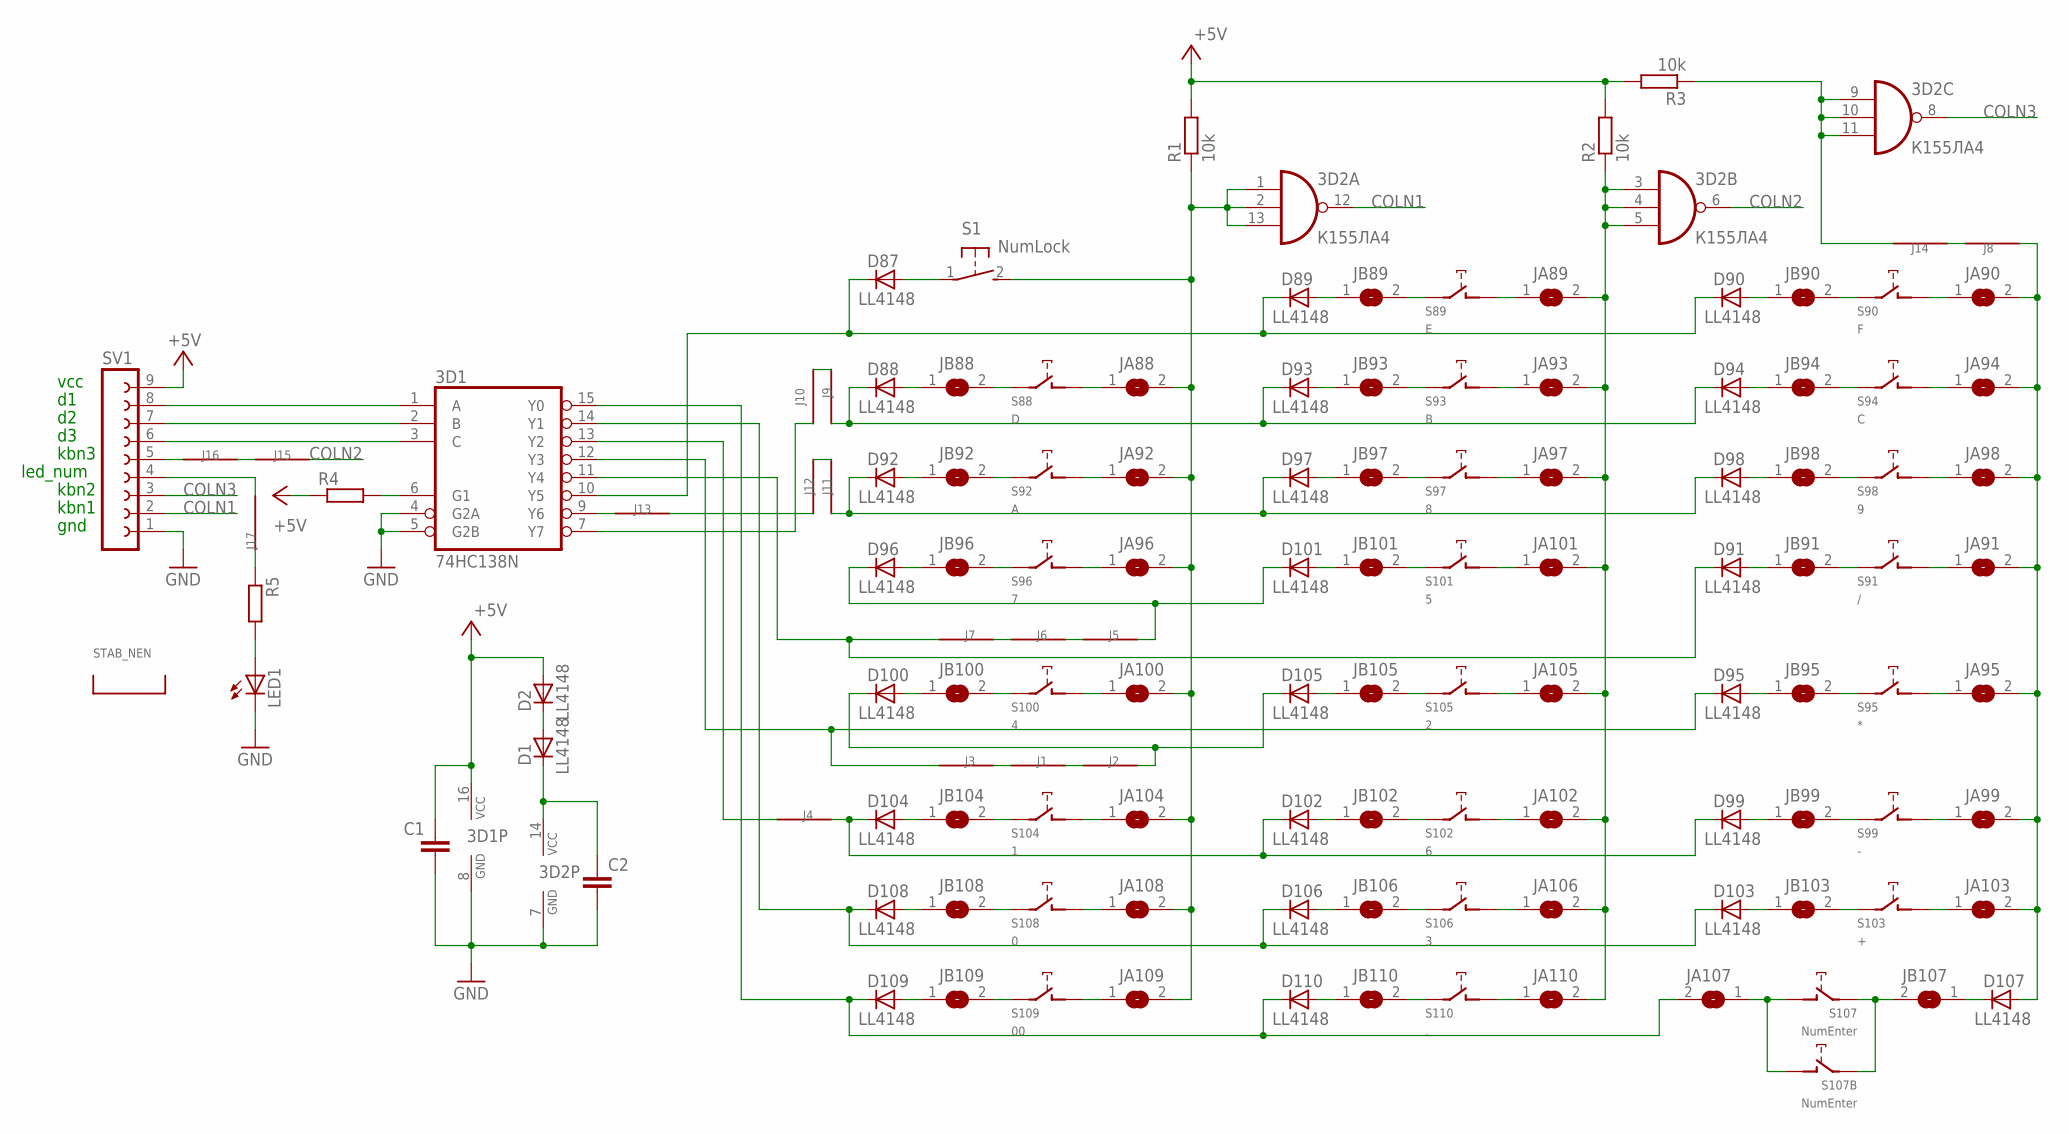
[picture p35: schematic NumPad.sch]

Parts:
3D1: 74HC138N; DIL16
3D2: К155ЛА4; DIL14
C1, C2: C-EUC1206; C1206
D1, D2, D87, D88, D89, D90, D91, D92, D93, D94, D95, D96, D97, D98, D99, D100, D101, D102, D103, D104, D105, D106, D107, D108, D109, D110: LL4148; SOD80C
J1, J2, J3, J4, J5, J6, J7, J8, J9, J10, J11, J12, J13, J14, J15, J16, J17: J; R1206W
JA88, JA89, JA90, JA91, JA92, JA93, JA94, JA95, JA96, JA97, JA98, JA99, JA100, JA101, JA102, JA103, JA104, JA105, JA106, JA107, JA108, JA109, JA110: SJ
JB88, JB89, JB90, JB91, JB92, JB93, JB94, JB95, JB96, JB97, JB98, JB99, JB100, JB101, JB102, JB103, JB104, JB105, JB106, JB107, JB108, JB109, JB110: SJ
LED1: LED5MM
R1, R2, R3: 10k; R1206W
R4, R5: R-EU_R1206W; R1206W
S1: NumLock; B3F-31XX
S88: D; CHERRY-MX-4P
S89: E; CHERRY-MX-4P
S90: F; CHERRY-MX-4P
S91: /; CHERRY-MX-4P
S92: A; CHERRY-MX-4P
S93: B; CHERRY-MX-4P
S94: C; CHERRY-MX-4P
S95: *; CHERRY-MX-4P
S96: 7; CHERRY-MX-4P
S97: 8; CHERRY-MX-4P
S98: 9; CHERRY-MX-4P
S99: -; CHERRY-MX-4P
S100: 4; CHERRY-MX-4P
S101: 5; CHERRY-MX-4P
S102: 6; CHERRY-MX-4P
S103: +; CHERRY-MX-4P
S104: 1; CHERRY-MX-4P
S105: 2; CHERRY-MX-4P
S106: 3; CHERRY-MX-4P
S107, S107B: NumEnter; CHERRY-MX-4P
S108: 0; CHERRY-MX-4P
S109: 00; CHERRY-MX-4P
S110: .; CHERRY-MX-4P
STAB_NEN: STAB; ZEALIOS-PCB_2U
SV1: FE09-1; FE09

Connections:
+5V: 3D1.16 (VCC), C1.1, D2.A, R1.2, R2.2, R3.2, R4.1, SV1.9
COLN1: 3D2.12 (O), SV1.2
COLN2: 3D2.6 (O), J15.1
COLN3: 3D2.8 (O), SV1.3
GND: 3D1.4 (G2A), 3D1.5 (G2B), 3D1.8 (GND), 3D2.7 (GND), C1.2, C2.2, LED1.K (C), SV1.1
unnamed: D92.C, D97.C, D98.C, J11.2
unnamed: D100.C, D105.C, J2.1
unnamed: D107.C, JB107.1
unnamed: J1.2, J3.1
unnamed: J1.1, J2.2
unnamed: 3D1.1 (A), SV1.8
unnamed: 3D2.3 (I0), 3D2.4 (I1), 3D2.5 (I2), JA89.2, JA93.2, JA97.2, JA101.2, JA102.2, JA105.2, JA106.2, JA110.2, R2.1
unnamed: 3D1.2 (B), SV1.7
unnamed: D99.C, D102.C, D104.C, J4.1
unnamed: 3D1.3 (C), SV1.6
unnamed: 3D1.13 (Y2), J4.2
unnamed: D96.C, D101.C, J5.1
unnamed: J6.2, J7.1
unnamed: 3D2.1 (I0), 3D2.2 (I1), 3D2.13 (I2), JA88.2, JA92.2, JA96.2, JA100.2, JA104.2, JA108.2, JA109.2, R1.1, S1.2 (S)
unnamed: J5.2, J6.1
unnamed: D88.C, D93.C, D94.C, J9.2
unnamed: 3D2.9 (I0), 3D2.10 (I1), 3D2.11 (I2), J14.1, R3.1
unnamed: 3D1.7 (Y7), J10.1
unnamed: J9.1, J10.2
unnamed: J11.1, J12.1
unnamed: J12.2, J13.1
unnamed: D107.A, J8.2, JA90.2, JA91.2, JA94.2, JA95.2, JA98.2, JA99.2, JA103.2
unnamed: 3D1.9 (Y6), J13.2
unnamed: 3D1.6 (G1), R4.2
unnamed: J8.1, J14.2
unnamed: LED1.A, R5.2
unnamed: J16.2, SV1.5
unnamed: J15.2, J16.1
unnamed: J17.2, SV1.4
unnamed: J17.1, R5.1
unnamed: 3D1.10 (Y5), D87.C, D89.C, D90.C
unnamed: 3D1.11 (Y4), D91.C, J7.2
unnamed: 3D1.12 (Y3), D95.C, J3.2
unnamed: 3D1.14 (Y1), D103.C, D106.C, D108.C
unnamed: D1.A, D2.C
unnamed: 3D2.14 (VCC), C2.1, D1.C
unnamed: JA107.1, S107.SW2 (PIN-2), S107B.SW2 (PIN-2)
unnamed: D104.A, JB104.1
unnamed: D87.A, S1.1
unnamed: D88.A, JB88.1
unnamed: JB88.2, S88.SW1 (PIN-1)
unnamed: JA88.1, S88.SW2 (PIN-2)
unnamed: D89.A, JB89.1
unnamed: JB89.2, S89.SW1 (PIN-1)
unnamed: JA89.1, S89.SW2 (PIN-2)
unnamed: D90.A, JB90.1
unnamed: JB90.2, S90.SW1 (PIN-1)
unnamed: JA90.1, S90.SW2 (PIN-2)
unnamed: D91.A, JB91.1
unnamed: JB91.2, S91.SW1 (PIN-1)
unnamed: JA91.1, S91.SW2 (PIN-2)
unnamed: JB92.2, S92.SW1 (PIN-1)
unnamed: D92.A, JB92.1
unnamed: JA92.1, S92.SW2 (PIN-2)
unnamed: JA93.1, S93.SW2 (PIN-2)
unnamed: JB93.2, S93.SW1 (PIN-1)
unnamed: D93.A, JB93.1
unnamed: D94.A, JB94.1
unnamed: JB94.2, S94.SW1 (PIN-1)
unnamed: JA94.1, S94.SW2 (PIN-2)
unnamed: D95.A, JB95.1
unnamed: JB95.2, S95.SW1 (PIN-1)
unnamed: JA95.1, S95.SW2 (PIN-2)
unnamed: D96.A, JB96.1
unnamed: JB96.2, S96.SW1 (PIN-1)
unnamed: JA96.1, S96.SW2 (PIN-2)
unnamed: JB97.2, S97.SW1 (PIN-1)
unnamed: JA97.1, S97.SW2 (PIN-2)
unnamed: D97.A, JB97.1
unnamed: D98.A, JB98.1
unnamed: JB98.2, S98.SW1 (PIN-1)
unnamed: JA98.1, S98.SW2 (PIN-2)
unnamed: D99.A, JB99.1
unnamed: JB99.2, S99.SW1 (PIN-1)
unnamed: JA99.1, S99.SW2 (PIN-2)
unnamed: D100.A, JB100.1
unnamed: JB100.2, S100.SW1 (PIN-1)
unnamed: JA100.1, S100.SW2 (PIN-2)
unnamed: JB101.2, S101.SW1 (PIN-1)
unnamed: D101.A, JB101.1
unnamed: JA101.1, S101.SW2 (PIN-2)
unnamed: D102.A, JB102.1
unnamed: JB102.2, S102.SW1 (PIN-1)
unnamed: JA102.1, S102.SW2 (PIN-2)
unnamed: D103.A, JB103.1
unnamed: JB103.2, S103.SW1 (PIN-1)
unnamed: JA103.1, S103.SW2 (PIN-2)
unnamed: JB107.2, S107.SW1 (PIN-1), S107B.SW1 (PIN-1)
unnamed: JB104.2, S104.SW1 (PIN-1)
unnamed: JA104.1, S104.SW2 (PIN-2)
unnamed: JB105.2, S105.SW1 (PIN-1)
unnamed: D105.A, JB105.1
unnamed: JA105.1, S105.SW2 (PIN-2)
unnamed: D106.A, JB106.1
unnamed: JB106.2, S106.SW1 (PIN-1)
unnamed: JA106.1, S106.SW2 (PIN-2)
unnamed: JB108.2, S108.SW1 (PIN-1)
unnamed: JA108.1, S108.SW2 (PIN-2)
unnamed: D108.A, JB108.1
unnamed: JB109.2, S109.SW1 (PIN-1)
unnamed: D109.A, JB109.1
unnamed: JA109.1, S109.SW2 (PIN-2)
unnamed: D110.A, JB110.1
unnamed: JB110.2, S110.SW1 (PIN-1)
unnamed: JA110.1, S110.SW2 (PIN-2)
SCK: 3D1.15 (Y0), D109.C, D110.C, JA107.2

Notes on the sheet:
kbn1
kbn2
kbn3
gnd
led_num
vcc

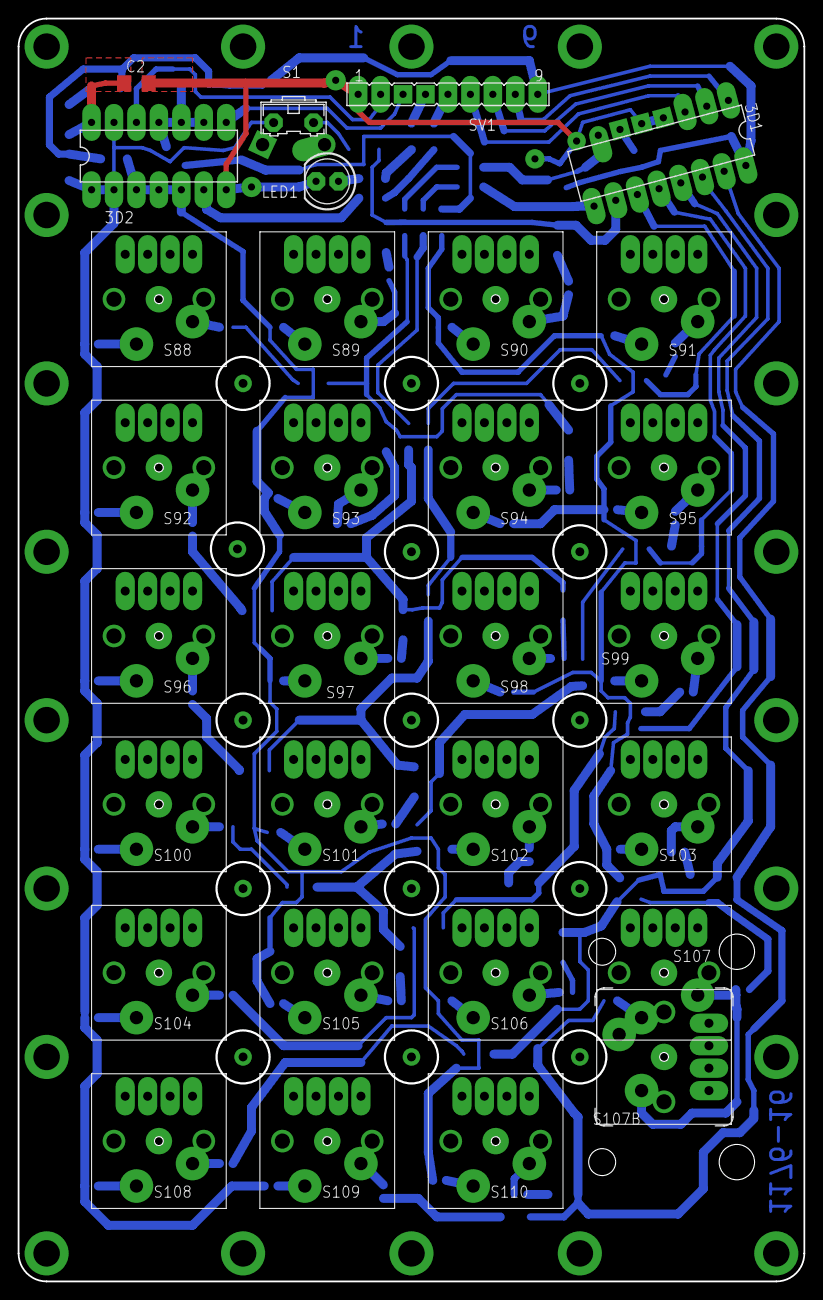
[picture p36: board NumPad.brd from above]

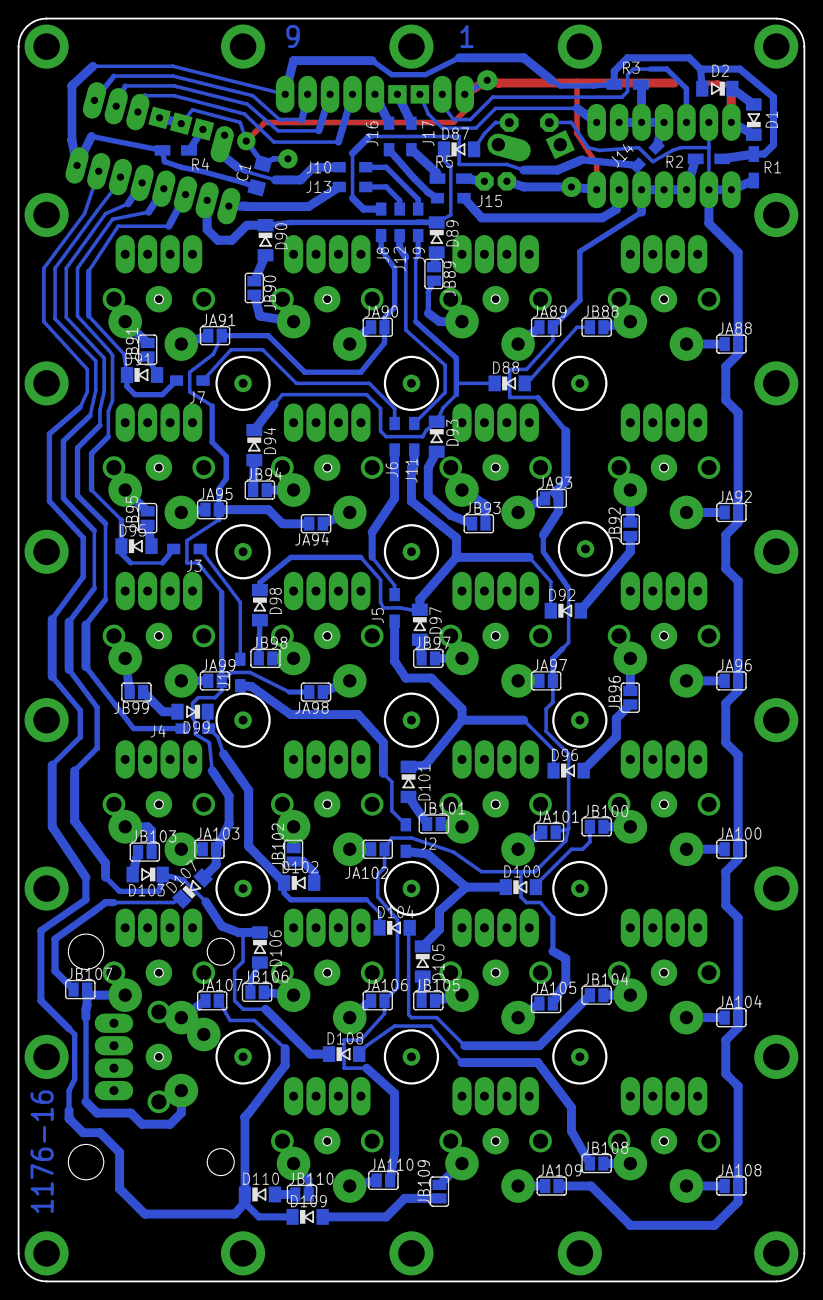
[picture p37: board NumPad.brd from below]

Board: 2 copper layers, 88.9 x 142.9 mm, 175 parts (23 on the bottom side), 111 nets.

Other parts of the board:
U$1, U$88, U$89, U$90, U$91, U$92, U$93, U$94, U$95, U$96, U$97, U$98, U$99, U$100, U$101, U$102, U$103, U$104, U$105, U$106, U$107, U$108, U$109, U$110: 18X18
U$2: NUMENTER
U$3, U$4, U$5, U$6, U$7, U$8, U$9, U$10, U$11, U$12, U$13, U$14, U$15, U$16, U$17, U$18, U$19, U$20, U$21, U$22, U$23, U$24: KEY
U$26: SIZE132
U$111: 37X18

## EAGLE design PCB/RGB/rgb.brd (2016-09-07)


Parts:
DD1, DD2, DD3, DD4: 74HC595D; SO16
IOL7, IOL8, IOL9, IOL10: 8x1F-H8.5; 1X08
JP1: PINHD-1X6; 1X06
R1, R2, R3, R4, R5, R6, R7, R8, R9, R10, R11, R12, R13, R14, R15, R16, R17, R18, R19, R20, R21, R22, R23, R24: R-EU_R0805; R0805

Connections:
+5V: DD1.10 (SCL), DD2.10 (SCL), DD3.10 (SCL), DD4.10 (SCL), JP1.2
GND: DD1.8 (GND), DD1.13 (G), DD2.8 (GND), DD2.13 (G), DD3.8 (GND), DD3.13 (G), DD4.8 (GND), DD4.13 (G), JP1.5
unnamed: DD1.15 (QA), R1.1
unnamed: DD1.1 (QB), R2.1
unnamed: DD1.2 (QC), R3.1
unnamed: DD1.3 (QD), R4.1
unnamed: DD1.4 (QE), R5.1
unnamed: DD1.5 (QF), R6.1
unnamed: DD1.6 (QG), R7.1
unnamed: DD1.7 (QH), R8.1
unnamed: DD3.15 (QA), R9.1
unnamed: DD3.1 (QB), R10.1
unnamed: DD3.2 (QC), R11.1
unnamed: DD3.3 (QD), R12.1
unnamed: DD3.4 (QE), R13.1
unnamed: DD3.5 (QF), R14.1
unnamed: DD3.6 (QG), R15.1
unnamed: DD3.7 (QH), R16.1
unnamed: DD4.15 (QA), R17.1
unnamed: DD4.1 (QB), R18.1
unnamed: DD4.2 (QC), R19.1
unnamed: DD4.3 (QD), R20.1
unnamed: DD4.4 (QE), R21.1
unnamed: DD4.5 (QF), R22.1
unnamed: DD4.6 (QG), R23.1
unnamed: DD4.7 (QH), R24.1
unnamed: IOL7.8, R1.2
unnamed: IOL7.7, R2.2
unnamed: DD2.15 (QA), IOL8.8
unnamed: DD2.1 (QB), IOL8.7
unnamed: DD2.2 (QC), IOL8.6
unnamed: DD1.9 (QH*), DD2.14 (SER)
unnamed: DD2.3 (QD), IOL8.5
unnamed: DD2.4 (QE), IOL8.4
unnamed: DD2.5 (QF), IOL8.3
unnamed: DD2.6 (QG), IOL8.2
unnamed: DD2.7 (QH), IOL8.1
unnamed: IOL7.6, R3.2
unnamed: IOL7.5, R4.2
unnamed: IOL7.4, R5.2
unnamed: IOL7.3, R6.2
unnamed: IOL7.2, R7.2
unnamed: IOL7.1, R8.2
unnamed: IOL9.8, R9.2
unnamed: IOL9.7, R10.2
unnamed: IOL9.6, R11.2
unnamed: IOL9.5, R12.2
unnamed: IOL9.4, R13.2
unnamed: IOL9.3, R14.2
unnamed: IOL9.2, R15.2
unnamed: IOL9.1, R16.2
unnamed: IOL10.8, R17.2
unnamed: IOL10.7, R18.2
unnamed: IOL10.6, R19.2
unnamed: IOL10.5, R20.2
unnamed: IOL10.4, R21.2
unnamed: IOL10.3, R22.2
unnamed: IOL10.2, R23.2
unnamed: IOL10.1, R24.2
unnamed: DD4.9 (QH*), JP1.1
unnamed: DD1.11 (SCK), DD2.11 (SCK), DD3.11 (SCK), DD4.11 (SCK), JP1.3
unnamed: DD1.12 (RCK), DD2.12 (RCK), DD3.12 (RCK), DD4.12 (RCK), JP1.4
unnamed: DD2.9 (QH*), DD3.14 (SER)
unnamed: DD3.9 (QH*), DD4.14 (SER)
REG1: DD1.14 (SER), JP1.6
VCC: DD1.16 (VCC), DD2.16 (VCC), DD3.16 (VCC), DD4.16 (VCC)

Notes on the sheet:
green
ano
blue
red
SER IN
SER OUT
GND
VCC
SCK
RCK

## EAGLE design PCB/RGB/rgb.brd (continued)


Board: 2 copper layers, 51.8 x 42.5 mm, 33 parts (0 on the bottom side), 66 nets.

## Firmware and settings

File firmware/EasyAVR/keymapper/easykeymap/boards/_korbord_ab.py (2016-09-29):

#!/usr/bin/python
# -*- coding: utf-8 -*-
#
# Easy AVR USB Keyboard Firmware Keymapper
# Copyright (C) 2013-2016 David Howland
#
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
# убрана 1 линия для добавления светодиода:
# num_cols заменено 18 на 17 , убрано REF_PORTB 7 #( REF_PORTB , (1 << 7) ),
# добавлено num в led_definition и led_hardware
# изменены линии в keyboard_definition 15 на 14, 16 на 15, 17 на 16 (8 изменений в каждом)
#
# Не удалось определить порты  D3(18) D7(1) Arduino Leonardo . Возможно прошлая смена их отключила.


"""Keyboard definition for Filco HID Lib keyboard"""

import easykeymap.templates.ATmega32U4_16MHz_COSTAR as firmware
from easykeymap.ioports import *

description = "Korbord AB"
unique_id = "AKKBHIDA"
cfg_name = "korbord"

teensy = False
hw_boot_key = True

display_height = int(6.5*4)
display_width = int(20.25*4)

num_rows = 8
num_cols = 17

strobe_cols = False
strobe_low = False

matrix_hardware = [
#     Port mask     Dir mask
    ( 0b10011110 , 0b00001110 ),    # REF_PORTB
    ( 0b11000000 , 0b00000000 ),    # REF_PORTC
    ( 0b11111111 , 0b00000000 ),    # REF_PORTD
    ( 0b00000000 , 0b00000000 ),    # REF_PORTE
    ( 0b11110011 , 0b00000000 )     # REF_PORTF
]

matrix_strobe = [
#     REF_PORTB    REF_PORTC    REF_PORTD    REF_PORTE   REF_PORTF
    ( 0x00       , 0b00000000 , 0b00000000 , 0b00000000, 0b00000000 ),
    ( 0x02       , 0b00000000 , 0b00000000 , 0b00000000, 0b00000000 ),
    ( 0x04       , 0b00000000 , 0b00000000 , 0b00000000, 0b00000000 ),
    ( 0x06       , 0b00000000 , 0b00000000 , 0b00000000, 0b00000000 ),
    ( 0x08       , 0b00000000 , 0b00000000 , 0b00000000, 0b00000000 ),
    ( 0x0A       , 0b00000000 , 0b00000000 , 0b00000000, 0b00000000 ),
    ( 0x0C       , 0b00000000 , 0b00000000 , 0b00000000, 0b00000000 ),
    ( 0x0E       , 0b00000000 , 0b00000000 , 0b00000000, 0b00000000 )
]

matrix_sense = [
# Порядок портов
#      Port        Pin mask
    ( REF_PORTB , (1 << 4) ),
    ( REF_PORTC , (1 << 6) ),    #1
    ( REF_PORTC , (1 << 7) ),
    ( REF_PORTD , (1 << 0) ),    #a2 3
    ( REF_PORTD , (1 << 1) ),
    ( REF_PORTD , (1 << 2) ),    #a3 5
    ( REF_PORTD , (1 << 3) ),    #a4 6
    ( REF_PORTD , (1 << 4) ),
    ( REF_PORTD , (1 << 5) ),    #a5 8
    ( REF_PORTD , (1 << 6) ),    #a6 9
    ( REF_PORTD , (1 << 7) ),
    ( REF_PORTF , (1 << 0) ),
    ( REF_PORTF , (1 << 1) ),
    ( REF_PORTF , (1 << 4) ),    # a1 13
    ( REF_PORTF , (1 << 5) ),
    ( REF_PORTF , (1 << 6) ),
    ( REF_PORTF , (1 << 7) )
]

num_leds = 3
num_ind = 3
num_bl_enab = 2

led_definition = [
    ('Caps LED', 'Caps Lock'),
    ('Scroll LED', 'Scroll Lock'),
    ('Num LED', 'Num Lock')
]

led_hardware = [
#       Port    Pin    Direction
    ( REF_PORTB, 5, LED_DRIVER_PULLDOWN ),
    ( REF_PORTB, 6, LED_DRIVER_PULLDOWN ),
    ( REF_PORTB, 7, LED_DRIVER_PULLDOWN )
]

backlighting = False

bl_modes = [
    ( 0, 0 ),
    ( 1, 1 )
]

KMAC_key = None

# номер порта дешифратора | выход дешифратора | номер порта в коде
# Y0 = 15 = 0  
# Y1 = 14 = 4  
# Y2 = 13 = 2
# Y3 = 12 = 6
# Y4 = 11 = 1
# Y5 = 10 = 5
# Y6 = 9  = 3
# Y7 = 7  = 7 
#
# pins
# arduino        in_logic
#  |   avr           |      out_logic
#  |    |  port_avr  |         |   port_fw
#  |    |    |       |         |      |
# A0 = 36 = PD2 - 3,4,5   != 3D2_6  = 16 kbn3
# A1 = 37 = PD3 - 9,10,11 != 3D2_8  = 15 kbn2
# A2 = 38 = PD1 - 1,2,13  != 3D2_12 = 14 kbn1
# A4   40                             12 kbb1 
# D6   27                             10 kbb2
# D5   31   PC6                        1 kbb3
# D4   25   PD4                        7 kbb4    (x,7)
# A5   41                             11 kbb5
# D2   19   PD1                        4 kbb6
# D3(18) D7(1)  ? не нашёлся                                    
#
# D3    18  PD0                        3 kba2
# D0    20  PD2                        5 kba3
# D1    21  PD3                        6 kba4
# TxLED 22  PD5                        8 kba5
# D12   26  PD6                        9 kba6
# A3    39  PF4                       13 kba1

# keyBoard A (PCB_A) 
# порт в коде               0      4      2      6      1      5     3     7
# pin | signal  |col_kba|  15  |  14  |  13  |  12  |  11  |  10  |  9  |  7    fw port
# 1     gnd
# 2      L5      kba1      Z      C      X   L_Shift          B      G     V    13
# 3      L6      kba2    Down    Caps  Right    Up    Left  L_Alt L_Space  FN1  3
# 4      L2      kba3     ~Ё      2      1    Pause    Ins    4      5     3    5
# 5      L3      kba4     Tab     W      Q     PgUp   Home    R      6     E    6
# 6      L1      kba5     F1      F3     F2    Esc   Scroll   F5     F6    F4   8
# 7      L4      kba6    L_Ctrl   S      A     PgDn    End    F      T     D    9
# 8     vcc
# z dn  lcrtl tab ~ f1 
# 1 D1   miso
# 2 D2   mosi
# 3 D3   sck
#
# keyBoard B (PCB_B) 
# порт в коде               0      4      2      6      3     5      1     7
# pin | signal  |col_kbb|  15  |  14  |  13  |  12  |  9  |  10   |  11 |  7
# 1  gnd
# 2   !9>8        kbb1     F9     F8     N    R_Space   7     Y      H      F7
# 3  !11>10       kbb2     F12    =    R_ALT    FN3    [{     "'     /?     ]}
# 4  !13>12       kbb3   Delete BSpace R_Ctrl PrtScr  Enter d \|  R_Shift  u \|
# 5   !1>2        kbb4     0      9      M      ,<      U     J      K      8
# 6   !3>4        kbb5                                  L     Ii            Oo
# 7   !5>6        kbb6     F10    F11    .>     FN2     P     ;:     `~     -_
# 8   d1    miso
# 9   d2    mosi
# 7   d3    sck
# 11 vcc
#
# NumPad
# pin | signal  |col_kbn|  15  |  14  |  13  |  12  |  11  |  10  |  9   |  7
# 1     gnd
# 2  i12 1.2.13   kbn1     P00    P0     P1     P4     P7   NumLock  PA     PD
# 3  i8  9.10.11  kbn2  P_Enter   P+     P-     P*     P/     PF     P9     PC
# 4     led_num
# 5  i6  3.4.5    kbn3     P.     P3     P6     P2     P5     PE     P8     PB
# 6   d3    sck
# 7   d2    mosi
# 8   d1    miso
# 9 vcc
#
# (горизонталь кнопки, вертикаль кнопки), (?выходы дешифратора, входы контролера)
#                                                               fw port
keyboard_definition = [
[
(72, None, '0'),
((4, 4), (5, 14), 'HID_KEYBOARD_SC_NUM_LOCK')                 #OK
],[
((4, 4), (1, 8), 'HID_KEYBOARD_SC_SCROLL_LOCK'),
((4, 4), (6, 8), 'HID_KEYBOARD_SC_ESCAPE'),
(3, None, '0'),
((4, 4), (0, 8), 'HID_KEYBOARD_SC_F1'),
((4, 4), (2, 8), 'HID_KEYBOARD_SC_F2'),
((4, 4), (4, 8), 'HID_KEYBOARD_SC_F3'),
((4, 4), (7, 8), 'HID_KEYBOARD_SC_F4'),
(2, None, '0'),
((4, 4), (5, 8), 'HID_KEYBOARD_SC_F5'),
((4, 4), (3, 8), 'HID_KEYBOARD_SC_F6'),
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

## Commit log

2016-07-22 add led.c
    [Keyboard.brd, NumPad.brd, NumPad.sch]
2016-07-23 pcb np
    [NumPad.brd, NumPad.sch]
2016-07-23 num src
    [NumPad.brd, NumPad.sch]
2016-07-24 edit map
    [NumPad.brd, NumPad.sch]
2016-07-29 + stab reserv
    [NumPad.brd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]
2016-07-29 f np1
    [NumPad.brd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]
2016-08-01 move 3
    [NumPad.brd, NumPad.sch]
2016-08-04 move 2 fw
    [BoardDeviceMap.cfg, BootloaderDeviceMap.cfg, costar104.cfg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]
2016-08-05 add ry caps
    [NumPad.brd]
2016-08-05 del 1 wire
    [Keyboard.brd, Keyboard.sch]
2016-08-06 move +m2
    [Keyboard.brd, Keyboard.sch, NumPad.brd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]
2016-08-15 get all vil
    [Keyboard.brd, Keyboard.sch, NumPad.sch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]
2016-08-16 fix b
    [NumPad.brd, keyBoard_B.brd, keyBoard_B.sch]
2016-08-17 pcb b
    [NumPad.brd, keyBoard_B.brd, keyBoard_B.sch]
2016-08-17 add kesize table. bad pcb a b
    [keyBoard_A.brd, keyBoard_A.sch, keyBoard_B.brd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]
2016-08-18 new pcb >
    [keyBoard_A.brd, keyBoard_A.sch, keyBoard_B.brd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]
2016-08-18 pcb b > ab
    [keyBoard_A.brd, keyBoard_A.sch]
2016-08-18 pcb b > ab .2
    [keyBoard_A.brd, keyBoard_A.sch]
2016-08-18 pcb new b ab
    [NumPad.brd, NumPad.sch, keyBoard_A.brd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]
2016-08-18 pcb b ok
    [keyBoard_A.brd, keyBoard_A.sch, keyBoard_B.brd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]
2016-08-18 b pl mod
    [keyBoard_A.brd, keyBoard_B.brd, keyBoard_B.sch]
2016-08-19 new pcb b
    [keyBoard_A.brd, keyBoard_A.sch, keyBoard_B.brd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]
2016-08-19 del old
    [Keyboard.brd, Keyboard.sch, keyBoard_B.brd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]
2016-08-20 cont fe11s
    [Controller.brd, Controller.sch, keyBoard_A.brd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]
2016-08-21 pcb b mov det
    [Controller.brd, Controller.sch, keyBoard_B.brd]
2016-08-22 b d1 d1 sw
    [Controller.sch, keyBoard_B.brd, keyBoard_B.sch]
2016-08-22 sh c
    [Controller.brd, Controller.sch]
2016-08-23 fw add
    [Controller.brd, Controller.sch]
2016-08-23 pcb c
    [Controller.brd, Controller.sch]
2016-08-24 new pcb a >
    [keyBoard_A.brd, keyBoard_A.sch]
2016-08-24 pcb b old. pcb a ver txt
    [keyBoard_A.brd, keyBoard_A.sch, keyBoard_B - копия.brd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]
2016-08-26 pcb a n>
    [keyBoard_A.brd, keyBoard_A.sch]
2016-08-26 pcb a 2
    [keyBoard_A.brd, keyBoard_A.sch]
2016-08-26 pcb a 3
    [Controller.sch, keyBoard_A.brd, keyBoard_A.sch]
2016-08-26 pcb a 4
    [keyBoard_A.brd, keyBoard_A.sch]
2016-08-27 pcb c new progr >
    [keyBoard_A.brd]
2016-08-27 sw ls
    [keyBoard_A.brd, keyBoard_A.sch]
2016-08-27 sw s10
    [keyBoard_A.brd, keyBoard_A.sch]
2016-08-27 pcb a r
    [keyBoard_A.brd, keyBoard_A.sch]
2016-08-28 pcb a
    [Controller.brd, keyBoard_A.brd, keyBoard_A.sch]
2016-08-28 pcb a +
    [keyBoard_A.brd]
2016-09-18 vil_36 new log on
    [Controller.brd, Controller.sch]
2016-09-29 pcb abn ok
2016-10-25 копейки
    [Controller.brd, Controller.sch, keyBoard_A.brd]
2017-01-14 del tmk
    [BoardDeviceMap.cfg, BootloaderDeviceMap.cfg, master.cfg]
2017-01-19 fw mov
    [costar104.cfg, costar87.cfg, gh122.cfg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]
2018-08-05 add stab pcb a
    [keyBoard_A.brd, keyBoard_A.sch]
2018-08-07 add b
    [keyBoard_B.brd, keyBoard_B.sch]
2018-08-13 kb swap
    [keyBoard_A.brd, keyBoard_A.sch]

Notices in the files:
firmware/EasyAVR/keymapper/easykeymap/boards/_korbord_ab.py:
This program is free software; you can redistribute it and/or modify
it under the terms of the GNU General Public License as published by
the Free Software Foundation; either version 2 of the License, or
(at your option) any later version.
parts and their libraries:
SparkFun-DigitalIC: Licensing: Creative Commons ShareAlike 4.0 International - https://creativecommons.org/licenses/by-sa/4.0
